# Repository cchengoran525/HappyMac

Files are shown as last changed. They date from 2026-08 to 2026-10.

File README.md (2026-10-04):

<div align="center">
  <picture>
    <source media="(prefers-color-scheme: dark)" srcset="assets/happymac_banner_dark.svg">
    HappyMac — 一枚会陪你熬夜的赛博小生命
  </picture>
</div>

<br>

<div align="center">
  <a href="firmware/happymac_v0/接线清单.md">接线清单</a> |
  <a href="firmware/happymac_v0/元件尺寸台账.md">元件尺寸台账</a> |
  <a href="firmware/happymac_v0/README.md">固件文档</a> |
  <a href="simulator/happymac_sim.html">模拟器</a> |
  <a href="firmware/power_test/power_test.ino">电源测试</a> |
  <a href="hardware/happymac_v01.stl">外壳 STL</a>
</div>

<br>

<div align="center">
  
  
  
  
  
  
</div>

<br>

> 一个吸附在书桌背景板上的赛博小生命体。  
> 它不是工具，它只是在陪着你。

---

## 项目愿景

HappyMac 是一枚桌面像素交互小宠物，形态为冰箱贴。它极度克制、省电，平时几乎沉默，但在你需要的瞬间，能给出精准而温柔的回应。

它有自己的作息，有自己的情绪，会在你深夜还没睡的时候困着眼撑着陪你，也会在你发现它睡着的瞬间上演一出惊慌失措的假装没睡。

没有摄像头，没有麦克风，只有热量和微波的反射——它用这两样东西感受你的存在。

---

## 当前版本：固件 v0.1

- 像素脸表情系统：眉/眼/嘴形态化（挑眉、单眉好奇、wink、开心 ^、皱眉），特殊表情带冷却机制；
- 四阶段深度省电：互动 → 睡眠（呼吸暗脸）→ 90s 断雷达红外独守 → 关屏 / 30min 深度睡眠（SR602 唤醒）；
- 榫卯零螺丝外壳设计定稿：接线与元件尺寸见 [firmware/happymac_v0/](firmware/happymac_v0/)；
- 模拟器与固件 1:1 同步（[simulator/happymac_sim.html](simulator/happymac_sim.html)）。

---

## 硬件架构

```
┌─────────────────────────────────────┐
│  OLED 1.3"  SH1106  128×64          │  ← 像素脸输出
│  ESP32-C3 SuperMini                 │  ← 核心大脑
│                                     │
│  能量分级感知系统                      │
│  ├─ 第一级：SR602 红外传感器           │  ← 哨兵，平时深度休眠
│  ├─ 第二级：LD2410C 毫米波雷达         │  ← 微动/能量/呼吸感知
│  └─ 第三级：LD2450 毫米波雷达          │  ← X/Y 双目标追踪
│                                     │
│  电源管理                            │
│  ├─ TP4056 双输入充电（USB-C + 太阳能）│
│  ├─ SS14 防反流二极管                 │
│  └─ AO3401 高侧开关（雷达电源门控）     │
└─────────────────────────────────────┘
```

### 为什么是两个雷达

LD2410C 和 LD2450 分工不同，互相不可替代：

| 传感器 | 擅长 | 在本项目中的角色 |
|---|---|---|
| LD2410C | 微动能量、呼吸、静止检测 | 判断用户状态（专注/发呆/睡着） |
| LD2450 | X/Y 坐标、多目标追踪、速度 | 判断用户位置和大幅度动作 |

---

## 交互设计

### 伪 3D 视差跟随

HappyMac 的脸由三个层次构成：双眼、鼻子、嘴巴。当用户位置偏移时，三个层次以不同幅度位移，形成视差效果：

```
用户向左移动时：
  鼻子  移动 ±6px   （最前层，移动最大）
  眼睛  移动 ±4px   （中层）
  嘴巴  移动 ±2px   （最后层，移动最小）
```

在 2D 屏幕上实现"它在转头盯着你"的视觉感受，无需 3D 硬件。

### 状态机

```
用户出现         → 慢慢从睡眠中醒来
用户看它         → 惊喜/脸红/眼睛睁大
用户发呆         → 跟着一起发呆，眼神涣散
用户长时间不理   → 打哈欠 → 揉眼 → 亮度渐暗 → 睡眠呼吸动画
深夜用户还在     → 困意动画，但撑着陪你
用户离位         → 目送 → 等待 → 睡着
被发现在睡觉     → 惊醒 → 假装没睡
```

### 睡眠状态的设计原则

全黑 = 坏掉了。HappyMac 睡着时：
- 亮度降至 20%，不是 0
- 慢速呼吸闪烁，表示有生命迹象
- 有人靠近时先有微小反应，再慢慢睁眼

---

## TinyML 训练路径（盲眼剑客计划）

最终产品绝对不包含摄像头，但训练阶段需要视觉作为 Ground Truth。

### 三步走

**第一步：师徒结对（数据采集）**

引入电脑摄像头作为"上帝视角"。MediaPipe 实时识别头部姿态和注视方向，自动打标签；同步记录同一时刻的雷达波形和红外特征。标注过程完全自动，用户正常使用电脑即可完成被动采集。

**第二步：炼丹提取（模型训练）**

将多模态数据输入神经网络，训练两个独立模型：

```
模型 A：位置动作分类
  输入：LD2450 的 X/Y + 帧间变化量
  输出：坐下/站立/前倾/后靠/左偏/右偏
  驱动：HappyMac 脸的朝向

模型 B：用户状态分类
  输入：LD2410C 能量值 + LD2450 速度辅助
  输出：专注/活跃/发呆/睡着/离位
  驱动：HappyMac 表情 + 屏幕亮度
```

两个模型时间尺度不同，分开训练，通过优先级仲裁层协同工作。

**第三步：过河拆桥（边缘部署）**

将模型量化部署进 ESP32-C3，彻底拔掉摄像头。设备仅凭热量和微波反射，凭直觉感受主人的目光。

---

## 当前进度

### 硬件验证
- [x] ESP32-C3 基础环境搭建
- [x] SH1106 OLED 驱动（U8g2）
  - OLED 显示：raw 诊断 + EMA 滤波大字 + 俯视图
  - EMA α=0.55，端到端延迟 ~400ms（雷达 100ms + EMA 200ms + OLED 80ms）
- [x] LD2410C 跑通，微动能量读取正常
- [x] SR602 红外传感器联通
- [x] TP4056 双输入电源管理（USB-C + 太阳能）
- [x] **LD2450 跑通，X/Y 坐标解析正确**
  - 协议符号解码修正（bit15=1→正，bit15=0→负）
  - EMA 滤波（α=0.55）平滑显示
  - 串口 CSV 输出（RADAR 格式，可直接接入采集脚本）
  - OLED 阶段指令支持（电脑通过串口发 `!PHASE` 命令）
  - ⚠️ **X 轴慢漂为硬件固有限制**（见下方"LD2450 X 轴漂移"章节）
- [x] **S3 摄像头固件重写**（s3_camera.ino）
  - AP 模式热点直连（HappyMac-S3 / 12345678）
  - MJPEG /stream + /capture + /status + /control
  - ESP32-S3-EYE 适配（16MB Flash / OPI PSRAM）

### 实测发现

#### LD2450：正确安装后 X/Y 基础功能可用

- **正确安装方式**：PCB 竖直，天线阵列水平（与网上视频一致）
- **方向**：左移 X 减小，右移 X 增大（raw 数据）。OLED 显示已镜像，直觉一致
- **STILL σ≈107mm**：静止时 X 仍有慢漂（LD2450 固有限制，社区公认）
- **SWEEP σ≈222mm**：缓慢左右扫动信号是静止漂移的 2.1x——雷达能区分运动和静止
- **帧间精度**：静止时 ΔX 中位 1-2mm，但长时漂移可达 300-500mm
- **校准**：用户居中时 X≈0，偏左为负，偏右为正

#### LD2410C：静止检测正常，移动检测偏弱

- **Es>0 约 100%**：始终能检测到静止目标
- **Em 响应弱**：默认灵敏度阈值偏高，即使前后移动也难以触发
  - 固件已调高 gate 0-3 灵敏度至 80/100，但改善有限
  - 可能需要 HLKRadarTool app 手动配置

#### USB 供电噪声

- S3 和 C3 插同一台电脑时，C3 雷达数据严重劣化（Yσ 从 29mm → 290mm）
- 解决方案：S3 走 WiFi AP 模式，不与 C3 共用 USB 总线

#### 摄像头-雷达时间戳对齐

- 软件同步（SYNC 握手）未能精确对齐——两个独立时钟，相关分析始终 r≈0
- 需硬件同步：一根 GPIO 线让 C3 触发 S3 录像，或共用同一个外部时钟源
- **但对 TinyML 影响有限**：雷达数据本身（Y 准、X 趋势可用、Es 稳定）已经足够训练

### 已完成（TinyML T1/T1b）
- [x] **TinyML 首次实验（T1b）**：5 类行为分类（离场/静止/左右动/凑近/远离）
  - 视觉 Teacher 自动打标签跑通（MediaPipe + MiDaS）
  - 融合训练在自然行为上 acc=0.811 / F1=0.765（⚠️ 随机切分，诚实值见下条）
  - **发现：Es 数值是头号特征（重要性 0.346）**
  - **教训：协议数据训练的模型迁移到自然场景崩溃（0.32），必须混入自由数据**
  - 详见 `training/README.md` T1 章节
- [x] **对齐数据集诚实评估（2026-08-30）**：详见 `training/README.md`「T1b 对齐数据集与诚实评估」
  - **LOSO 诚实值：acc=0.563 / macro-F1=0.462**——0.811 是同 session 内窗口互相泄漏的假象，引用一律以 LOSO 为准
  - 模型阶梯（树 d3-d5 / RF 10-120t）LOSO 全挤在 0.49-0.56：**瓶颈在特征不在模型**
  - **转头可分性 V1 基线：召回 54%、打字误报 28%**——未达 V2 验收门（>75% / <10%），维持"小幅动作归 STILL"
  - 专注 vs 发呆窗口级互混 ~50%，降级为 Es 长窗氛围调制
  - 分类→检测通道→动画映射已定案（见 `training/README.md` 与固件 README）

### 已完成（T1b v0 部署 + 离线闭环，2026-08）
- [x] **T1b aligned v0 决策树上 C3**：`firmware/happymac_v0` 内嵌 `tinyml_v0_tree_d4.h`，2s 窗 9 特征现场推理，2000ms 确认 + v 特征噪声底
- [x] **静坐误笑治理**：运动证据积分+施密特触发、Y 趋势武装滞回、笑容 600ms 进入延迟+1.5s 保持——真实数据评测误笑率 32.5%→16.6%
- [x] **一次性事件动画系统 + 睡前过渡链**：无人后 打哈欠→揉眼→渐暗→入睡，随时打断（本 README「状态机」愿景第一条落地）
- [x] **离线开发闭环 `simulator/`**：固件逻辑 1:1 JS 移植的等比例 OLED 模拟器 + 16 项场景断言 + 真实数据回放评测——参数改动先离线验证再上机
- [x] **V1 数据体检 + V2 采集规范**：8 会话只读评估（视频倒装/Es 漂移/LATERAL 稀缺/em 报废），规范见 `training/DATA_COLLECTION_V2.md`

### 下一步清单（2026-08-30 更新；半年路线图见 [ROADMAP.md](ROADMAP.md)）

**产品线**
1. [ ] 外壳定稿与组装——解锁 V2 正式采集的前置条件
2. [ ] 电池续航优化（803040 实测十多小时，送人前需再压）
3. [ ] 装壳后阈值现场校准

**数据线**（规范见 `training/DATA_COLLECTION_V2.md`）
4. [ ] 采集固件三处改动：2410 灵敏度 40/40、3 目标 CSV、FW_VERSION 入 meta
5. [ ] V2 正式采集 ≥2 轮（规则+自由+空桌基线，新增 turn_toward / big_sway / still_near-far 动作块）
6. [ ] 转头可分性验收：HEAD 召回>75% 且打字误报<10% 才加新类重训，否则维持"小幅动作归 STILL"
7. [ ] 重训后评测目标：静坐误笑率 <10%

**学术线（Paper 1）**
8. [ ] 双雷达同频干扰定量 AB 测试（3 轮）
9. [ ] 雷达极限探查：5 距离 × 4 行为曲线
10. [ ] RF → MLP 蒸馏 → INT8 量化部署链（与 V2 重训合并执行）

**离线研究（无硬件，随时可做）**
11. [ ] RQ2.3 特征消融：特征组移除 × LOSO（模板 = `training/exp_head_separability.py`）
12. [ ] 窗口长度扫描：1/2/3/5s × LOSO，攻 STILL↔LATERAL 互混
13. [ ] RQ2.1 教师天花板：8 个 V1 会话 mp4 已存 + `t_video_rel` 时间戳，可离线重跑 MediaPipe + keypoint MLP
14. [ ] RQ3.2 pilot：概率 vs 二值表情 A/B（固件加 DETERMINISTIC_MODE 开关，3-5 人 Likert；原型稳定后）

---

## 文件结构

```
HappyMac/
├── README.md
├── new_radar/
│   └── new_radar.ino        # C3 固件：双雷达采样 + EMA 滤波 + OLED + 串口 CSV + 阶段指令
├── s3_camera/
│   └── s3_camera.ino        # S3 固件：AP 热点 MJPEG /stream + /capture + /status + /control
├── CameraWebServer/          # [参考] ESP32-CAM 官方示例，保留备用
├── firmware/
│   └── happymac_v0/         # 产品固件 v0：7 状态机 + 动画 + TinyML 部署 + 睡前链
├── simulator/
│   └── happymac_sim.html    # 网页模拟器：固件逻辑 1:1 移植 + 离线评测闭环
├── training/
│   ├── README.md            # TinyML 管线设计文档 + 11个研究问题 + 3条Paper线
│   ├── DATA_COLLECTION_V2.md # 装壳后正式数据采集规范（V2）+ V1 体检问题追踪
│   ├── config.py            # 全局配置
│   ├── collect.py           # 数据采集（MediaPipe + S3 MJPEG + C3 串口）
│   ├── preprocess.py        # 特征工程 + 标签生成
│   ├── train.py             # RF 验证 → MLP 训练 → INT8 量化 → C 头文件
│   ├── live_test.py         # Webcam + 雷达同步测试
│   ├── s3_test.py           # S3 MJPEG + 雷达同步采集
│   ├── cam_test.py          # 摄像头 + 雷达同步录制（产出 mp4 + csv）
│   ├── full_test.py         # ANSI TUI 完整基准测试
│   ├── radar_bench.py       # 3配置×4阶段雷达基准
│   ├── requirements.txt     # Python 依赖
│   ├── sessions/            # 采集原始数据（.csv）
│   ├── models/              # 训练产物（.npy / .h5 / .tflite / .h）
│   └── bench_results/       # 基准测试结果（.json / .mp4 / .csv / .png）
└── firmware/                # 计划中：主程序（状态机 + 动画）
```

---

## 已知限制与开放问题

### 双雷达同频干扰

LD2410C 和 LD2450 均在 24GHz ISM 频段工作，两台雷达同时开启时会产生**双向电磁干扰**：

| 干扰方向 | 影响 |
|---|---|
| LD2450 → LD2410C | 底噪抬高 3-10dB，远距离检测灵敏度下降 |
| LD2410C → LD2450 | 相位干涉精度下降，X 轴坐标漂移加剧 |

**无法通过软件分时解决：** 两个雷达模块均不支持休眠/唤醒指令。断电重启需要数秒的启动+校准时间，无法在采集周期（100ms）内完成切换。硬件 MOSFET 电源门控（AO3401 + GPIO）是实现真正分时的唯一方案，目前尚未实施。

### X 轴精度与距离的耦合

LD2450 的 X 坐标通过两天线相位干涉计算（天线基线 ~6mm）。X 精度正比于目标距离：
- **< 0.5m：** X 基本为噪声，仅能做"左/中/右"粗分类
- **0.5-1m：** X 可用但漂移显著（σ≈200-1000mm）
- **> 1m：** 角分辨率进入可用区间

### 学术界与实践空白

在 **24GHz 低成本双雷达（<50 元）+ TinyML 跨模态蒸馏（视觉→雷达）** 这个细分领域，目前没有找到直接对标的论文或开源项目：

- LD2410/LD2450 DIY 社区项目均使用纯阈值规则，无 ML
- 60GHz+ 雷达的 TinyML 研究使用高分辨率热力图输入（CNN/Transformer），与本项目的 18 维时序标量特征（MLP）不可比
- 唯一的相近硬件栈论文（DOAJ, 2024）做的是"雷达触发→ESP32-S3 推理人脸识别"，不是行为分类

**本项目从数据采集到模型部署的完整跨模态蒸馏管线（collect.py → preprocess.py → train.py → C 头文件 → C3 推理）为自行设计，无成熟参考架构。**

### TinyML 管线限制

- **MediaPipe 标签质量**：训练标签来自 MediaPipe 面部网格的几何推导（头部位姿、注视方向），不是人工标注。标签存在系统性偏差
- **ESP32-C3 推理性能**：RISC-V 核心无 SIMD 指令扩展，MLP 推理约 <10ms（2 层, <2K 参数），但无法运行 CNN 类模型。如需更复杂模型，需迁移至 ESP32-S3（ESP-NN 加速 42x）
- **数据采集一次性**：相机仅存在于训练期。如果雷达安装位置/朝向改变，需要重新采集数据

---

## TinyML 管线

```
training/
├── config.py           # 全局配置（特征列表、窗口参数、标签定义等）
├── collect.py          # 数据采集：S3 视频流 + C3 串口 + MediaPipe 标注
├── preprocess.py       # 特征工程：滑动窗口 + 18 维特征提取 + 标签生成
├── train.py            # 训练：RF 快速验证 → MLP 训练 → INT8 量化 → C 头文件
├── requirements.txt    # Python 依赖
├── face_landmarker_v2_with_blendshapes.task  # MediaPipe 模型（首次运行时自动下载）
├── sessions/           # 原始采集数据（CSV）
└── models/             # 训练产物（.npy, .h5, .tflite, .h）
```

### 数据流

```
[采集]  collect.py
  S3 MJPEG 视频流 ──→ MediaPipe Face Landmarker ──→ 头部位姿 + 注视方向 + 眼部开合
  C3 USB 串口     ──→ LD2450(X/Y/V) + LD2410C(Em/Es) + SR602 ← 时间对齐 → 一行 CSV

[处理]  preprocess.py
  原始 CSV → 滑动窗口(2s/5s) → 18维特征向量 → 模型A标签(8类) + 模型B标签(8类)
  → X_a.npy / y_a.npy / X_b.npy / y_b.npy

[训练]  train.py
  Random Forest 验证(准确率>85%才继续) → MLP(32→16→softmax) → INT8 量化 → model_*.h
```

---

## 设计哲学

> 它不应该每天都需要你。  
> 但当你抬头的那一刻，它刚好也在看你——  
> 这就够了。

隐私优先：无摄像头，无麦克风，无联网，无云端。感知只发生在本地，数据从不离开桌面。

省电优先：三级唤醒结构，绝大多数时间处于深度休眠。太阳能辅助充电，真正的低打扰存在。

克制优先：去掉所有工具属性（无时钟、无天气、无通知推送），只保留陪伴本身。

---

## 开发环境

- Arduino IDE 2.x + ESP32 Arduino Core
- Python 3.10+（采集脚本）
- MediaPipe（视觉辅助标注）
- Edge Impulse / PyTorch（模型训练）

---

*HappyMac 是一个正在成长中的项目。它现在还不完整，就像所有刚出生的小东西一样。*

---

*本项目为个人非商业开源作品，与 Apple Inc. 无任何关联；Mac 是 Apple Inc. 的商标。*

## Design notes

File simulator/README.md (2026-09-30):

# HappyMac OLED 模拟器

无硬件时的开发验证环境：在浏览器里 1:1 复现 `firmware/happymac_v0` 的完整逻辑链路
（状态机 / 运动证据积分 / Y 趋势武装滞回 / TinyML 决策树 / 动画层），并以
128×64 等比例、整数倍放大渲染 1.3″ SH1106 OLED 画面（旁边附真实物理尺寸预览）。

## 打开方式

直接双击 `happymac_sim.html`（单文件、无依赖、file:// 可用），或：

```bash
open happymac_sim.html
```

## 能干什么

| 用途 | 做法 |
|---|---|
| 调动画/阈值参数 | 改文件顶部 `FW` 常量区（与固件 `#define` 一一对应），确认效果后再手动同步回 `.ino` |
| 验证防抖修复 | 勾选「旧版单帧判定」复现修复前的笑容横跳，关掉即当前固件行为 |
| 回放真实数据 | 「CSV 回放」选 `training/sessions/*.csv`（`t_global,x,y,v,em,es` 格式），真实雷达数据驱动同一套动画 |
| 快速过全状态 | 「场景剧本」：静坐 / 凑近 / 左右探头 / 离开回来（含睡前链）/ 深夜静止 / 贴脸强噪声 |
| 看睡前过渡链 | 「离开→回来」剧本：无人 2.5s 后打哈欠→揉眼→渐暗→入睡，人回来随时打断；串口面板有 `EV,` 日志 |
| 预览配饰方案 | 勾选「半框眼镜」给 OLED 脸戴上 1px 横向半框眼镜（纯渲染层开关，只在 `drawGlasses`；若定稿可把同样画法平移进固件动画层） |
| 与真机对拍 | 串口面板输出与固件相同的 `STATE/ML/POS/RADAR/ANIM` 日志格式 |

## 噪声模型（按实测标定）

- LD2450 实际输出 ≈15Hz（采集 CSV 中位间隔 67ms；旧固件因 OLED 重绘拖慢，处理速率仅 ≈7.6Hz）；
- 静态噪声为慢漂移：边际 σ≈100mm@0.7m，帧间相关 ρ≈0.997，
  对应静坐时滤波步进（140ms）中位数 ≈5.5mm（2026-08-29 实测）；
- 速度 v 静坐时中位数为 0，仅 0.7~3.1% 的行出现 8 的倍数尖峰（跟踪器毛刺）。

## 测试

```bash
node test_sim.js          # 场景断言（固定种子，可复现）
node eval_replay.js       # 真实数据评测：回放全部采集 CSV，对比固件状态 vs 真实动作标签
node eval_replay.js --deglitch   # 同上，但先剔除 v 毛刺帧（对照实验）
node eval_replay.js path/to/session.csv  # 只评单个会话
```

评测口径：still/typing/head_only 期望 IDLE（期间 ACTIVE = 误笑）；
运动类期望 ACTIVE（动作间停顿 IDLE 也算对）；每段动作切换后 2.5s 过渡宽限不计分；
`free_5min` 无期望状态不计分；8 月 13 日后会话优先使用视频对齐后的 `aligned_action`。

从 HTML 中抽出核心逻辑在 Node 里无头运行，覆盖：凑近触发 APPROACH、
静坐 90s 强噪声不横跳（新旧判定对照）、离场 GOODBYE→SLEEP、
TinyML 决策树输出对拍、OLED 帧缓冲冒烟。

页面控制台另有 `__sim.state()` 调试钩子可查运行时状态。

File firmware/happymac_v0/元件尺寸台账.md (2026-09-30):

# 元件尺寸台账（实测/商品页，2026-09-27）

> 建模基准数据。Fusion 中的同名 User Parameters 以此为准；新元件到手先记这里再建模。

| 元件 | 尺寸 (mm) | 关键接口/备注 |
|---|---|---|
| **电池 606090** | 90 × 60 × 6 | 3.7V 4000mAh，**自带保护板** ✓；三线（红+黑+第三线待判别，疑 NTC） |
| **稳压模块** | 25 × 17.5 × 4.5 | VIN 1.8~5.5V（可直挂电池）；OUT 跳线选 5V/4.2V/3.3V；**EN 低=关**；**PS 短接+去LED = 待机 <100µA** ★省电新选项；常规待机几~十几 mA |
| **LD2450** | 40 × 15（厚约4） | 6 天线；串口 256000/8N1（与固件一致）✓ |
| **F5305S 开关模块** | 46 × 25（高约20 含端子） | 13.3g；三组端子共 6 位（IN±/OUT±/控制±） |
| **OLED 1.3" SH1106** | 35.4 × 33.5 × 11.3（含排针） | 活动区 **29.42 × 14.7**；四角安装孔 **内径3/外径4.5**（M3 直接螺丝固定前脸板）✓；孔边距 2.5mm |
| **ESP32-C3 SuperMini** | 18 × 22（排针距 15.24） | USB-C 在上沿；5V/G/3V3 + GPIO |
| **充电+保护二合一** | 28 × 17 | 5V 1A；截止 4.2V；**过放 2.5V / 过流 3A** ✓（安全清单：保护确认） |
| **拨动开关**（全局电源） | 8.5 × 3.5（高7.2） | 0.5A / 30mΩ（负载侧电池电流 ~330mA ✓） |
| **LD2410C** | 22 × 16 | HLK-LD2410C-V1.0；右侧引脚 VIN/DM/DP/GND，主 UART 在 5pin 排针（已接线在用 ✓） |
| **PIR 圆形模块** | **圆板 15.73 宽 × 16.18 高**（近 Ø16），左右两侧各一个 **Ø3.04 半圆缺口**（定位/防转用），底平段宽 13.41；白罩 Ø10 另扣 | **前脸定稿：PIR 叠放在 2410C 正上方（右列），罩从 Ø11 孔凸出朝前**——右列 16+11=27 < 40 ✓ 富余 13mm；**两侧缺口 = 现成的固定点：2 根 **PLA 打印销**（Ø2.9 过盈试装）从前脸板穿过缺口定位圆板（零金属零螺丝）** |

## 打印配合公差（实测标定）

- **公差条实测：0.10mm** → 全部榫卯动配合（滑插槽/卡扣/檐槽）按 **基准 + 0.10mm** 设计；
- 销钉类静配合：按 **-0.05mm 过盈**试探（打印销 Ø2.95 配 Ø3.0 孔起步）；
- 后续所有间隙数字都以 0.10 为基准，不再用通用估算值。

## 前脸布局定稿（2026-09-27）

```
┌──────────────────────────┐
│       ┌─────────┐        │ ← OLED 窗：居中上方，左右等宽
│       │  脸      │        │    （活动区 29.42×14.7，模块 35.4×33.5 藏后）
│       └─────────┘        │
│ ┌─────┐  ┌────────┐      │
│ │2450 │  │ 2410C  │      │ ← 左列：2450 竖放 15×40（PLA 局部减薄 0.8）
│ │ 竖放 │  └────────┘      │   右列：2410C 22×16 + 上方 PIR 罩孔
│ │     │  ⭕ PIR 罩孔      │    （右列总高 ≈40 = 2450 对齐 ✓）
│ └─────┘                  │
└──────────────────────────┘
  前脸 ~110 宽 × ~70 高；ESP32 C 口出右侧壁；
  底边：充电 Type-C + 硬开关长槽（左右拨）
```

## 由实测尺寸触发的设计更新

1. **电池 90×60** → L3 层板扩为 **130×80**（电池 90 + 充电模块 28 + 隔热区 12）；占位值 90×70 作废。
2. **LD2450 是 40×15 横条** → 前脸板横向布置正合适；2mm PLA 直穿或格栅开窗，打印后实测灵敏度。
3. **OLED 四角 M3 安装孔** → 前脸板直接螺丝固定 OLED（无需胶/卡扣），窗口按活动区 29.42×14.7 + 1mm 余量切割。
4. **稳压模块 EN/PS 引脚** → 省电架构新选项：PS 短接 = 稳压级待机 <100µA；EN 可做未来"全系统断电"的固件控制点（当前雷达断电仍由 F5305S 承担）。
5. **充电+保护二合一 + 电池自带保护板 = 双重保护确认**（过放 2.5V / 过流 3A / 充电截止 4.2V）——安全清单闭环 ✓。

## 待补

- [ ] LD2410 尺寸（长宽厚 + 安装孔位）
- [ ] PIR 尺寸（长宽厚 + 透镜中心位置）
- [ ] 各元件安装孔位（有的话），没有就用热熔胶/3M 胶固定

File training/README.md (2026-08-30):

# HappyMac — TinyML 训练管线

> 📋 **下一轮正式数据采集（装壳后）的流程/内容/质量门规范见 [DATA_COLLECTION_V2.md](DATA_COLLECTION_V2.md)**——开工前必读。V1 数据（`sessions/` 2026-08 八会话）体检结论与问题追踪也在这份文档里。

## 问题定义

**跨模态蒸馏（Cross-modal Teacher-Student Distillation）**

- **Teacher（训练期）**：S3 摄像头 + MediaPipe Face Mesh + MediaPipe Pose → 视觉关键点 → 注意力状态标签
- **Student（部署期）**：LD2450 + LD2410C 双 24GHz 雷达 → 18 维时序统计特征 → MLP → 相同语义的行为状态
- **目标硬件**：ESP32-C3 SuperMini（RISC-V 160MHz, 400KB SRAM, 4MB Flash）

训练完成后，摄像头被永久移除。C3 仅凭两个雷达信号进行推理。

## 学术背景

### 与现有工作的关系

| 工作 | 传感器 | 模型 | 与我们的关系 |
|---|---|---|---|
| [dronefreak/human-action-classification](https://github.com/dronefreak/human-action-classification) | 摄像头 + MediaPipe Pose (33 关键点) | Keypoint MLP / CNN / 3D CNN | **借用**：关键点归一化方法、两层标签架构、Keypoint MLP 模式。**不借用**：UCF-101 分类、ResNet50、3D CNN |
| CVPR 2024, *Bootstrapping Radars* | 77GHz 4D 车载雷达 + 摄像头 | CNN + 对比学习 | 跨模态蒸馏范式的参考，但硬件层级和输入维度完全不同 |
| DOAJ 2024, *mmWave-triggered face verification* | 24GHz 雷达 + ESP32-S3 | INT8 MobileFaceNet | 硬件栈最接近的工作（ESP32 + 24GHz + INT8），但做的是人脸识别而非行为分类 |
| ESP-NN 官方基准 | ESP32-C3/S3 | MobileNetV1 | C3 推理性能参考：MLP <2K 参数 <10ms |

### 本项目的学术空白

**24GHz 极低成本双雷达（<50 元）+ TinyML 跨模态蒸馏（视觉→雷达）+ 桌面注意力行为分类**——此组合在文献和开源社区中均无直接对标的先例。

- LD2410/LD2450 DIY 社区项目均使用纯阈值规则，无 ML
- 60GHz+ 雷达的 ML 研究使用高维热力图输入（CNN/Transformer），不与本项目的 18 维标量统计特征可比
- 桌面注意力行为分类（专注/发呆/注意力转移）本身是 HCI 领域关注的问题，但现有方案均依赖摄像头或可穿戴设备

### 已知限制（已写入主 README）

- 双雷达 24GHz 同频干扰：无休眠指令，软件分时不可行，需硬件 MOSFET 门控
- LD2450 X 轴精度正比于距离（<0.5m 基本为噪声）
- Teacher 标签来自 MediaPipe 几何推导，非人工标注，存在系统性偏差
- ESP32-C3 无 SIMD 向量扩展（相比 S3 的 ESP-NN 加速 42x），仅能运行小型 MLP

## 架构

### 数据流

```
[采集]  collect.py
  S3 MJPEG 视频流 ──→ MediaPipe Face Mesh (468关键点) ──→ 头部位姿、眼部开合、注视方向
         │            MediaPipe Pose     (33关键点) ──→ 手腕位置、躯干角度、手部速度
         │
  C3 USB 串口     ──→ LD2450 (X/Y/V) + LD2410C (Em/Es) + SR602 ──→ 时间对齐 → CSV

[处理]  preprocess.py
  原始 CSV → 滑动窗口 (模型A: 2s, 模型B: 5s) → 特征提取 → 标签生成 → .npy

[训练]  train.py
  RF 快速验证 (准确率 ≥85%? → 特征有效性闸门) → MLP (32→16→softmax) → INT8 量化 → model_*.h
```

### 两层标签架构（借自 human-action-classification）

```
PositionClassifier（粗粒度，纯关键点几何规则）
  ├── ABSENT       (无检测)
  ├── LEFT         (head_x < -0.25)
  ├── CENTER       (|head_x| < 0.25)
  ├── RIGHT        (head_x > 0.25)
  ├── LEAN_FWD     (head_z < 0.6)
  └── LEAN_BACK    (head_z > 1.2)

StateClassifier（细粒度，关键点时序特征 × 规则混合）
  ├── ABSENT       (无检测)
  ├── ARRIVING     (到场：head_z 骤降 + 手部出现)
  ├── LEAVING      (离场：head_z 骤升 + 手部消失)
  ├── FOCUSED      (专注：头部微动低 + 手部活跃 + 注视屏幕)
  ├── ACTIVE       (活跃：头部微动高)
  ├── IDLE         (发呆：头部微动低 + 手部停止 + 注视漂移)
  ├── ATTN_SHIFT   (注意力转移：状态短时切换，非持续状态)
  └── LOOK_AWAY    (注意力回到屏幕)
```

### 特征设计（18 维）

详见 `config.py`。核心设计原则：

```
LD2450 位置 (6):  mean/std/slope of X/Y          ← 空间位置 + 趋势
LD2450 速度 (3):  mean/max/fraction of |V|       ← 运动强度
LD2410C 能量 (4): mean/std/max of Em, mean of Es ← 微动 + 反射截面
组合特征 (6):     xy_corr, es/y_ratio, 能量尖峰 ← 传感器融合 + 距离归一化
红外 (1):         ir_present_mean                ← 二值存在性确认
```

关键创新特征：`es_div_y_mean`（单位距离反射能量）——理论依据为雷达方程 Pr ∝ σ/R⁴，除以 Y 后近似消去距离衰减，仅留目标雷达截面 σ 的贡献。可用于间接感知目标朝向变化（正脸 vs 侧脸 RCS 差 3-6dB）。**此特征在 24GHz 雷达上的有效性尚未被实验验证。**（关口 2, 预估成功率 ~45%）

### 状态检测的生理依据（注意力转移）

不直接测量"头转了多少度"，而是检测注意力转移的全身生理伴随反应：

```
注意力转移过程中：
  1. 手部微动停止     → Em 在 0.5-1s 内骤降（打字/鼠标停止）
  2. 身体姿态微调     → X/Y 微动 + Em 小尖峰（身体往目标方向偏转）
  3. 心率变异性变化   → Es 的微振动频率偏移（副交感→交感切换）
                        ⚠️ 24GHz 雷达能否感知此信号未经验证
  4. 呼吸模式变化     → Es 在 3-5s 窗口上的低频成分变化
```

这些信号在 18 维特征空间中形成了一个与其他状态不重叠的 cluster——这是 ML 能够分类的前提，也是本项目最核心的待验证假设。

## 文件说明

```
training/
├── README.md           ← 本文件
├── config.py           全局配置（修改参数无需改其他文件）
├── collect.py          数据采集主脚本
├── preprocess.py       特征工程 + 标签生成
├── train.py            RF 验证 → MLP 训练 → INT8 量化 → C 头文件
├── requirements.txt    Python 依赖
├── .gitignore          排除 __pycache__、模型文件
├── sessions/           原始采集 CSV（.gitignore）
├── models/             训练产物（.npy / .h5 / .tflite / .h）
└── face_landmarker_v2_with_blendshapes.task  # 首次运行时自动下载
```

## 用法

```bash
# 1. 安装依赖
pip install -r requirements.txt

# 2. 采集数据（需要 S3 摄像头 + C3 雷达同时连接）
python collect.py --duration 600          # 采集 10 分钟
python collect.py --duration 1800 --no-display  # 30 分钟，无预览窗

# 3. 特征工程
python preprocess.py                      # 处理所有 sessions
python preprocess.py --session sessions/2026-08-05_14-32.csv  # 单文件
python preprocess.py --vis                # 可视化特征分布

# 4. 训练
python train.py --rf-only                 # 仅 RF 验证（先跑这个！）
python train.py                           # 完整训练（RF+MLP+量化）
python train.py --model a                 # 仅训练模型 A
python train.py --export                  # 导出 C 头文件

# 5. 部署到 C3
# 将 models/model_a.h 和 model_b.h 复制到固件目录
# 在 new_radar.ino 中 #include 并使用 TensorFlow Lite Micro 推理
```

## T1 TinyML 首次实验（2026-08-13）

### 结论：可行性绿灯 + 两个关键教训

| 实验 | 结果 | 含义 |
|---|---|---|
| 协议数据 RF（3折） | acc=0.778, F1=0.708 | 信号存在，特征修复后显著提升 |
| 自由数据 RF（3折） | acc=0.681, F1=0.625 | 自然数据更难（标签噪声+行为混合） |
| 融合数据 RF（3折） | acc=0.683, F1=0.626 | — |
| **迁移：协议→自由** | **acc=0.323** | **表演数据训练的模型在真实场景崩溃** |
| **融合→自由** | **acc=0.811, F1=0.765** | **加自然数据后翻倍** |

### 关键发现

1. **Es 数值是头号特征**（重要性 0.346，超 slope_Y 三倍）——"LD2410C 静止能量数值是姿态弱特征"的假设被训练直接验证
2. **X 特征修复**：删除 slope_X（方向抵消）、slope2_X（零方差）、X_reversals（阈值失效），改用 |slope_X| → 协议数据 F1 从 0.537 提升至 0.708
3. **协议数据 ≠ 自然行为**：只用脚本表演数据训练，迁移到自由行为时崩溃（acc 0.323）。自然数据必须进入训练集
4. **视觉 Teacher 自动打标签跑通**：MediaPipe（存在+横向）+ MiDaS（纵深）实时标注，3408 次自动标签切换（0.1s/次，需平滑）
5. **剩余硬骨头**：STILL↔LATERAL 混淆（互混 300+ 窗口），APPROACH 精度弱（74/170）

### 数据管线

```
collect_session.py   协议数据采集（9 阶段 × 3 session）
collect_free.py      自由数据采集（视觉 Teacher 自动打标签）
features_t1b.py      特征工程（9 特征，支持协议+自由融合）
train_compare_t1b.py 训练对比（proto/free/fused/迁移）
```

特征集（9 维）：|slope_X|, slope_Y, std_X, std_Y, mean_Es, std_Es, mean_abs_V, max_abs_V, Es_edge

### 下一步

- [ ] 再采 2-3 次自由数据（每次 5 分钟，提升自然场景精度）→ 已并入 [DATA_COLLECTION_V2.md](DATA_COLLECTION_V2.md) V2 轮次计划
- [ ] 攻 STILL↔LATERAL 混淆（窗口长度调优 / 深度特征增强）
- [ ] RF → MLP 蒸馏 → INT8 量化 → C3 部署
- [x] ~~补 APPROACH 数据~~（2026-08-30 定案：APPROACH/RETREAT 由 Y 趋势规则承接，ML 不做这两类，见「分类 → 检测通道 → 动画」）

> **2026-08-30 评估修正**：本节的 3 折随机切分指标系统性高估（同 session 窗口互相泄漏），
> 引用请以下节 LOSO 诚实值为准；转头类实验结论见下节。

---

## T1b 对齐数据集与诚实评估（2026-08-30）

### 数据集与评估方法

`t1b_aligned_X/y/groups.npy`（`align_all_sessions.py` 产出）：5 个规则协议 session +
3 个自由 session，视频对齐标签（`aligned_action`），4744 窗 / 9 特征 / 2s 窗 0.5s 步进。
类别分布：STILL 2340 / LATERAL 945 / ABSENT 542 / RETREAT 523 / APPROACH 394。

评估一律用**留一会话交叉验证（LOSO）**：每次留出整个 session 做测试。
随机切分（本文件 T1 节的 0.811/0.765、`train_compare_t1b.py` 旧报告）因同 session
窗口互相泄漏而系统性高估，**引用一律以 LOSO 为准**。

### LOSO 主结果（RF 120 树，tinyml_v0_aligned_report.json）

| 指标 | 数值 |
|---|---|
| session LOSO acc / macro-F1 | **0.563 / 0.462** |
| 规则数据训练 → 自由数据 | 0.408 / 0.245 |

最难折都是自由 session（acc 0.46-0.50）——自然行为混合 + Teacher 标签噪声是主要误差源。

### 模型阶梯（tinyml_v0_model_ladder_report.json）

树 d3/d4/d5、RF 10/20/120 树的 LOSO 全部挤在 acc 0.49-0.56 / macro-F1 0.42-0.46：
**模型容量不是瓶颈，9 特征的信息上限就在这里**——提升精度只能靠特征/窗口工程，
不能靠换大模型。上机选 d4 决策树（25 节点 / 3.8KB，`tinyml_v0_tree_d4.h` 已进 v0 固件）：
RF 精度无优势且进不了 C3。

### 逐类可靠度（LOSO 混淆矩阵，RF 120 树）

| 类 | 召回 | 主要混淆去向 | 结论 |
|---|---|---|---|
| STILL | 68% | →RETREAT 261 / →APPROACH 151 | ML 可用 |
| LATERAL | 60% | →STILL 223 | ML 可用，配规则积分器或门兜底 |
| ABSENT | 58% | →LATERAL 102（无人判在动） | ML 不可用，存在性走 SR602/规则 |
| RETREAT | 25% | →STILL 196 | ML 不可用，Y 趋势规则顶 |
| APPROACH | 18% | →STILL 146 | ML 不可用，Y 趋势规则顶 |

### 转头可分性实验（exp_head_separability.py，2026-08-30）

head_only 单独成类（STILL/TYPING/HEAD 三分类）× 现有 9 特征 × 2s 窗 × LOSO（5 会话 1185 窗）：

```
HEAD 召回 54.0%；TYPING→HEAD 误报 28.0%；STILL→HEAD 误报 9.1%
树深度 3-6 扫描：acc 52-54%，无改善
```

**结论：转头在当前 9 特征下不可分。** 此结果是 V2 验收门
（[DATA_COLLECTION_V2.md](DATA_COLLECTION_V2.md) §7②：召回 >75% 且打字误报 <10%）的
V1 基线；V2 的调敏 em + 3 目标 + turn_toward 数据是翻案机会，不达标则维持
"小幅动作归 STILL"。翻案方向是**新特征**（Y 微动谱 / Es 频域分量 / 更长窗口），
不是更多同类数据。

### 专注 vs 发呆（窗口级不可分，降级）

still/typing 窗口级互混 ~50%（STILL→TYPING 170 窗 / TYPING→STILL 85 窗）。
Es 组间差（typing 72.8 vs still 63.9，见 `docs/REPORT_radar_characterization.md`）
只在分钟级平均下成立。**定案：不作为分类目标；用 30-60s 长窗 mean_Es 驱动
眨眼频率 / 呼吸节奏 / 亮度等"氛围"参数（慢通道，不追求实时）。**

---

## 分类 → 检测通道 → 动画（定案）

原则：每条动画只押在**对该信号最可靠的检测通道**上；ML 只做混淆矩阵证明它做得到的事。
LOSO 0.563 意味着误分类是常态——「ML 输出只是期望、动画层负责容错」从设计哲学升级为工程必需。

| 人体活动 | 检测通道（定死） | 动画 |
|---|---|---|
| 离场 / 回来 | SR602 + 雷达目标存在，500ms 防抖、8s 进睡眠（纯规则） | GOODBYE → SLEEP；WAKING 渐睁眼 |
| 静止在场（含打字） | ML STILL，2s 窗 + ~2000ms 确认 | IDLE：慢眨眼、正常跟随、静止注意力漂移 |
| 横移 / 大动作 | ML LATERAL + 规则运动积分器**或门**；方向由 slope_X 符号给出，不进 ML | ACTIVE：睁大眼 + 微笑（600ms 进入延迟 + 1.5s 最短保持） |
| 凑近 / 远离 | LD2450 Y 趋势规则（15mm/140ms + 重武装滞回），ML 仅放行 | APPROACH / RETREAT 短事件动画，播完回 IDLE 不锁表情 |
| 左中右位置 | X 相对校准基线 + 双阈值滞回（快通道，不进 ML） | 连续 face_look ±24px + 几何视差（鼻 7 / 嘴 4 / 眼距收缩 14px） |

两条**连续调制通道**（不占状态）：

1. **mean_Es 长窗（30-60s）** → 眨眼频率 / 呼吸节奏 / 亮度微调（氛围）
2. **mean_abs_V（8mm/s 噪声底以上）** → 跟随增益 / 眼高，ACTIVE↔IDLE 连续过渡

**表情相邻原则**：互相混淆的类，动画必须表情相邻——误分类在用户眼里是性格化的犹豫，不是错误。

- STILL↔LATERAL 互混最重 → IDLE/ACTIVE 只差眼高/嘴型（600ms 延迟 + 1.5s 保持已对）
- APPROACH 混入 STILL → APPROACH 是短事件、播完回 IDLE，永不锁表情
- ABSENT 幻觉 19% → SLEEP 由 8s 持续无目标的时间常数吸收
- LATERAL 方向错误 → face_look 限速缓动天然容错（慢慢转过头再修正）

**明确不做**：HEAD 类（V2 验收前）、窗口级 FOCUSED/IDLE、Em 参与任何判定、
stand_sit 独立类（语义已被 presence 边沿的 GOODBYE/WAKING 覆盖）。
零 ML 新动画候选：**「被抓到偷看」**（face_look 已偏侧 + 人回中边沿触发一次性微表情）、
深夜困意（时钟驱动，不占雷达分类）。

---

## 双模型架构：位置（模型 A）+ 状态（模型 B）

### 设计目标

T1b 的 5 类模型回答"人在干嘛"（状态），驱动表情状态机。还需补模型 A 回答"人在哪边"（位置），驱动脸朝向。**两个模型共享雷达数据流，不同时间尺度，独立输出。**

### 模型 A：位置分类（快通道，0.5-1s 窗口）

```
输入特征（3 维，全部是"相对量"）：
  X_rel    = mean_X(1s) − median_X(10s 滚动基线)   ← 漂移免疫
  |slope_X| (1s 窗口)                               ← 是否在横移
  std_X    (1s 窗口)                                ← 横移幅度

输出：LEFT / CENTER / RIGHT（3 类软输出，非硬分类）
方向：slope_X 符号直接给出，不需要 ML 学
```

**漂移与几何偏移的解法**：
- X 绝对漂移（128mm/30s）→ 用滚动基线归一化，只学相对偏移
- 摄像头在雷达右侧的几何偏移 → 视觉 Teacher 的 L/C/R 标签相对"校准参考点"定义，不相对画面中心

**视觉 Teacher 校准协议**（collect_free.py 将加入）：
```
采集开始：用户坐雷达正前方 10 秒
→ 记录脸中心 x 的中位数 = 图像坐标系 CENTER 参考点
→ 后续标签：脸 x 相对参考点 ± 阈值 → L/C/R
→ 每 session 重新校准，吸收坐姿微变和几何偏移
```

### 模型 B：状态分类（慢通道，2s 窗口）

T1b 已实现：ABSENT / STILL / LATERAL / APPROACH / RETREAT，融合训练 F1=0.765。

### 仲裁层与动画层（解耦设计）

```
雷达 → 特征 → 模型A [P(L),P(C),P(R)] + 模型B [5类概率]
              ↓                          ↓
        target_angle = P(R)×30° − P(L)×30°   （期望朝向角，可模糊）
              ↓
        动画层（死区 + 平滑限速 + 几何视差）：
        face_target += (desired − target) × 0.08
        face += clamp((target − face) × 0.06, ±0.55px)
        整脸共同平移 + 眼距收缩 + 鼻/嘴相对偏移
              ↓
        OLED 20Hz 重绘
```

**核心原则**：
1. **ML 输出是"期望方向"**，允许模糊、允许概率——动画层负责"怎么转过去"，一定平滑有惯性
2. **不写死边界**：位置是连续姿态空间，脸经过软边界时"犹豫"地停在两区之间，不跳变
3. **缺陷变性格**：雷达的噪声/漂移/延迟经低通滤波后成为脸的"注意力飘忽"和"想了想才转头"——这正是 Paper 3 不完美感知设计的具体数学实现
4. **仲裁优先级**：ABSENT > 状态转换 > 位置。人从右侧走过 = 模型B 说 LATERAL + 模型A 说 RIGHT + slope 符号说往左 → 脸先转向右，再跟着左移（伪3D视差跟随）

### 模型 A 实施状态

- [x] C3 上先接入 Model A v0：LD2450 X 相对校准中心的 LEFT/CENTER/RIGHT 分区
- [x] 使用进入/退出双阈值滞回，避免边界附近左右抖动；动画仍使用连续 look 值
- [ ] collect_free.py 加校准段（10 秒记录 ref_x）+ 输出 L/C/R 标签
- [ ] 特征脚本加 3 维位置特征（X_rel, |slope_X|, std_X）
- [ ] RF 训练 3 类（预期高于 5 类状态模型）
- [x] C3 动画层实现（死区 + 限速跟随 + 几何视差 + 12.5Hz OLED）

## 关键验证关口

| # | 关口 | 预估成功率 | 状态 |
|---|---|:---:|---|
| 1 | LD2450 X 轴可区分左中右 (≥1m) | 85% | ✅ 已验证（趋势可用，绝对值漂移） |
| 2 | LD2410C Es 可感知注意力转移 | ~45% | ❌ 证伪（朝向无信号）；✅ Es 数值是姿态特征 |
| 3 | 双雷达干扰在 ML 中可容忍 | 60% | ⏳ 待 AB 对照（V2 以 es 基线登记控制，不消除） |
| 4 | MediaPipe 产出可靠标签 | 75% | ✅ 跑通；Teacher 标签噪声是自由 session 难折的主因之一 |
| 5 | RF 特征可分性 | 50% | ⚠️ 随机切分 F1=0.765 → **LOSO 诚实值 0.462**；瓶颈在特征不在模型 |
| 6 | C3 MLP 推理达标 | 95% | ⏳ d4 决策树已上机；MLP/INT8 蒸馏待做 |
| 7 | 最终产品可用 | 55% | ⏳ MVP 故事线 81% 成立；误笑率 16.6% → 目标 <10% |
| 8 | 转头（head_only）可分 | — | ❌ V1 基线证伪（召回 54% / 打字误报 28%）；V2 验收门 >75% / <10% |

## 参考

- [dronefreak/human-action-classification](https://github.com/dronefreak/human-action-classification) — 两层标签架构 + 关键点归一化 + Keypoint MLP 参考实现
- [HLK-LD2450 协议手册](http://r0.hlktech.com/download/HLK-LD2450-24G/) — X/Y 符号编码为 bit15=1→正（非标准补码）
- [ESP-NN](https://github.com/espressif/esp-nn) — ESP32-S3/C3 推理性能基准
- Hao et al., "Bootstrapping Autonomous Driving Radars with Self-Supervised Learning", CVPR 2024 — 跨模态雷达-视觉蒸馏参考范式

## 研究方向与开放问题

以下问题横跨三个子领域（传感系统 / 跨模态蒸馏 / 交互设计），按可操作性和发表潜力排列。标注了每个问题的研究方法建议和预期产出类型。

### 进度账本（2026-08-30 校准）

总判断：**工程完成度 >> 科学完成度**。管线 / 固件 / 模拟器 / 回放评测全通，
但三个方向各自缺的受控实验一个都还没正式跑。论文引用指标一律以 LOSO 为准。

| RQ | 状态 | 缺什么 |
|---|---|---|
| 1.1 X-距离函数 | ⏳ 半闭环 | 5 距离 × 3 重复扫描；已有单距离漂移定量化（σ=128mm/30s @0.7m）；V2 的 still_near/far 是起点 |
| 1.2 Es-朝向 | ✅ 闭环 | 无——朝向证伪（\|r\|<0.12）+ Es 姿态特征阳性副产品，可直接成文 |
| 1.3 ERRR | ❌ 未动 | 30+ 次诱发事件采集 |
| 1.4 干扰 AB | ❌ 未动 | 单/双雷达 × 3 天线间距对照（V1 两雷达同开，无基线） |
| 2.1 教师天花板 | ❌ 未动 | **可离线**：8 个 V1 会话 mp4 已存 + `t_video_rel` 可重对齐，重跑 MediaPipe + keypoint MLP |
| 2.2 损失分解 | ❌ 未动 | 教师半边可离线；学生半边已有（LOSO 0.563）；量化半边待 INT8 |
| 2.3 消融 | ❌ 未动 | **可离线**：`exp_head_separability.py` 即模板 |
| 2.4 C3 延迟能耗 | ❌ 未动 | 待 MLP 蒸馏 + INT8 上机 |
| 3.1-3.4 | ❌ 未动 | 最便宜是 3.2 pilot：`DETERMINISTIC_MODE` 编译开关 + 3-5 人 Likert |

最快成文路径 = **Paper 1**（只缺受控数据，不缺分析与写作框架，已有
[docs/REPORT_radar_characterization.md](../docs/REPORT_radar_characterization.md) 作素材）；
产品优先则先做窗口扫描 + eval_replay 指标闭环。

---

### 方向一：低成本雷达信号表征（Sensing Systems）

> 顶会：SenSys, IPSN, Ubicomp (IMWUT Note)

**RQ1.1 — LD2450 的 X 轴精度-距离函数是什么样的？**

这是最基础的问题。在不同目标距离（0.3 / 0.5 / 1.0 / 1.5 / 2.0 m）下，记录静止人体目标的 X 坐标标准差（σ）。预期得到一个非线性曲线：σ ∝ 1/distance²（来自相位干涉的几何稀释）。

**方法：** 多距离定点实验，每距离 60 秒 × 3 次重复。对照组：单雷达 vs 双雷达同时开（量化干扰对 X 精度的影响）。

**产出：** 4 页 note。这是文献中首次对 LD2450 X 轴的系统表征。阴性结果（"X 精度在任何距离都不够用"）和阳性结果（"≥1m 后精度进入可用区间"）同样成立。

---

**RQ1.2 — LD2410C 的 stationary energy (Es) 对目标朝向敏感吗？**

用一个可旋转的平板/人体模型或真实受试者在固定距离（1m）处，从正对（0°）旋转到侧对（90°），记录 Es 值的变化曲线。理论预测：Es ∝ RCS（雷达截面），RCS 随朝向在 3-6 dB 范围内变化。

**方法：** 10°步进旋转实验，每角度 20 秒。同样需要双雷达/单雷达对照组，排除干扰导致 Es 波动。如果用真人受试者，用 MediaPipe head_yaw 做朝向的 Ground Truth。

**产出：** 如果 Es 对朝向有明显响应（>2dB 动态范围），这是这个方向最关键的阳性发现——"24GHz 静止能量可以感知目标朝向"是一句此前没人用实验确认过的陈述。如果没有响应，这是同等重要的阴性发现，定义了 LD2410C 的物理极限。

---

**RQ1.3 — 事件相关雷达响应（Event-Related Radar Response, ERRR）**

注意力转移事件（手机响、有人进房间、HappyMac 突然动作）前后的雷达信号在全维度（X/Y/V/Em/Es）上是否表现出统计显著的变化？

**方法：** 重复诱发注意力转移 30+ 次，画事件相关的时间序列图（±5s 窗口，类似 EEG 的 ERP 分析）。配对 t 检验比较事件前 2s 基线 vs 事件后 2s 响应窗。

**产出：** 如果有显著响应——这是最强的论文实验结果，直接证明了雷达能"感知"一个认知事件。如果不显著——同样是有价值的结论：注意力转移可能不在 24GHz 雷达的可感知物理特征范围内。"ERRR" 这个缩写没人用过，你可以命名。

---

**RQ1.4 — 双 24GHz FMCW 雷达同频干扰的量化表征**

两个雷达同时开启时，(a) LD2410C 的底噪、(b) LD2450 的 X/Y 精度劣化、(c) 幽灵目标的出现频率——各是多少？

**方法：** 单雷达 vs 双雷达对照实验（拔掉 2410 VCC 作为单雷达基线）。三个因变量：(a) LD2410C 的 Em/Es 在"空房间"条件下的值（底噪），(b) LD2450 X 坐标静止目标的 σ，(c) Target 槽位 T1/T2 的假目标活跃率。两雷达在 3 种相对距离（10cm / 30cm / 50cm 天线间距）下分别测试。

**产出：** 这是 DIY 社区里被反复讨论但没人系统测过的问题。数据本身就是贡献。

---

### 方向二：跨模态蒸馏与 TinyML 部署（Embedded ML / Cross-modal Sensing）

> 顶会：Ubicomp (IMWUT), PerCom, AAAI tiny paper track

**RQ2.1 — 视觉 Teacher 能多准地识别桌面注意力状态？（天花板实验）**

纯用视觉关键点（Face Mesh 468 点 + Pose 33 点），训练一个 keypoint MLP 做 6-8 类桌面注意力状态分类。准确率 = Teacher 能力天花板 = Student 的理论上界。

**方法：** 借鉴 human-action-classification 的 keypoint 管线（50→128→64→n MLP），用规则标签做 baseline，与 ML 训练标签做对比。分析 misclassification 的来源（哪些状态之间容易混淆？人是如此还是模型也是如此？）。

**产出：** Teacher 准确率如果 >90%——标签体系可靠，天花板足够高，Student 有追赶空间。Teacher 准确率如果 <75%——说明"桌面注意力状态"即使摄像头也分辨不好，雷达不是问题，标签体系需要重新设计。两种结果都导向可发表的讨论。

---

**RQ2.2 — 从视觉 Teacher 到雷达 Student 的跨模态蒸馏中，多少信息损失来自模态 gap，多少来自模型压缩？**

分解信息损失路径：视觉 Teacher（FP32 MLP）→ 雷达 Student（FP32 MLP）→ 量化（INT8 MLP）。每一步的精度损失各是多少？

**方法：** 三步对比实验：(a) 视觉 keypoint → 同类标签的 MLP 准确率，(b) 雷达 18 维特征 → 同类标签的 MLP 准确率，(c) 同 (b) 但 INT8 量化后。Δ1 = (a)-(b) = 模态 gap；Δ2 = (b)-(c) = 量化损失。

**产出：** 大部分跨模态蒸馏论文只报告了总精度差。你把这个差分解成两个可独立优化的部分——这是一个方法贡献。

---

**RQ2.3 — 18 个雷达特征中，哪些真正有贡献？（消融实验）**

逐个移除特征/特征组，观察精度变化。同时报告 Random Forest 的特征重要性排序。

**方法：** Ablation study:(i) 只用 LD2450 所有特征，(ii) 只用 LD2410C 所有特征，(iii) 移除所有组合特征只留基础统计特征，(iv) 移除 es_div_y_mean 孤立测试其单独贡献。每组跑 5 折交叉验证。

**产出：** 特征重要性排序 + 最小特征子集（可能 top-10 就够）。如果 es_div_y_mean 是 top-3 重要特征——验证了我们在雷达方程上的理论推导。如果它在 bottom-3——理论推导有问题，值得一篇短论文讨论为什么。无论正负，回答了一项可验证的科学问题。

---

**RQ2.4 — MLP 在 ESP32-C3 上的推理延迟和能耗**

实测 INT8 量化后的 MLP（32→16→softmax）在 C3 上的单次推理时间、内存占用、功耗。

**方法：** `micros()` 计时 + 示波器测 GPIO 翻转功耗脉冲。和 ESP-NN 基准数据对比，验证 <10ms 的预期是否成立。

**产出：** 基准数据本身不是主要贡献，但在论文里是必须有的 Engineering Validation 段落。

---

### 方向三：不完美感知的交互设计（HCI / Design）

> 顶会：CHI, DIS, TEI

**RQ3.1 — "Attention-Oriented Sensing"：传感器不需要测到眼睛方向就能感知注意力转移——这个设计原则如何系统化？**

将你在 HappyMac 上形成的方法论抽象为一个可推广的设计框架：(1) 拒绝"精确测量"的传感器选择标准，选"对状态切换最敏感"的传感器；(2) 用传感器融合（双雷达）弥补单传感器的物理盲区；(3) 用概率状态空间替代确定性阈值。

**方法：** 除了 HappyMac 之外，找一个或两个其他场景（比如：教室座位上的注意力监测、会议室里的参与度感知），用同样原则做纸上设计推演，展示框架的可迁移性。

**产出：** 设计方法论文。CHI/DIS 的 full paper。这是三个方向里最不需要技术完成度的——你主要卖的是一个原创的设计概念，原型是证据但不是全部。

---

**RQ3.2 — 概率驱动的表情状态机 vs 二值检测的表情状态机：用户体验有区别吗？**

同一个人面对两种模式：(a) 确定性模式——"人在左边 → 脸看向左"，(b) 概率模式——"左 60% / 中 30% / 右 10% → 脸往左偏但有点犹豫"。用户感受到的"生命感"有差异吗？

**方法：** 小规模用户研究（3-5 人即可做 pilot）。在限定场景下做 within-subject A/B 对比，用 Likert 量表 + 开放式访谈收数据。这不是找"显著性"——pilot study 在 HCI 里够发 workshop 或作为 full paper 的 preliminary evidence。

**产出：** 如果概率模式被评价为"更像活的"——你不是在报告一个工程优化结果，你是在报告一个交互设计原则。这条原则比 HappyMac 这个产品活得久。

---

**RQ3.3 — "不完美感知"如何影响用户对设备的信任感和陪伴感？**

让受试者使用 HappyMac 一段时间（哪怕 10 分钟），然后告诉他们"它偶尔会看错方向，因为它没有摄像头，只有一个很便宜的雷达芯片"。他们说"它更像宠物了"还是"它不好用"？

**方法：** 准结构化访谈。不给受试者预设"你觉得它像宠物吗"——让他们自己找词描述。你只做转录和聚类分析。

**产出：** 定性的用户反馈。如果"雷达感知的不完美→更像宠物"这个猜测被受试者自发表达出来——你在 CHI 的 contribution 就成立了。因为"让传感器故意保持不精确"这个主张在此之前没有实验证据。

---

**RQ3.4 —（如果你做多传感器对比）— 用户在不知道传感器类型的情况下，对摄像头、雷达、ToF 驱动的同一交互的感受有何不同？**

三种传感器实现同一个"桌面宠物"交互（摄像头版/雷达版/ToF版），用户盲测，记录他们对"监视感""生命感""舒适度"的描述。

**方法：** 需要做三个原型变体。工作量大，但如果做出来——CHI 级别的 full paper。

**产出：** 实验证据支持"传感器选择是设计决策，不是纯粹的技术决策"。这是 HCI 社区喜欢的 argument。

---

### 路线建议

```
现在 → MVP（数据到手）：
  RQ1.1 + RQ1.2 + RQ1.3 的数据一锅采集，一套实验回答三个问题
  → 决定哪些 RQ 有阳性信号

MVP 之后 → Demo 之前：
  RQ2.1（天花板实验）决定是否值得往下做
  RQ2.3（消融实验）指导特征精简化

Demo 之后 → 论文：
  选一条主线路：
    - 信号表征主线 (Paper 1): RQ1.1 + RQ1.2 + RQ1.4
    - 跨模态蒸馏主线 (Paper 2): RQ2.1 + RQ2.2 + RQ2.3
    - 交互设计主线 (Paper 3): RQ3.1 + RQ3.2 + RQ3.3

  每篇论文只需回答 2-3 个 RQ 即可成立
  不必全部做完——选实验结果最好的那条线往里深挖
```

### 下一步行动清单（2026-08-30 排定）

**A. 离线可做（无硬件，随时）**
1. RQ2.3 特征消融：特征组（纯 LD2450 / 纯 LD2410C / 去 Es_edge）× LOSO，模板 = `exp_head_separability.py`
2. 窗口长度扫描：window ∈ {1, 2, 3, 5}s × LOSO，专看 STILL↔LATERAL 互混变化
3. RQ2.1 教师天花板（离线）：对 8 个 V1 会话 mp4 重跑 MediaPipe，用 `t_video_rel` 对齐 `aligned_action`，训 keypoint MLP（>90% = 标签可靠有追头空间；<75% = 标签体系需重设计——两种结果都可发表）
4. RQ2.2 量化半边：RF → MLP 蒸馏 + INT8 仿真，Python 侧先量出 Δ2

**B. 需要硬件（与 V2 采集同场搭车）**
5. Paper 1 补实验日：距离扫描（0.3/0.5/1.0/1.5/2.0m × 静止/慢扫 × 3 重复）+ 干扰 AB（拔 2410 供电基线 × 3 天线间距），分析脚本现成
6. 补自由数据已并入 V2 轮次计划（[DATA_COLLECTION_V2.md](DATA_COLLECTION_V2.md)）

**C. 需要真人（原型稳定后）**
7. RQ3.2 pilot：固件加 `DETERMINISTIC_MODE` 编译开关（硬边界取概率路径），3-5 人 within-subject Likert + 开放式访谈

优先级：目标最快成文 → A1/A2 → B5（Paper 1 投入产出比最高，RQ1.2 已闭环可先写）；
目标 MVP → A2 + eval_replay 指标闭环 → V2 重训。A 组与产品线完全共用，无选边成本。

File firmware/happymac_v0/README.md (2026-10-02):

# HappyMac v0.1 动画固件

这是第一版产品固件，目标是先完成一个可以装入 3D 打印外壳、持续运行并展示完整生命感的原型。

## v0.1 更新（2026-09-27）

- 像素脸表情系统：眉/眼/嘴形态化（挑眉、单眉好奇、wink、开心 ^、皱眉），特殊表情带冷却机制；
- 五阶段深度省电：互动 → 久坐 5min 犯困渐暗（雷达常开）→ 睡眠（呼吸暗脸）→ 90s 断雷达红外独守 → 关屏 / 20min 深度睡眠（SR602 PIR 唤醒）；
- 2410 存在判定带能量门槛：空房底噪（es≈8~10）不再被当成"有人"，杜绝幽灵唤醒；
- 串口命令：`!CAL` 重校准、`!DEBUG` 调试层、`!FLIP` 雷达左右翻转、`!PWR` 查询电源状态、`!STYLE` 切换脸型（经典初版 default / 一个戴眼镜的朋友版，NVS 记忆）；
- 榫卯零螺丝外壳适配：接线见 [接线清单.md](接线清单.md)，元件尺寸见 [元件尺寸台账.md](元件尺寸台账.md)；
- 适配 1.3″ SH1106 128×64 I2C OLED（3.3V 供电，I2C 地址 0x3C）。

这一版的重点不是证明 TinyML 精度，而是完成：

- OLED 像素脸；
- 睡眠、醒来、待机和动作反馈；
- 左右跟随和伪 3D 视差；
- 雷达、动画和外壳之间的完整闭环；
- 为之后接入 Model A / Model B 保留稳定接口。

产品固件和研究采集固件分开。v0 不使用摄像头；当前已接入一个试验性的
T1b `tree_d4` TinyML 状态模型，同时保留双雷达和 SR602 规则兜底。

## 一、整体架构

最终采用三层结构：

```text
传感器 / TinyML 模型 / 规则系统
              ↓
       PerceptionOutput
              ↓
        StateMachine
              ↓
       AnimationLayer
              ↓
             OLED
```

核心原则：

1. 位置模型只回答“人在哪里、脸应该看向哪里”。
2. 状态模型只回答“当前是什么状态、应该用什么情绪表现”。
3. 动画层负责平滑、惯性、视差、亮度和一次性事件动画。
4. 不让两个模型直接竞争一个最终状态。

## 二、当前状态

| 状态 | 进入条件 | 动画表现 |
|---|---|---|
| `SLEEP` | 连续 8 秒没有目标 | 闭眼、低亮度呼吸，不跟随 |
| `GOODBYE` | 目标刚刚消失 | 低落、目送，保留最后方向直到进入睡眠 |
| `WAKING` | 睡眠后重新检测到目标 | 眼睛逐渐睁开，跟随强度逐步恢复 |
| `IDLE` | 有人且运动较小 | 普通待机、慢眨眼、正常跟随 |
| `ACTIVE` | 速度或位置变化明显 | 睁大眼、开心表情、加强跟随 |
| `APPROACH` | Y 窗口趋势变小，目标靠近 | 眼睛变高、平嘴，保持脸型稳定 |
| `RETREAT` | Y 窗口趋势变大，目标远离 | 目送、眼睛变小，随后回到待机 |

左右跟随不是独立状态，而是连续的 `face_look` 参数。这样不会因为 LD2450 X 轴漂移而在 `LEFT` / `CENTER` / `RIGHT` 之间频繁跳变。

`APPROACH`、`RETREAT`、`WAKING` 和 `GOODBYE` 既是状态，也是事件入口。事件动画播放一小段时间后，应回到 `IDLE` 或 `ACTIVE`，不能永久锁住表情。

## 三、Model A 和 Model B 的职责

文档中原来的编号是：

- Model A：位置模型；
- Model B：状态模型。

后续实现应优先按功能称呼“位置模型”和“状态模型”，避免编号混淆。

### 位置模型

输入 LD2450 的 X/Y、趋势、方差等短窗口特征，输出：

```text
p_left
p_center
p_right
```

它只驱动：

- 脸的左右目标位置；
- 眼球方向；
- 鼻子、眼睛、嘴巴的视差偏移。

它不直接改变睡眠、活跃或惊讶状态。

### 状态模型

输入双雷达的时序特征，输出例如：

```text
p_absent
p_idle
p_active
p_approach
p_retreat
```

后续还可以扩展：

```text
p_focused
p_distracted
p_look_at_it
```

它只驱动：

- 眼睛开合；
- 瞳孔大小；
- 嘴巴形状；
- 眨眼频率；
- OLED 亮度；
- 呼吸速度；
- 一次性表情事件。

### 感知通道分工（2026-08-30 定案）

依据 LOSO 诚实评估（RF acc=0.563 / macro-F1=0.462，证据与混淆矩阵见
`training/README.md`「T1b 对齐数据集与诚实评估」）：每条动画只押在
**对该信号最可靠的检测通道**上；ML 只做混淆矩阵证明它做得到的事；
动画层必须假设误分类是常态。

| 人体活动 | 检测通道 | 驱动动画 |
|---|---|---|
| 离场 / 回来 | SR602 + 目标存在（纯规则，500ms 防抖 / 8s 进睡眠） | GOODBYE → SLEEP / WAKING |
| 静止在场（含打字） | ML STILL + ~2000ms 确认 | IDLE |
| 横移 / 大动作 | ML LATERAL **或** 规则运动积分器；方向由 slope_X 符号给出 | ACTIVE |
| 凑近 / 远离 | LD2450 Y 趋势规则（ML 仅放行） | APPROACH / RETREAT |
| 左中右位置 | X 相对校准基线 + 双阈值滞回（不进 ML） | 连续 face_look + 视差 |

连续调制通道（不占状态）：`mean_Es` 30-60s 长窗 → 眨眼 / 呼吸 / 亮度氛围
（专注 vs 发呆窗口级不可分，已降级到此慢通道）；`mean_abs_V`（8mm/s 噪声底以上）
→ 跟随增益 / 眼高。

**表情相邻原则**：互相混淆的类，动画必须相邻——现有 IDLE/ACTIVE 微差、
APPROACH 短事件、SLEEP 8s 时间常数、face_look 限速缓动均符合；
误分类在用户眼里是性格化的犹豫，不是错误。

明确不做：转头类（V1 基线证伪：召回 54% / 打字误报 28%，V2 验收门
召回 >75% 且误报 <10%，见 `training/DATA_COLLECTION_V2.md` §7）、
窗口级 FOCUSED/IDLE、Em 参与判定。
零 ML 新动画候选：「被抓到偷看」（face_look 已偏侧 + 人回中边沿触发）、
深夜困意（时钟驱动）。

## 四、融合方式

### 4.1 位置概率转换为连续方向

不使用位置模型的硬分类结果，而使用概率差：

```cpp
direction = p_right - p_left;
look_target = direction * 8.0f;
```

当模型不确定时，保持原方向，不突然跳转：

```cpp
confidence = max(p_left, max(p_center, p_right));

if (confidence < 0.55f) {
    look_target *= 0.95f;
}
```

### 4.2 状态控制跟随强度

不同状态使用不同的跟随增益：

```text
SLEEP       0.00
WAKING      0.35
IDLE        1.00
ACTIVE      1.20
APPROACH    0.60
RETREAT     0.50
GOODBYE     0.00
```

最终方向：

```cpp
final_look = position_look * look_gain;
```

含义是：睡着时不追踪，醒来时逐渐恢复，普通待机正常跟随，惊讶或告别时优先表现情绪。

### 4.3 动画层负责平滑

脸不能直接跳到模型输出的位置，当前使用中心死区、目标平滑和限速缓动：

```cpp
face_look_target += (desired_look - face_look_target) * 0.08f;
face_look += constrain((face_look_target - face_look) * 0.06f,
                       -0.55f, 0.55f);
```

左右视差是几何变化，不是简单的不同速度：

```text
整张脸：共同平移 100%
眼睛：转向时眼距最多收缩约 14px
鼻子：相对脸中心最多偏移约 7px
嘴巴：相对脸中心最多偏移约 4px
鼻子竖线固定，底部横线根据左右方向换侧
```

此外，人在中心且静止时会有约 1.5px 的低频注意力漂移；明显移动时关闭，避免变成抖动。

## 五、状态切换和防抖

## 六、当前现场调试约束

- OLED 使用 100 kHz I²C、约 80 ms 刷新一次，与采集固件节奏一致；产品版不再用 50 ms 强刷，避免 GPIO8（板载蓝灯与 OLED SDA 共用）造成偶发总线压力。
- 串口命令采用非阻塞逐字符解析，日志在发送缓冲不足时跳过，不允许串口把动画主循环卡住。
- 每 2 秒会输出一行 `DIAG`：`loopMax` 是主循环最大间隔，`drawLast/drawMax` 是 OLED 刷新耗时，`drawSlow` 是超过 120 ms 的刷新次数。用于区分 MCU 主循环停顿和 OLED/I²C 刷新变慢。

模型输出要先经过概率平滑：

```text
新状态概率 > 0.60，连续两个窗口出现
→ 才切换到新状态

当前状态概率 < 0.40
→ 才允许离开当前状态
```

这样可以避免：

```text
IDLE → ACTIVE → IDLE → ACTIVE
```

状态模型的时间窗口可以较慢，位置模型的窗口可以较快：

```text
位置模型：0.5–1 秒窗口，快速跟随
状态模型：2–5 秒窗口，稳定判断情绪
动画层：约 12.5Hz 重绘，持续缓动
```

## 六、典型场景

### 人在右侧并且正在活动

```text
位置模型：RIGHT 0.82
状态模型：ACTIVE 0.76
```

表现：睁大眼、开心表情，脸平滑转向右侧，鼻子位移最大。

### 人突然靠近

```text
位置模型：CENTER 0.60 / RIGHT 0.30
状态模型：APPROACH 0.78
```

表现：眼睛变高但宽度不变，脸仍保持经典笑脸几何，随后回到 `ACTIVE` 或 `IDLE`。

### 人离开

```text
状态模型：ABSENT 0.85
```

表现：停止跟随，脸慢慢回到中心，亮度降低，进入呼吸睡眠。

## 七、统一模型接口

未来规则系统、Random Forest、MLP 和 INT8 模型都应该转换成同一个结构：

```cpp
struct PerceptionOutput {
  float p_left;
  float p_center;
  float p_right;

  float p_absent;
  float p_idle;
  float p_active;
  float p_approach;
  float p_retreat;

  bool valid;
};
```

动画层不关心输入来自哪里。当前 v0 使用规则系统生成相同语义的结果；以后只替换感知输入层，不重写表情和状态机。

## 八、当前固件状态

当前 `happymac_v0.ino` 已经实现：

- 7 个基础状态；
- 规则版状态切换；
- 睡眠呼吸；
- 醒来、活跃、惊讶、目送表情；
- 左右连续跟随；
- 麦金塔经典笑脸骨架：固定眼睛宽度、J 形鼻子（左右朝向随位置改变），按状态在平嘴/微笑嘴之间切换；
- 鼻子方向沿用 Model A 的左右滞回，人在中心区域时保持上一次方向，避免来回跳；
- 左右正常范围约 ±24 px，极端范围软扩展到 ±30 px，眼睛可到 OLED 边缘；
- 中心约 80 mm 横向死区，位置目标平滑并限制最大移动速度，降低“到点式”跟随；
- 视差采用共同位移 + 五官相对几何变化，鼻子底部横线按左右方向切换；
- 静止时低频注意力漂移，移动时关闭；
- 独立约 180ms 短眨眼；状态主要通过眼睛高度变化表现；
- OLED 约 12.5Hz 重绘（100kHz I²C）；
- `STATE`、`RADAR`、`ANIM` 串口日志；
- `!CAL` 重新校准；
- `!STATE` 查询状态；
- `!DEBUG` 切换 OLED 调试文字标注，显示状态模型和当前位置原始值；调试版默认开启；
- 调试版 `ANIM` 状态/XY 串口日志约每 100ms 输出一次，非调试版降为每秒一次；

注意：当前 C3 板载蓝灯使用 GPIO8，而 OLED SDA 也使用 GPIO8。蓝灯看到的是
I²C 活动，不是独立的雷达/TinyML 心跳；若要独立控制蓝灯，需要重新接 OLED SDA。
- T1b `tree_d4` 状态模型的 C++ 推理；
- 2 秒雷达窗口和 9 个特征的现场计算；
- 约 2000ms 的模型状态确认（实测静坐/打字微动会在 900ms 下间歇误确认 LATERAL 造成误笑）；
- v 特征计算带 8mm/s 噪声底：拆掉微动经 `mean_abs_v` 误入 LATERAL 的路径，真实横移仍由位移特征驱动；
- ML 判 STILL 时若规则运动积分器正在报警，放行给规则路径兜底（慢速大幅横移漏检的补救）；
- 500ms 存在性防抖，避免 SR602 短暂抖动触发 `WAKING/GOODBYE` 循环；
- 运动判定改为逐帧证据积分 + 进入/退出双阈值（约 0.5s 连续证据才进入 ACTIVE，持续安静才退出），LD2450 近距静态噪声不再让 ACTIVE/IDLE 横跳；
- `APPROACH/RETREAT` 的 Y 趋势触发阈值放在静态噪声带之上（15mm/140ms），且事件后需等趋势回落到 6mm 以内才重新武装，避免趋势在阈值附近徘徊时连环触发；
- 笑容有 600ms 进入延迟（短暂误进 ACTIVE 不闪嘴）和约 1.5s 最短保持（状态边界抖动时嘴型不反复横跳）；睡眠/目送/醒来属于表情转折，不保留笑容；
- `APPROACH/RETREAT` 保留 LD2450 Y 趋势规则兜底；
- 睡前过渡链（一次性事件动画）：无人 2.5s 后 打哈欠(2s)→揉眼(1.5s, 眼睛上下蹭)→渐暗(1.2s 斜坡到近睡眠亮度)→入睡，合计约 10s（8s 阈值保留为兜底）；期间有人回来随时打断进 WAKING。事件只做帧内表情覆盖，不锁状态，`EV,` 串口日志与真机对拍。

当前还没有实现：

- 训练型 Model A 位置推理（当前为 LD2450 X 的规则试验版）；
- INT8 模型加载；
- 模型概率输出接入；
- 装入最终外壳后的阈值校准。

当前部署的试验模型文件为 `tinyml_v0_tree_d4.h`。它来自对齐后的 5 次规则
3 次自由数据，目标是验证“模型驱动动画”的最小闭环，不代表正式实验结果。

## 九、研究模式和产品模式

- 研究采集：`new_radar/new_radar.ino`
- 产品动画：`firmware/happymac_v0/happymac_v0.ino`

两个文件不要混用。研究固件输出采集阶段信息，产品固件输出 `STATE`、`RADAR` 和 `ANIM` 日志。后续正式实验应基于已经确认的外壳、雷达角度和元件位置重新采集。

## 十、当前已知限制

- `Em` 不作为主要判据；桌面距离下它不稳定。
- `APPROACH` / `RETREAT` 依赖 LD2450 Y 趋势，装入外壳后需要重新调阈值。
- LD2450 X 存在慢漂，因此位置输出必须使用相对基线、窗口趋势和概率平滑。
- 这一版只是规则版动画，不代表最终 TinyML 分类结果。
- S3 摄像头仍只作为训练期 Teacher，不放进无摄像头产品形态。

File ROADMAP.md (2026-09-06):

# HappyMac 半年开发路线（2026-09 → 2027-02，业余节奏）

> 节奏假设：每周 1-2 个晚间 + 隔周一个半天 ≈ **8-12 有效小时/周**，半年约 250-300 小时。
> 排期原则：**宁小勿大**——每周只排一个"最小可完成单元"；每月留最后一个周末做缓冲，不排任务。
> 铁律：感知参数改动必须走 `simulator → eval_replay → 上机` 三步（`simulator/` 离线闭环）；新数据进 `sessions_v2/` 并当场过质量门。

---

## 总览：三个月度主线 + 两条并行支线

```
主线（串行依赖）：外壳定稿 → V2 采集 → 重训裁决 → 部署链 → 论文
支线A（随时可做，无硬件依赖）：动画体验 / 模拟器 / 文档
支线B（跟采集顺路）：Paper 1 素材（干扰AB、距离曲线）
```

| 月份 | 主题 | 里程碑（月底验收物） |
|---|---|---|
| M1 09月 | 收尾 v0 + 硬件回归 | 板子回归 48h 内完成烧录对拍；外壳 v1 打印件在手 |
| M2 10月 | 装壳定稿 + V2 首采 | V2 第一轮数据过质量门 |
| M3 11月 | V2 采集完成 + 转头裁决 | 最终模型定稿；Paper 1 素材采齐 |
| M4 12月 | 部署链 + Paper 1 初稿 | INT8 模型上机；Paper 1 draft |
| M5 01月 | 体验打磨 + 送人版 | 送人可用版 ×1 |
| M6 02月 | Paper 2 写作 + 复盘 | Paper 1/2 投稿就绪 |

---

## M1（9月）：收尾 v0 + 硬件回归

板子不在手边的时段，把所有"不需要硬件"的事排满。

| 周 | 任务 | 产出 |
|---|---|---|
| W1 | 采集固件三处改动：2410 灵敏度 40/40（可配宏）、3 目标 CSV、FW_VERSION 入 meta | `collection_v2` 固件分支，编译通过 |
| W2 | 外壳 CAD 初稿 + 3D 打印 v1；S3 竖直朝向工装 | 打印件到手 |
| W3 | **板子回归**：烧录当前固件 → 真机对拍（`EV/STATE/ANIM` 串口日志 vs 模拟器逐行比对） | 对拍记录入库 |
| W4 | 眼神惯性：方向翻转滞回 + 二阶平滑（治"太着急"）；模拟器同步 | eval 无回退，真机观感确认 |

验收问题：真机静坐 10 分钟，误笑 0 次且表情连续？睡前链真机完整播一遍？

## M2（10月）：装壳定稿 + V2 首采

| 周 | 任务 | 产出 |
|---|---|---|
| W1-2 | 外壳迭代（v2/v3 修装配问题）；装壳前后各录一场对照（量化壳的影响，兼作 Paper 1 素材） | 装壳定稿 + 对照数据 |
| W3 | 装壳后阈值现场校准（用 eval 流程重扫 MOTION/confirm） | 校准参数入库 |
| W4 | **V2 第一轮采集**（按 `training/DATA_COLLECTION_V2.md` SOP：基线+规则+自由） | R1 数据过 9 项质量门 |

注意：外壳迭代若拖延，**用夹具临时固定几何先行采集**（规范允许，几何登记照写）——别让外壳阻塞数据线。

## M3（11月）：V2 采集完成 + 转头裁决（本项目半年内最重要的决策点）

| 周 | 任务 | 产出 |
|---|---|---|
| W1 | V2 第二轮采集（不同天、不同衣装） | R2 数据 |
| W2 | 重标定模拟器噪声模型 → `exp_head_separability.py` 转头裁决 | go/no-go 结论 |
| W3 | **go**：加 HEAD 类重训（export_tree → eval → 固件换树）；**no-go**：维持"小幅归静"，直接做 4 类重训 | 新树 + eval 报告 |
| W4 | 误笑率 <10% 验收；双雷达干扰 AB 测试（3 轮，Paper 1 素材） | 验收记录 |

裁决标准（V2 规范 §7 写死的）：HEAD 召回 >75% 且打字误报 <10%。

## M4（12月）：部署链 + Paper 1 初稿

| 周 | 任务 | 产出 |
|---|---|---|
| W1-2 | RF → MLP 蒸馏 → INT8 量化 → C3 上机（`train.py` 管线已有）；MLP vs 树的 eval 对比 | INT8 上机跑通 + 选型报告 |
| W3 | **Paper 1 初稿**：5 距离 × 4 行为曲线 + 干扰 AB + 8 月表征报告整合 | draft v0 |
| W4 | 缓冲/补漏（12 月假日系数，别排满） | — |

学术口径：Paper 1 = 物理表征（"40 元双雷达在桌面尺度的能力边界"），素材 M2/M3 已顺路采齐。

## M5（1月）：体验打磨 + 送人版

| 周 | 任务 | 产出 |
|---|---|---|
| W1 | 作息钟 + 深夜参数调制（"困但撑着陪你"） | 昼夜行为差异可演示 |
| W2 | **惊醒假装没睡**（深夜 SLEEP + Y 趋势触发，事件系统插槽已留） | 招牌动画落地 |
| W3 | 发呆涣散态；电源优化实测（雷达占空比策略，803040 续航目标翻倍） | 送人版定稿 |
| W4 | 新模型装壳校准第二轮；送人版 ×1 组装 | 可送出 |

## M6（2月）：Paper 2 写作 + 半年复盘

| 周 | 任务 | 产出 |
|---|---|---|
| W1-2 | **Paper 2 初稿**：跨模态蒸馏管线 + V2 数据 + 消融（X/Es/Y 通道、协议vs自然、误笑率作为产品指标的故事） | draft v0 |
| W3 | 全量回归 + 模拟器最终校准；仪器模式整理（导师 demo 用） | 冻结版 |
| W4 | 半年复盘：投稿目标选定（期刊/workshop）；下一半年方向 = Paper 3（动画层用户研究） | 复盘文档 |

---

## 依赖图与关键路径

```
外壳定稿 ──→ V2 采集(R1+R2) ──→ 重训裁决 ──→ 部署链 ──→ Paper 2
   │              │
   │              └──(顺路)──→ Paper 1 素材 ──→ Paper 1 初稿（M4）
   └─(可被夹具绕过，不阻塞数据线)

动画/电源支线（M1/M5）与主线并行，不抢资源。
```

**关键路径上的唯一硬前置是外壳**——所以 M1 就开工 CAD，M2 留了"夹具绕过"的逃生门。

## 风险与预案

| 风险 | 预案 |
|---|---|
| 外壳迭代拖过长 | 夹具临时固定先行采集（几何登记照写），外壳与数据解耦 |
| 转头仍不可分 | 按既定决策搁置产品化，主线不受影响（V2 数据照样服务 4 类重训） |
| MLP 不如决策树 | 树留作产品模型，MLP 结果进论文——两条腿都不浪费 |
| 假日/学业挤占 | 每月 W4 缓冲 + 月度里程碑只设 1 个硬验收物；砍顺序：Paper 1 < 电源 < 动画 < 数据 < 部署 |
| 板子长期不回 | M1 的 W1-W2 任务与模拟器工作可支撑约一个月；对拍推迟到 M2 |
| 调敏后误报上升 | `eval_replay --sweep` 重扫参数（规范已写） |

## 本周就能做的三件事（不等板子）

1. 采集固件三处改动（`collection_v2` 分支）
2. 外壳 CAD 初稿（量一下 803040 + 双雷达 + OLED 的堆叠高度）
3. 眼神惯性参数（模拟器先行）

---

*依赖既有资产：`simulator/` 离线闭环、`training/DATA_COLLECTION_V2.md` 采集规范、事件系统插槽、`train.py` 蒸馏管线、8 月表征报告 docx。本路线由 2026-08-30/09-06 的工作推导。*

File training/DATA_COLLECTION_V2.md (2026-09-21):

# 数据采集规范 V2 —— 装壳后的正式采集（下半场）

> 适用时机：**产品装配（外壳/安装位）确定之后**。
> 雷达安装几何一变，V1 数据（`sessions/` 里 2026-08 的 8 个训练会话）即不可再用作主训练集——这是 README「TinyML 管线限制」里写明的既有结论。
> 本文档是采集的**唯一执行规范**：开工前通读一遍，现场照 SOP 走，结束后照质量门验收。

---

## 0. 为什么是 V2（背景与目标）

V1 数据体检（2026-08-30）发现的问题，本轮必须修复，否则重训没有意义：

| # | V1 问题 | 体检证据 | V2 对策 |
|---|---|---|---|
| 1 | 规则场次视频全部倒装（5/5） | 抽帧目检，人脸 180° 倒置 | 工装固定朝向 + 开录首帧人工确认（§3.4） |
| 2 | Es 会话间漂移（中位 37~61），而 Es 是头号特征（重要性 0.346） | 各会话 summary 对比 | 几何登记 + 静置规范 + 每场空桌面基线（§2、§4） |
| 3 | 自由数据 LATERAL 样本稀缺（154~547 帧，少 3~10 倍） | aligned 标签分布 | 新增 `big_sway` 动作块 + 自由会话保底要求（§3.2） |
| 4 | em 全场报废（>0 帧仅 0.9~4.5%），2410 被阈值 80 调聋 | em 统计 | 采集固件灵敏度调到 40/40，质量门验证（§1、§5） |
| 5 | 只记录第一个雷达目标，头部分辨目标被丢弃 | parse2450 逻辑 | 记录全部 3 目标（§1.2） |

V2 要回答的问题（按优先级）：
1. 装壳几何下，现有 5 类（ABSENT/STILL/LATERAL/APPROACH/RETREAT）模型要重训——提供主训练集；
2. **转头可分性**：调敏后的 em + 3 目标数据，能否把 head_only 从 typing/still 里分出来（`exp_head_separability.py` 验收，见 §7）；
3. 距离因素显式化：近场（0.5m）/远场（1.5m）分开采样，给阈值调参提供依据。

---

## 1. 采集前固件与工具准备（前置条件，缺一不开工）

### 1.1 采集固件（new_radar.ino 或新开 collection_v2 分支）改动
- [x] LD2410C gate 0-3 灵敏度阈值 **80/80 → 40/40**（V1 值也保留为编译期宏，方便对照实验）
- [x] `parse2450` 输出**全部 3 个目标**：CSV 列扩展为
      `t_global,x,y,v,x2,y2,v2,x3,y3,v3,em,es,action`（无第二/三目标时填 0）
- [x] 固件版本号 `FW_VERSION` 宏，串口启动时打印，写入 meta
- [x] 增加 `!START,<c3_ms>` 正式录制起点标记
- [ ] S3 竖直朝向固定（加装定位件），`/status` 返回 orientation 字段

### 1.2 上位机（collect.py）
- [x] 支持新的 3 目标 CSV 列（`training/v2_io.py`，V1/V2 自动识别）
- [x] 采集行保留 C3 `c3_ms` 与主机 `host_ts`
- [x] 每场自动写 `_meta.json`：固件版本、同步标记、质量摘要
- [x] `collect_session.py --v2` 输出到独立 `sessions_v2/`，不覆盖 V1
- [x] `align_v2_sessions.py` 用同一主机时间轴直接对齐视频和雷达
- [x] 结束时自动跑质量门快检（§5），终端直接显示 PASS/FAIL

V2 采集命令：

```bash
python training/collect_session.py --v2 \
  --port /dev/cu.usbmodem2101 \
  --orientation upright \
  --geometry 'height_mm=?,pitch_deg=?,azimuth_deg=?'
```

采集完成后先对齐并检查：

```bash
python training/align_v2_sessions.py --session YYYYMMDD_HHMMSS
```

注意：V2 固件必须和 `--v2` 主机采集器一起使用；不要用旧的 V1 解析脚本直接接收三目标 CSV。

### 1.3 版本冻结纪律
- 采集轮次期间**禁止**改任何固件参数/灵敏度/安装几何；确需改动 → 当前会话作废、meta 记录变更、重新开始本轮
- 模拟器噪声模型（`happymac_sim.html` FW 区）在本轮第一场数据验收后重新标定一次

---

## 2. 环境与工装规范

### 2.1 雷达静置（2026-08-09 实验规范，继续执行）
上电后**静置 ≥2 分钟**再开始记录，期间天线对空桌面/空墙自运行。冷启动异常跳动只记入 meta 备注，不进入训练数据。

### 2.2 供电
C3 独立 USB 口或独立电源，**不与 S3 共用同一 USB 总线**（V1 教训：共用时 Yσ 从 29mm 劣化到 290mm）。S3 走 WiFi AP 模式。

### 2.3 几何与环境登记（写入 meta.json，缺项不得开工）
- 雷达安装高度（mm）、俯仰角、朝向方位、距桌面边缘距离
- 装壳状态：裸板 / 装壳（壳材质）
- 房间、桌面材质、1m 内主要反射物
- 拍照 2 张：雷达安装特写 + 全局摆位

### 2.4 视频朝向确认
开录后第 1 帧，人工确认人脸**正立**（V1 倒装教训）。不确认不继续。

---

## 3. 会话内容计划

每轮 = **1 空桌基线 + 1 规则会话 + 1 自由会话**。正式采集 ≥2 轮（不同天各一轮）。

### 3.1 空桌基线（新增，V1 没有）
无人在场录 60s。用途：ABSENT 类的真值基线 + 当场噪声底标定。

### 3.2 规则会话（约 6 分钟，HUD 引导，沿用倒计时模板）

| 动作块 | 时长 | 说明 |
|---|---|---|
| still_30s | 30s | 静坐基线 |
| natural_typing | 45s | **加长**（V1 是 27s；STILL 边界的重灾区，多给数据） |
| slow_sweep | 20s | 缓慢左右躯干移动 |
| quick_points | 20s | 快速指点 |
| ellipse | 20s | 画椭圆 |
| fwd_back | 20s | 前倾后靠 |
| head_only | 30s | **加长**：转头看雷达方向 ×6 次 + 左右看 ×6 次（转头研究主数据） |
| **turn_toward**（新增） | 20s | 随机间隔突然转头看雷达，带轻微身体前倾（模拟"被它抓住注意"） |
| **big_sway**（新增） | 20s | 大幅左右重心移动 ±50cm（补 LATERAL 坑） |
| **still_near / still_far**（新增） | 15s+15s | 0.5m 与 1.5m 各静坐一段（距离显式采样） |
| natural_reach | 20s | 伸手取物 |
| stand_sit | 20s | 起身坐下 |

### 3.3 自由会话（5 分钟 × 每轮 1 场）
正常用电脑即可（被动采集），但**保底要求**：
- 至少一段明显左右移动（≥30cm）≥20s——保 LATERAL
- 至少一次起身离开画面 ≥10s 再回来——保 ABSENT/GOODBYE 语义
- 至少一次从远处走近再坐回——保 APPROACH
- 深夜时段若条件允许加采 1 场（作息调制的验证数据）

### 3.4 轮次与总量
- ≥2 轮、跨 ≥2 天；每轮产出 ≈1 规则 + 1 自由 + 1 基线
- 窗口产出估算（2s 窗 / 0.5s 步）：规则每场 ≈260 窗、自由每场 ≈590 窗、2 轮合计 ≈2700 窗（V1 为 1185 规则窗 + 自由窗）
- 验收目标：**每个训练类 ≥600 窗**（V1 的 LATERAL 远低于此）

---

## 4. 现场执行 SOP（每场照做）

1. 上电，静置 ≥2 分钟（手机倒计时），期间确认视频朝向（§2.4）
2. 录 60s 空桌基线（无人在 3m 内）
3. 人员入位，串口发 `!CAL` 校准中心
4. 开始规则会话（HUD 引导）或自由会话（按 §3.3 保底清单执行）
5. 全程禁止：插拔 USB、改波特率、开启动画固件、挪动雷达
6. 结束后**当场**跑质量门快检，FAIL 项当场重采（人还在、姿势还热）

---

## 5. 质量门（每场验收标准，全部 PASS 才算数）

| 检查项 | 阈值 | 来源 |
|---|---|---|
| 帧率 | ≥14Hz（实测应 ≈16.2） | V1 基线 |
| 空窗 | >1s 的间隙 = 0 | V1 达标项，保持 |
| em 活性 | em>0 帧占比 ≥10% | 验证调敏生效；不达标先查灵敏度 |
| 3 目标列 | 第二/三目标列在多人/转头段非全零 | 验证新 parse |
| 静坐噪声 | still 段 \|x\| σ ≤150mm | V1 实测区间 |
| 对齐有效 | 规则 ≥80%，自由 radar_valid ≥95% | V1 水平 |
| 视频朝向 | 正装、人脸完整、HUD 可读 | 倒装教训 |
| 标签下限 | LATERAL ≥600 帧/轮；HEAD/TURN 相关块完整执行 | 补坑目标 |
| 基线 | 空桌 60s 存在且 es 接近 0 | 新增项 |

FAIL 处理：当场重采一次；仍 FAIL → 记录原因、跳过该项继续（数据留档不进训练集），当天结束后统一排查。

---

## 6. 数据管理与命名

- 新数据一律放 **`sessions_v2/`**；V1 的 `sessions/` 冻结只读
- 命名沿用 `session_YYYYMMDD_HHMMSS.csv`，附属文件同 V1 约定（_aligned / _vidts / _meta）
- `_meta.json` 新增字段：`fw_version`、`sensitivity`、`orientation`、`geometry{height,pitch,azimuth,edge_dist}`、`shell`、`noise_baseline{es_med,x_std_still}`
- 大文件（mp4/csv）不入 git（沿用现有 .gitignore），**summary/meta 必须入库**
- 每轮收工：跑 `align_all_sessions.py` 生成 aligned → 跑体检脚本复核 → 提交 summary

---

## 7. 采集后验收 → 重训决策链

```
质量门全 PASS
  ↓
① 用 V2 数据重标定模拟器噪声模型（happymac_sim.html FW 区）
  ↓
② python3 exp_head_separability.py   ← 转头可分性验收
     HEAD 召回 >75% 且 TYPING→HEAD 误报 <10%
     ├── 达标 → 新增 HEAD 类，走完整重训（export_tree.py 出 C+JS）
     └── 不达标 → 转头产品化搁置，维持"小幅动作归 STILL"（2026-08-30 决策）
  ↓
③ eval_replay.js 用新树全量回归
     静坐误笑率目标 <10%（当前 V1 树为 16.6%）
  ↓
④ 重训通过 → 固件换树、模拟器同步、烧录、真机对拍
```

---

## 8. 已知风险与预案

- **调敏副作用**：2410 灵敏度 40 可能推高运动误报 → 重采后用 `eval_replay.js --sweep` 重扫 MOTION/confirm 参数
- **壳体散射未知**：预算允许时加采一场"裸板 vs 装壳"同协议对照，量化壳的影响（也可作为论文素材）
- **转头还是不可分**：按 2026-08-30 决策，产品上搁置转头反应，不硬凑
- **双雷达互扰**：硬件固有（AO3401 电源门控仍未实施），本规范通过"es 基线登记 + 每场静置"控制其可变性，不试图消除

---

## 9. V1 → V2 追踪表（本规范的出处）

| V1 审计结论 | 本规范落点 |
|---|---|
| 视频倒装 5/5 | §2.4 朝向确认、§2.3 工装登记 |
| Es 漂移 | §2.1 静置、§2.3 几何登记、§3.1 基线 |
| LATERAL 稀缺 | §3.2 big_sway、§3.3 保底要求、§5 标签下限 |
| em 报废 | §1.1 调敏、§5 em 活性门 |
| 单目标丢弃 | §1.2 三目标 CSV、§5 3 目标门 |
| 无 ABSENT 基线 | §3.1 空桌基线 |
| USB 共口噪声 | §2.2 供电分离 |

*本规范由 2026-08-30 的 V1 数据体检（8 会话只读评估）直接推导；执行中如需修改规范，先改本文档再动现场。*

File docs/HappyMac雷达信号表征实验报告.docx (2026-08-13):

低成本 24GHz 双雷达
桌面尺度人体感知能力表征

HappyMac 项目 · 信号表征实验报告

2026-08-13
数据采集与分析：三次独立 Session
硬件：ESP32-C3 + HLK-LD2450 + HLK-LD2410C + ESP32-S3-EYE

摘　　要

本研究对两个低成本 24GHz 毫米波雷达（HLK-LD2450 双通道定位雷达、HLK-LD2410C 存在检测雷达）在桌面尺度（0.6-1.2 m）下感知坐姿人体的能力边界进行了系统性表征。三次独立实验 Session（每次约 4 分钟、9 个行为阶段）配合摄像头视觉基准（MediaPipe 人脸关键点、MiDaS 单目深度）交叉验证了雷达各信号通道的有效性。主要发现：（1）LD2450 的 X 通道携带真实横向位置信息（与视觉基准相关 r≈+0.18，三次可重复），但被静止漂移（σ=128 mm/30s）淹没，仅时间趋势可用；（2）LD2450 的 Y 通道在阶段统计上符合物理预期，但与单目深度的线性关系未获稳定复现；（3）LD2410C 的静止能量数值（Es）随身体姿态呈约 2 倍动态范围变化，是有效的姿态弱特征；其移动能量通道（Em）在桌面尺度基本失效（触发率 2-6%）；头部朝向感知被实验证伪。结论指向一条明确的 TinyML 路线：以 X 趋势、Y 距离、Es 数值、速度四类信号的时间窗统计特征训练轻量分类器，并以此为基础开展跨模态蒸馏研究。

目　　录

# 1 引言

## 1.1 项目背景

HappyMac 是一款吸附于书桌背景板的像素交互小宠物，目标是以「无摄像头、无麦克风」的方式感知用户存在与状态。感知链路依赖三级传感器：SR602 红外（唤醒哨兵）、LD2410C（微动/存在检测）、LD2450（位置追踪）。该方案的核心假设是：两个总价不足 50 元的 24GHz 雷达在近距离桌面场景中能够提供足够的行为分类信号。

## 1.2 研究问题

（1）LD2450 的 X/Y 坐标是否真实反映人体位置？（2）LD2410C 的能量通道携带什么信息？（3）哪些信号可用于后续 TinyML 行为分类？

# 2 实验方法

## 2.1 实验协议

每 Session 含 9 个有效行为阶段（自由活动阶段因被试未能及时终止而截断，全部排除）：

表 1 行为阶段协议

阶段 | 时长 | 行为说明
still_30s | 30 s | 静止坐姿
slow_sweep | 20 s | 缓慢连续左右摆动（每侧约 5 s）
quick_points | 20 s | 快速定点移动：左—停—右—停—中
ellipse | 20 s | 上半身椭圆运动（顺/逆时针）
fwd_back | 20 s | 前倾—回正—后靠
head_only | 20 s | 身体静止，仅头部转动
natural_typing | 45 s | 自然打字/浏览
natural_reach | 20 s | 伸手取物（手机/水杯）
stand_sit | 20 s | 站起—坐下交替

## 2.2 关键实验控制

- 雷达预热：每次 Session 前雷达静置 ≥3 分钟，排除冷启动漂移期（该现象已在前序实验中识别并固定为实验规范）。
- 时间戳对齐：雷达串口数据与摄像头 MJPEG 流均以采集计算机墙钟（time.time()）打戳，配对窗口 150 ms；延迟扫描确认无残留系统偏移（0 ms 时相关性最优）。
- 重复性：完整协议独立重复 3 次（Session 160414 / 165801 / 170609）。
- 安装方式：LD2450 天线阵列水平、PCB 竖直，正对受试者，距离约 0.7 m。

## 2.3 视觉基准

横向位置基准：MediaPipe Face Landmarker（468 关键点）脸部中心横向归一化坐标 head_x。
距离基准：MiDaS_small 单目深度估计（intel-isl/MiDaS），取脸部中心 11×11 邻域中位数。注意 MiDaS 输出「越近值越大」而雷达 Y「越近值越小」，两者预期负相关。

# 3 结果

## 3.1 LD2450 X 通道：横向位置追踪（弱但可重复）

表 2 视觉基准 head_x 与雷达 X 的 Pearson 相关（三次 Session）

Session | r(X) | 对齐样本对数
160414 | +0.207 | 2164
165801 | +0.166 | 2052
170609 | +0.181 | 2015
均值 | +0.185 | —

三次实验符号一致为正，雷达 X 确携带横向位置信息，但相关强度弱——绝对定位不可靠。

表 3 分阶段 X 相关性（Session 160414）

行为阶段 | r(X) | 解读
slow_sweep | +0.447 | 慢速横向移动时追踪最强
head_only | +0.228 | 转头产生 X 响应
stand_sit | +0.229 | 站起/坐下伴随 X 变化
still_30s | −0.218 | 静止期 X 漂移与头部位置反相关

信号主要集中在预期阶段；静止期反相关表明漂移不跟随头部位置——漂移是 X 通道不可靠的根源。

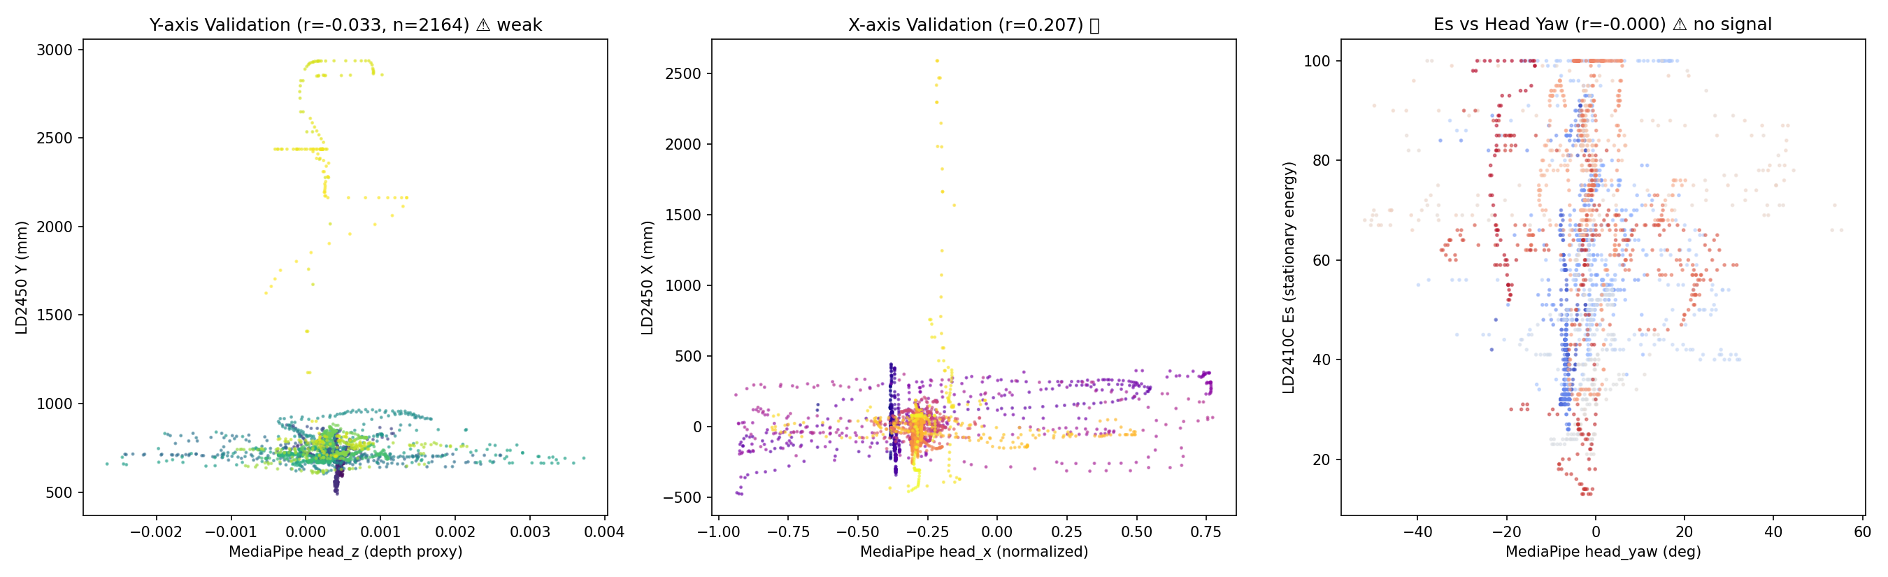
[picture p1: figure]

图 1 视觉-雷达联合验证散点（Session 160414）：X 验证 / Y 验证 / Es 朝向验证

## 3.2 LD2450 Y 通道：距离测量

表 4 MiDaS 深度与雷达 Y 的相关（预期负相关）

行为阶段 | S1 | S2 | S3
fwd_back | −0.534 | +0.015 | −0.208
natural_typing | −0.533 | +0.138 | −0.066
slow_sweep | −0.349 | −0.107 | −0.126
ellipse | +0.374 | +0.472 | +0.324
still_30s | −0.184 | −0.257 | +0.179

Session 1 的前后移动阶段呈现强负相关（r=−0.53），符合物理预期，但 Session 2/3 未复现。可能原因：单目相对深度在近距场景的尺度不稳定；雷达 Y 测「最近强反射体」而 MiDaS 测「人脸区域深度」，两者物理量不完全同构。Y 通道在阶段统计层面（表 5，Y σ：stand_sit 438 mm vs head_only 51 mm）仍符合物理预期的响应模式。

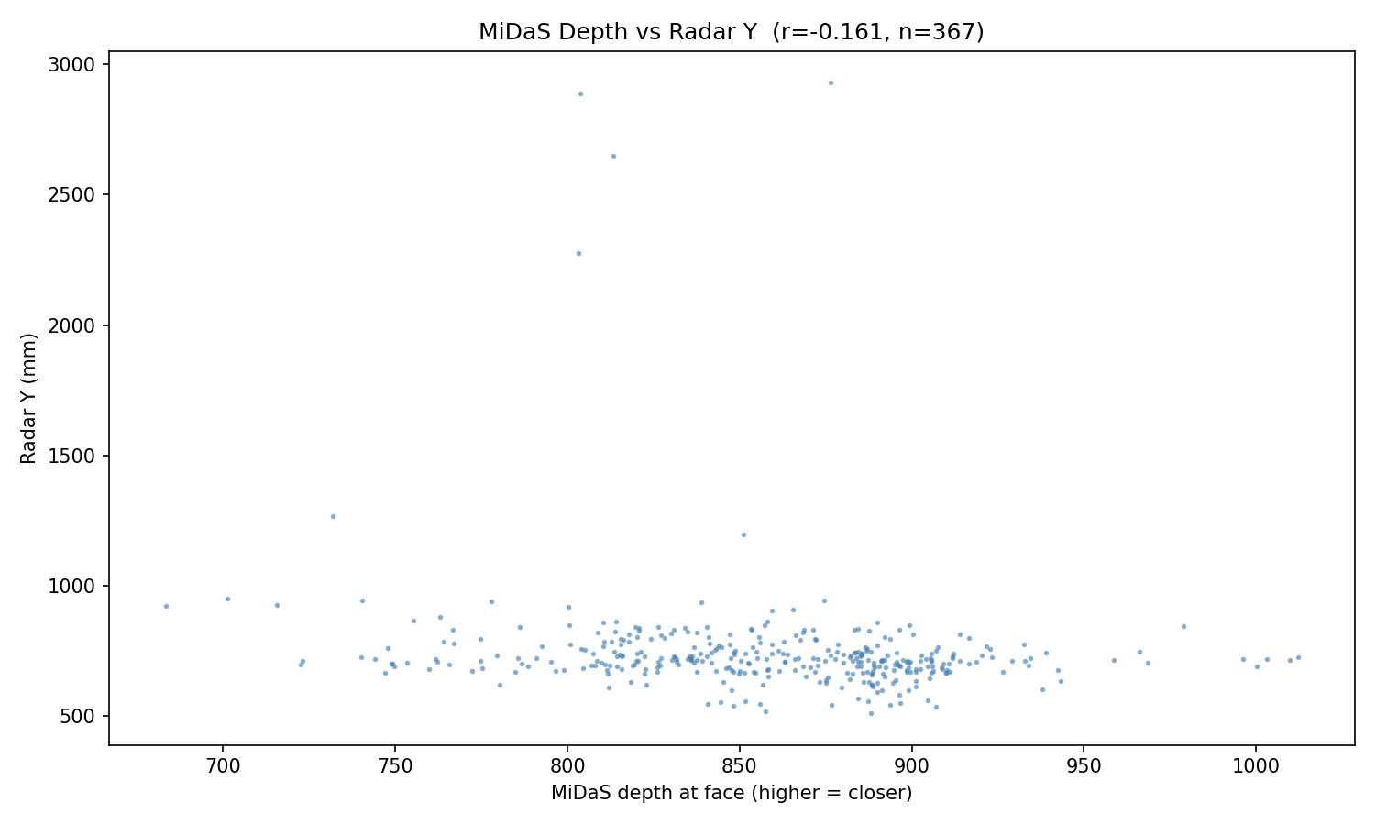
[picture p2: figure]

图 2 MiDaS 脸部深度与雷达 Y 散点（Session 160414）

## 3.3 阶段统计：三次平均

表 5 各行为阶段雷达统计（三次 Session 平均）

行为阶段 | X 均值(mm) | X σ(mm) | Y 均值(mm) | Y σ(mm) | Em% | Es%
still_30s | +9 | 128 | 644 | 65 | 1 | 100
slow_sweep | +70 | 218 | 709 | 67 | 3 | 100
quick_points | +71 | 212 | 750 | 76 | 4 | 100
ellipse | +77 | 158 | 710 | 81 | 3 | 100
fwd_back | +52 | 86 | 730 | 98 | 6 | 100
head_only | −2 | 79 | 742 | 51 | 6 | 100
natural_typing | −22 | 84 | 722 | 62 | 2 | 100
natural_reach | +9 | 100 | 724 | 58 | 5 | 100
stand_sit | +131 | 482 | 1063 | 438 | 5 | 100

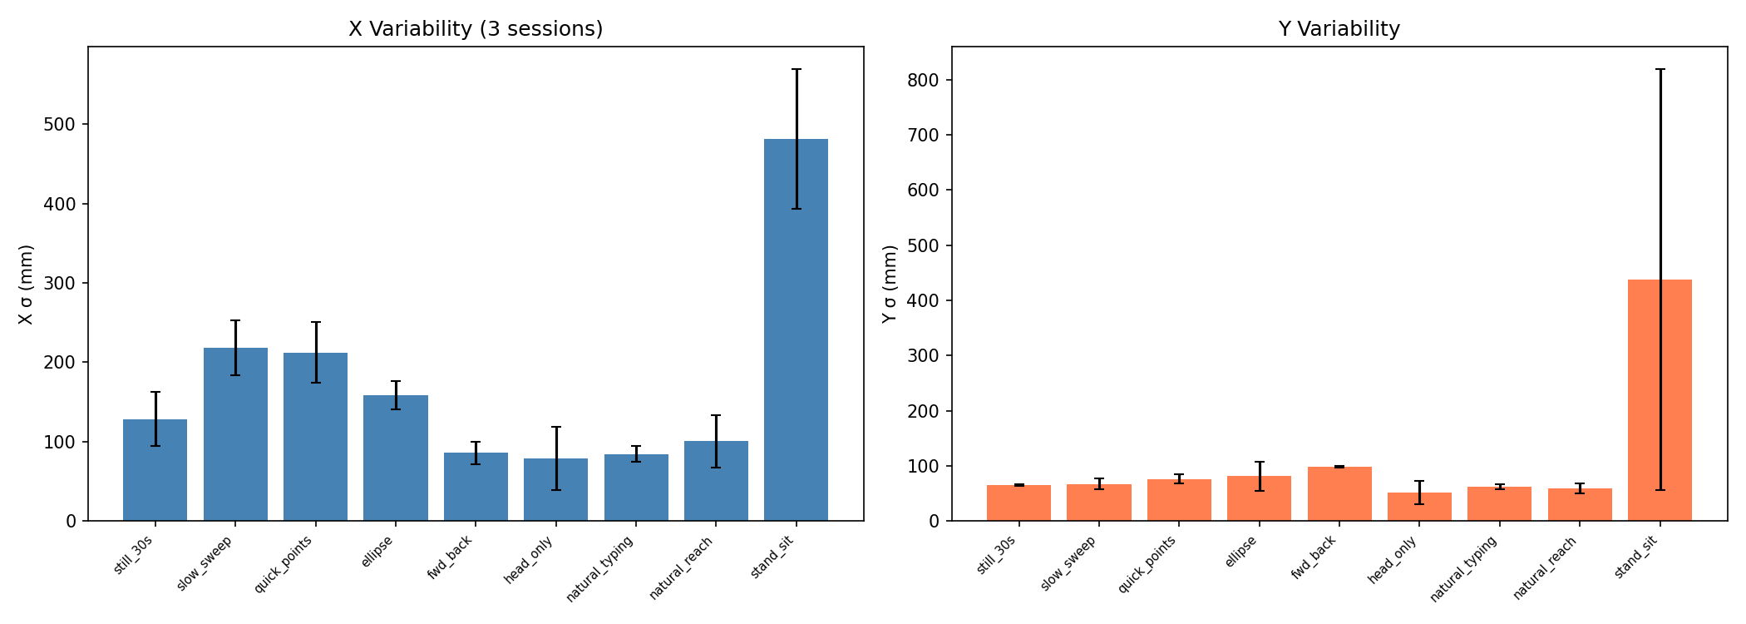
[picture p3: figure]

图 3 X/Y 变异性跨阶段对比（三次 Session 平均，含标准差误差棒）

关键观察：持续运动（慢扫 σ=218 mm、快速定点 σ=212 mm）的 X 变异性约为静止漂移基线（128 mm）的 1.7 倍，运动信号在统计上可区分于漂移；但静止漂移本身构成约 13 cm 的「噪声地板」，任何依赖 X 绝对值的单帧分类均不可行，只有时间窗内的趋势模式（斜率、方差）才携带可用信息。

## 3.4 LD2410C：Es 数值是姿态特征，Em 失效，朝向感知不存在

表 6 LD2410C 静止能量 Es 数值按行为排序（三次平均）

行为阶段 | Es 均值 (0-100)
natural_typing | 72.8
head_only | 69.8
still_30s | 63.9
slow_sweep | 61.6
natural_reach | 60.7
quick_points | 59.1
ellipse | 55.7
fwd_back | 44.2
stand_sit | 39.4

Es 数值呈现近 2 倍动态范围（39-73）：上身稳定的行为（打字、只转头）Es 最高，身体形态剧变的站起/坐下 Es 最低。Es 数值是有效的身体姿态弱特征。

Em（移动能量）在桌面尺度基本失效：三次平均触发率仅 2-6%（前倾后靠也只有 6%）。原因：LD2410C 出厂参数面向房间尺度（3-5 m）设计，0.6-1 m 近距离人体「太大、太近」，移动检测门控难以区分。

表 7 Es 与头部朝向（MediaPipe head_yaw）相关（三次 Session）

Session | r(Es, head_yaw)
160414 | −0.000
165801 | +0.004
170609 | −0.116

三次相关系数 |r|<0.12：LD2410C 在桌面场景无法感知头部朝向。「通过 Es 判断用户是否看向设备」的设计假设被实验证伪。

# 4 讨论

## 4.1 对 TinyML 管线的影响

（1）可用特征收窄：X 趋势（slope）、Y 距离、Es 数值、速度（V）四类信号有效；X 绝对值、Em、Es 朝向无效。（2）模型必须学会「何时信任 X」：静止期漂移与运动期信号在单帧上不可分，但时间序列模式（持续同向 vs 随机游走）可被滑动窗口统计特征捕获。（3）Es 数值升格：从「存在检测器」升格为「姿态弱特征」，应纳入特征集并做消融实验验证贡献。

## 4.2 与文献的一致性

LD2450 静止目标检测不可靠、多径鬼影现象与 ESPHome/Home Assistant 社区大量报告一致。本文贡献在于首次给出该雷达桌面场景的定量表征：X 静止漂移 128 mm/30s、运动/静止比 1.7x、Es 姿态动态范围约 2 倍、Em 触发率 <6%。这些数字此前未见公开数据。

# 5 局限

（1）n=1 被试，仅单一体型与坐姿；（2）MiDaS 单目深度为相对尺度，无法提供绝对距离验证；（3）三次 Session 时间跨度约 1 小时，未覆盖跨日/跨光照条件；（4）双雷达同频干扰未做 AB 对照（本实验两雷达同时开启）；（5）摄像头帧差/关键点基准存在自身误差（MediaPipe 检测率 86-91%）。

# 6 结论

（1）LD2450 X 轴：横向追踪信号真实存在（r≈+0.18，三次可重复），但被静止漂移淹没，仅趋势可用；（2）LD2450 Y 轴：阶段统计符合物理预期，与视觉深度基准的线性关系未获稳定复现，需双目/ToF 基准确认；（3）LD2410C：Es 数值是有效姿态特征，Em 桌面无效，头部朝向感知被证伪；（4）TinyML 路线成立：以 X 趋势 + Y + Es 数值 + V 为特征集，滑动窗口统计特征 + 轻量分类器；下一步先以随机森林（RF）验证特征可分性，再蒸馏至 MLP 部署 ESP32-C3。

# 7 后续工作

## 7.1 短期（TinyML 验证）

- RF 特征可分性验证：用本次三 Session 数据提取滑动窗口特征，以随机森林评估 4-5 类行为（离场/静止/左右移动/前后移动/站起坐下）的分类准确率，作为 TinyML 的可行性闸门。
- 特征消融：分别移除 X 趋势、Es 数值、速度，量化各通道边际贡献。
- 阈值规则 baseline：实现手写规则分类器，与 ML 方案定量对比。

## 7.2 中期（跨模态蒸馏）

- 摄像头-雷达硬件同步：以 GPIO 线连接 C3 与 S3，实现微秒级时间戳同步，重新验证 Y 通道与视觉深度的线性关系。
- 视觉 Teacher 训练：以 MediaPipe 关键点训练「桌面注意力状态」分类器（天花板实验），确定 Student 的理论精度上限。
- TinyML 部署：训练 2 层 MLP（<2 KB 参数），INT8 量化后部署 ESP32-C3，实测推理延迟与量化损失。

## 7.3 长期（学术方向）

- Paper 1（信号表征）：本文数据扩充后投稿传感系统会议——首个低成本 24GHz 雷达桌面场景定量表征。
- Paper 2（跨模态蒸馏）：视觉 Teacher → 雷达 Student 的蒸馏管线，核心卖点为「信息损失分解：模态 gap vs 量化损失」。
- Paper 3（交互设计）：不完美感知的交互设计框架（Attention-Oriented Sensing），以 HappyMac 概率表情状态机为案例。
- 硬件改进：VL53L1X ToF 三角定位补充 X 精度；双雷达分时复用（MOSFET 门控）量化同频干扰。

# 附录

# 附录 A 每 Session 每阶段完整统计

表 A.1 Session 20260813_160414 逐阶段统计

行为阶段 | 帧数 | X均值(mm) | Xσ(mm) | Y均值(mm) | Yσ(mm) | Em% | Es%
静止 | 539 | -6 | 176 | 635 | 63 | 0% | 100%
慢速左右摆 | 408 | +22 | 220 | 694 | 78 | 3% | 100%
快速定点 | 408 | +69 | 263 | 773 | 87 | 3% | 100%
椭圆运动 | 408 | +62 | 171 | 715 | 55 | 3% | 100%
前倾后靠 | 408 | +20 | 89 | 776 | 99 | 4% | 100%
只转头 | 408 | +7 | 60 | 742 | 74 | 4% | 100%
自然打字 | 814 | -27 | 77 | 742 | 55 | 2% | 100%
伸手取物 | 408 | -6 | 72 | 737 | 51 | 2% | 100%
站起坐下 | 408 | +166 | 567 | 1531 | 976 | 10% | 100%

表 A.2 Session 20260813_165801 逐阶段统计

行为阶段 | 帧数 | X均值(mm) | Xσ(mm) | Y均值(mm) | Yσ(mm) | Em% | Es%
静止 | 539 | +1 | 110 | 628 | 65 | 0% | 100%
慢速左右摆 | 408 | +99 | 259 | 733 | 69 | 1% | 100%
快速定点 | 408 | +12 | 204 | 764 | 66 | 1% | 100%
椭圆运动 | 408 | +78 | 171 | 700 | 117 | 2% | 100%
前倾后靠 | 408 | +68 | 101 | 717 | 100 | 7% | 100%
只转头 | 408 | +10 | 42 | 742 | 24 | 4% | 100%
自然打字 | 813 | +2 | 98 | 712 | 66 | 1% | 100%
伸手取物 | 409 | +39 | 82 | 738 | 53 | 6% | 100%
站起坐下 | 408 | +197 | 361 | 823 | 137 | 2% | 100%

表 A.3 Session 20260813_170609 逐阶段统计

行为阶段 | 帧数 | X均值(mm) | Xσ(mm) | Y均值(mm) | Yσ(mm) | Em% | Es%
静止 | 540 | +32 | 99 | 669 | 67 | 2% | 100%
慢速左右摆 | 408 | +88 | 175 | 700 | 55 | 5% | 100%
快速定点 | 408 | +131 | 170 | 715 | 76 | 7% | 100%
椭圆运动 | 408 | +89 | 133 | 715 | 71 | 4% | 100%
前倾后靠 | 407 | +68 | 67 | 696 | 95 | 7% | 100%
只转头 | 409 | -25 | 135 | 740 | 56 | 9% | 100%
自然打字 | 813 | -40 | 79 | 712 | 65 | 2% | 100%
伸手取物 | 407 | -8 | 147 | 696 | 71 | 6% | 100%
站起坐下 | 408 | +31 | 518 | 835 | 200 | 2% | 100%

# 附录 B 分阶段视觉相关性（Session 160414）

表 B.1 MediaPipe 基准分阶段相关（X=横向位置，Y=深度 proxy z）

行为阶段 | X r | Y r
ellipse | +0.150 | +0.273
fwd_back | −0.124 | −0.361
head_only | +0.228 | −0.061
natural_reach | +0.006 | −0.098
natural_typing | −0.163 | +0.116
quick_points | +0.098 | −0.463
slow_sweep | +0.447 | +0.110
stand_sit | +0.229 | +0.356
still_30s | −0.218 | +0.055

# 附录 C MiDaS 深度验证完整结果

表 C.1 MiDaS 脸部深度与雷达 Y 相关（预期负相关）

行为阶段 | S1 (160414) | S2 (165801) | S3 (170609)
ellipse | +0.374 | +0.472 | +0.324
fwd_back | −0.534 | +0.015 | −0.208
head_only | −0.266 | −0.025 | −0.284
natural_reach | +0.159 | −0.074 | −0.151
natural_typing | −0.533 | +0.138 | −0.066
quick_points | +0.150 | −0.249 | −0.222
slow_sweep | −0.349 | −0.107 | −0.126
stand_sit | −0.093 | −0.110 | +0.265
still_30s | −0.184 | −0.257 | +0.179
全部合并 | −0.161 | +0.154 | −0.028

# 附录 D 实验硬件与软件环境

表 D.1 实验环境

组件 | 规格
主控 | ESP32-C3 SuperMini（RISC-V 160MHz，400KB SRAM）
位置雷达 | HLK-LD2450，1T2R FMCW，24GHz，天线基线 ~6.25mm，输出 10Hz
存在雷达 | HLK-LD2410C，24GHz FMCW，9 距离门，0.75m/门
摄像头 | ESP32-S3-EYE（AP 模式 MJPEG 推流，10fps 640×480）
视觉基准 1 | MediaPipe Face Landmarker（468 关键点，86-91% 检测率）
视觉基准 2 | MiDaS_small 单目深度（intel-isl/MiDaS，PyTorch 1.x，CPU 推理）
时间戳 | 采集计算机墙钟 time.time()，配对窗口 150ms，无残留延迟

# 附录 E 数据分析管线说明

1. collect_session.py：SYNC 握手 + 3 分钟雷达预热 + 逐帧墙钟打戳（雷达 CSV + 视频帧时间戳 vidts.csv 独立保存）。
2. analyze_session.py：雷达侧 6 图（时间序列/分布/静止对比/漂移/能量散点/科研面板）。
3. analyze_vision.py：MediaPipe 逐帧推理 → 与雷达按墙钟最近邻配对 → 三张验证散点。
4. analyze_depth.py：MiDaS 每 0.5s 采样 → 脸部 11×11 邻域中位数 → 与雷达 Y 配对。
5. analyze_all.py：多 Session 白名单汇总，输出正文均值±标准差与附录逐轮数据。

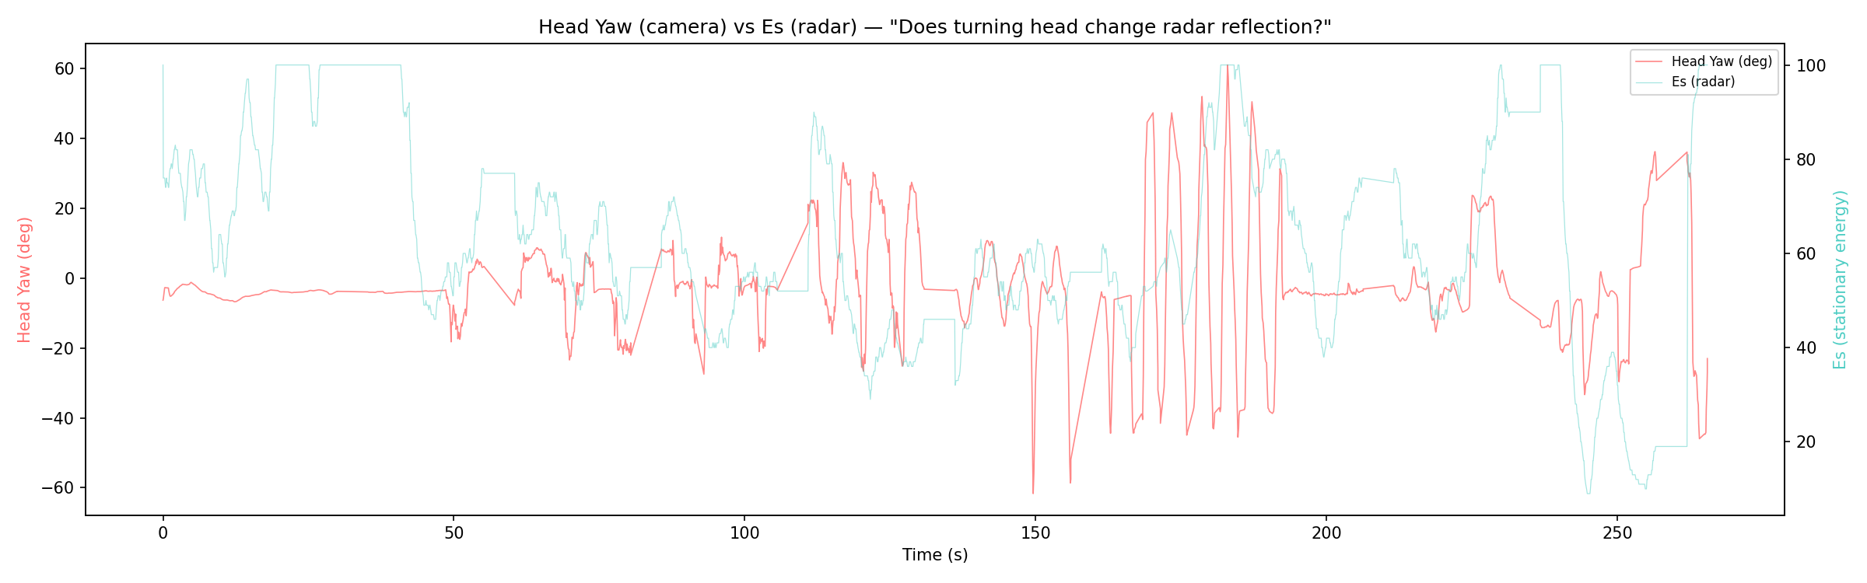
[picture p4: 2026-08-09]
training/analysis/09_yaw_vs_es.png

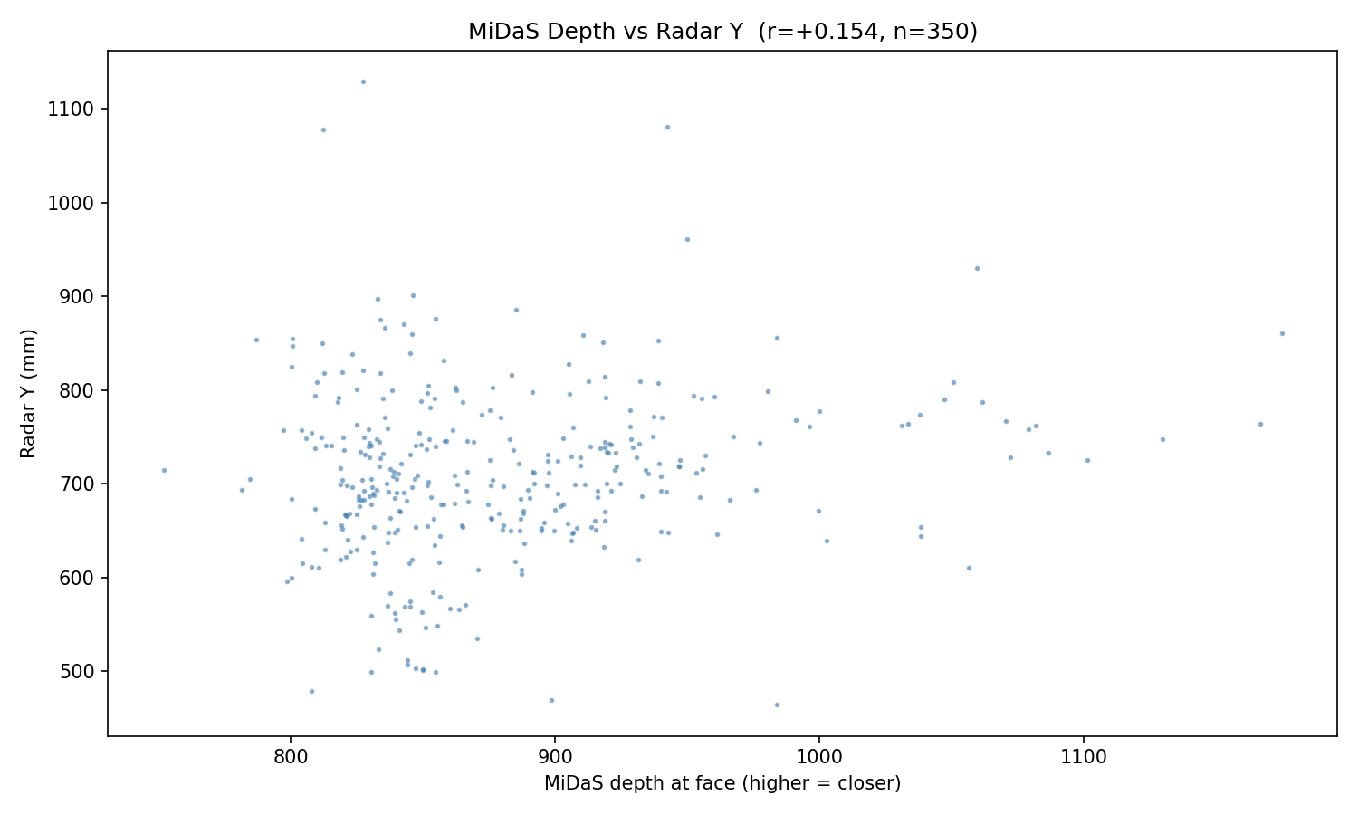
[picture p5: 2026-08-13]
training/analysis/10_depth_vs_y_20260813_165801.png

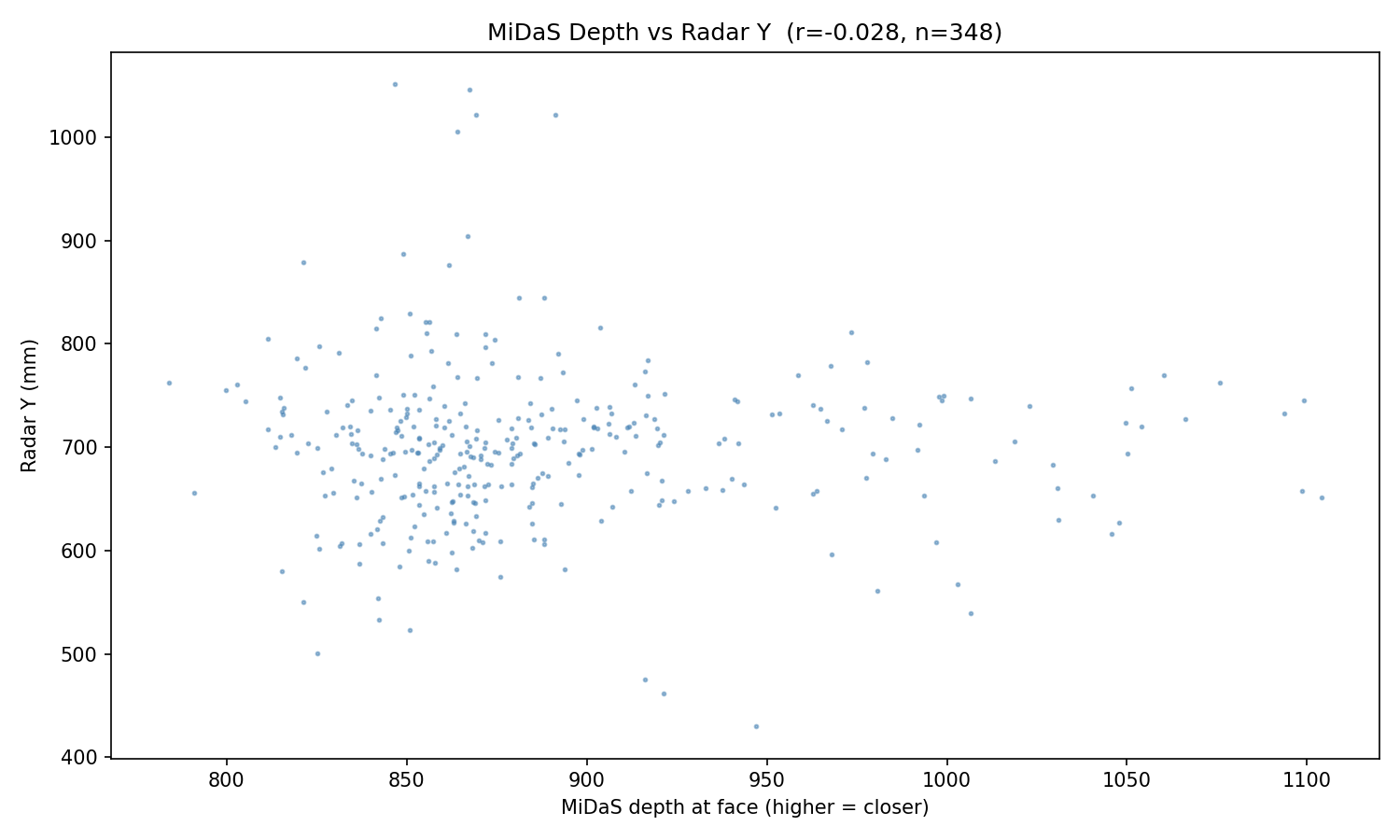
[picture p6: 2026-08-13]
training/analysis/10_depth_vs_y_20260813_170609.png

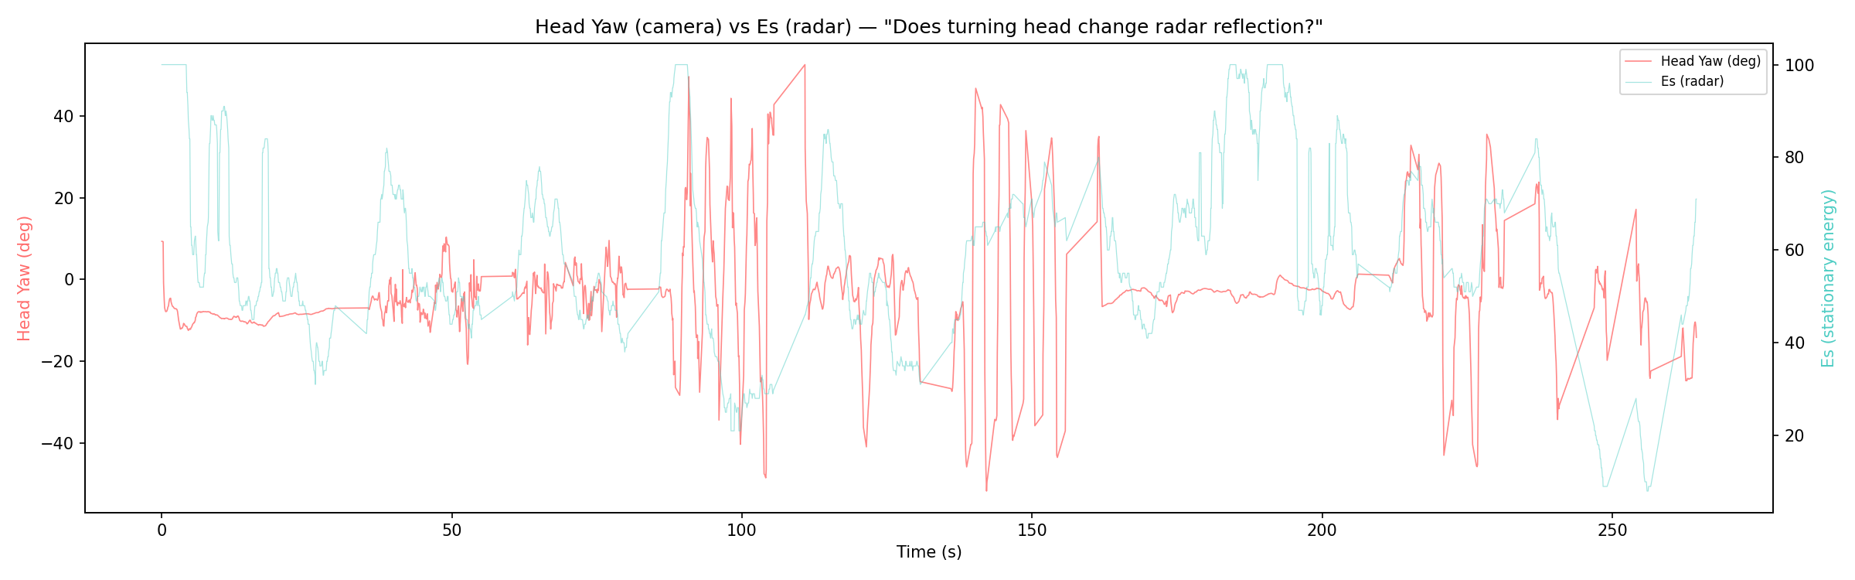
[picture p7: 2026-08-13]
training/analysis/09_yaw_vs_es_20260813_165801.png

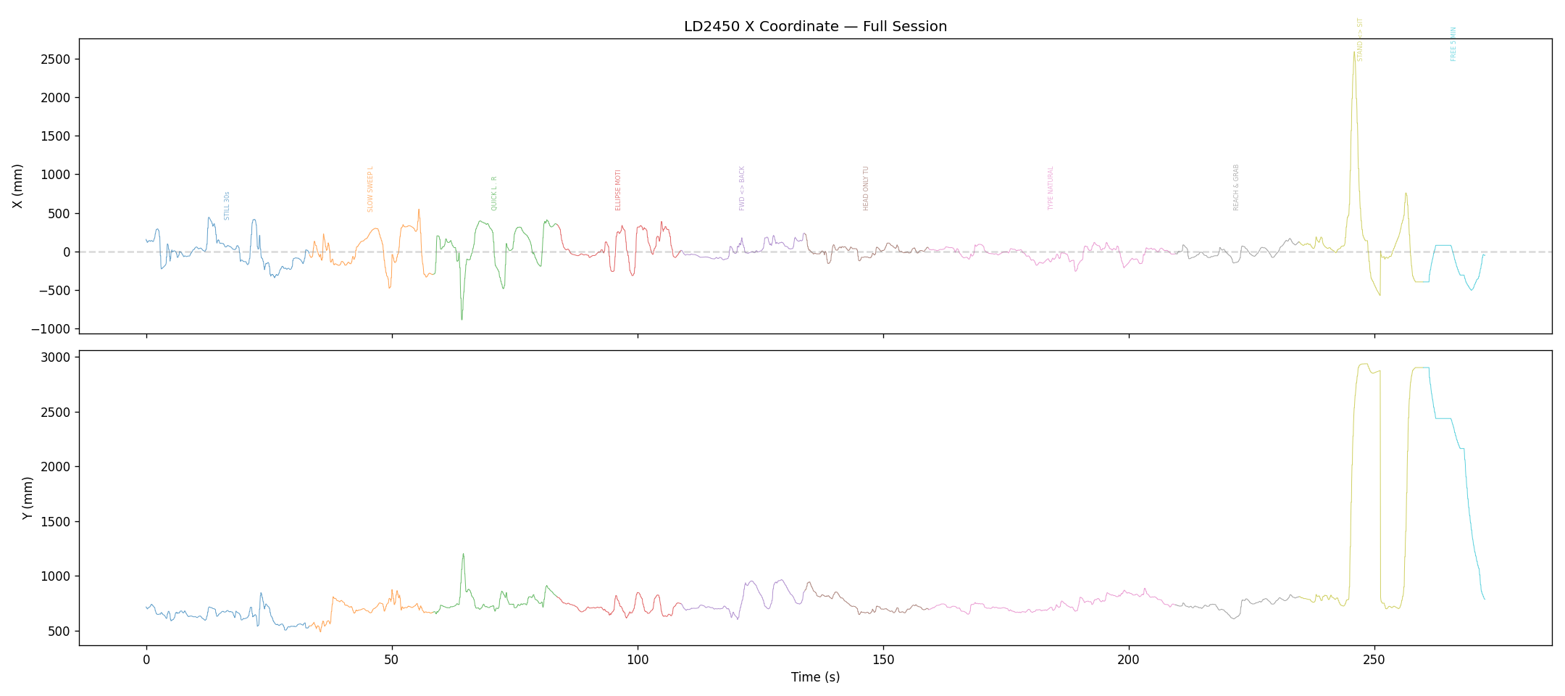
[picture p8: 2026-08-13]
training/analysis/01_timeseries.png

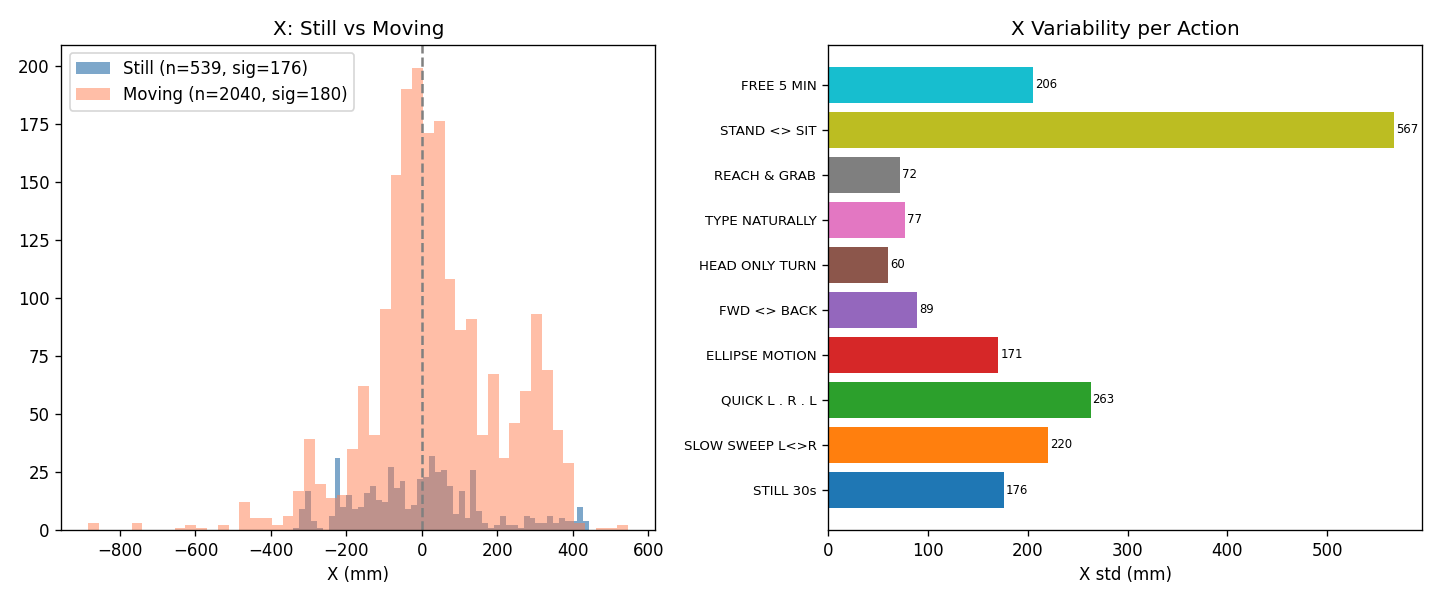
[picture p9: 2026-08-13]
training/analysis/03_still_vs_move.png

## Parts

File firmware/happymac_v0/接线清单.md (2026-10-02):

# HappyMac v0 接线清单

> 整机 = 电池 4000mAh → 充电模块 → 稳压模块(→5V) → ESP32-C3 + F5305S 电源开关 → 双雷达 + OLED + PIR
> 引脚定义与固件 `happymac_v0.ino` 顶部 `#define` 一一对应，改脚位记得两边同步。

## 电源树

```
电池 3.7V(红+黑，第三线 NTC 备用)
  └─► 充电模块 BAT±（永远直连，充电回路不经过任何开关）
        USB 5V ──► 充电模块 IN（充电时插）
        充电 OUT± ──► [可选：全局拨动开关 ≥1A] ──► 稳压模块 IN
                      稳压模块 OUT(5V) ──┬─► ESP32 5V 脚（板载 LDO → 3.3V）
                                          └─► F5305S 模块 IN+/IN-
                                               F5305S OUT+ ──┬─► LD2450 VCC
                                                              └─► LD2410 VCC   ← 被控轨
ESP32 3V3 脚（不受控）──► OLED VCC + PIR VCC
全板 GND 汇共地（ESP32 GND / 模块 GND / 两雷达 GND / OLED GND / PIR GND / F5305S IN-）
```

## 信号线

| 从 | 到 | 线 | 说明 |
|---|---|---|---|
| LD2450 TX | ESP32 **GPIO20** | UART | 雷达数据进（256000 波特） |
| ESP32 **GPIO21** | LD2450 RX | UART | 断电时固件设为高阻（防反灌） |
| LD2410 TX | ESP32 **GPIO4** | UART | |
| ESP32 **GPIO3** | LD2410 RX | UART | 断电时固件设为高阻（防反灌） |
| OLED SDA | ESP32 **GPIO8** | I2C | 注意：GPIO8 是启动模式脚，别接反/接错 |
| OLED SCL | ESP32 **GPIO9** | I2C | 同上 |
| PIR OUT | ESP32 **GPIO5** | 数字 | 高电平=有人；**深度睡眠唤醒脚** |
| F5305S SIG | ESP32 **GPIO1** | 控制 | 高=雷达上电；**串 1kΩ 电阻**（防复位干扰烧录） |

## 电源线

| 从 | 到 | 说明 |
|---|---|---|
| 电池红(+)/黑(-) | 充电模块 BAT± | 三线软包的第三根（NTC 10k 热敏）剪短绝缘收纳，或接充电模块 TEMP 做温控充电 |
| USB 5V | 充电模块 IN | 充电输入；关机状态下插 USB 仍可充电 |
| 充电 OUT± | 稳压模块 IN | 中途可串全局拨动开关（≥1A），只断"用电"不断"充电" |
| 稳压 OUT 5V | ESP32 5V 脚 | |
| 稳压 OUT 5V | F5305S IN+ / IN- | 开关模块供电 |
| F5305S OUT+ | LD2450 VCC、LD2410 VCC | 被控轨：两雷达 VCC 并联（固件 90s 无人断电） |
| ESP32 3V3 | OLED VCC | 不受控 3.3V（I2C 电平合规 + 睡眠呼吸暗脸由固件对比度实现） |
| ESP32 3V3（或 5V） | PIR VCC | 看所用 PIR 模块的宽压范围 |

## 固件引脚对照（.ino 顶部 #define）

| 宏 | GPIO | 方向 | 用途 |
|---|---|---|---|
| PIN_SDA | 8 | I2C | OLED 数据（启动模式脚，接线固定后勿动） |
| PIN_SCL | 9 | I2C | OLED 时钟（同上） |
| PIN_IR | 5 | 输入 | PIR，高=有人；深度睡眠唤醒源 |
| PIN_2410_RX | 4 | 输入 | LD2410 数据进 |
| PIN_2410_TX | 3 | 输出 | LD2410 指令出（断电时设高阻） |
| PIN_2450_RX | 20 | 输入 | LD2450 数据进 |
| PIN_2450_TX | 21 | 输出 | LD2450 指令出（断电时设高阻） |
| PIN_RADAR_PWR | 1 | 输出 | 雷达电源开关，高=上电（串 1k 到模块 SIG） |

## 串口 / 调试

- USB CDC 115200：`STATE/ML/POS/RADAR/ANIM/DIAG` 日志；`!CAL` 重校准、`!DEBUG` 切调试文字层、`!FLIP` 翻转雷达左右、`!PWR` 查电源状态、`!STYLE` 切脸型（经典/戴眼镜的朋友版）
- 深度省电时间线（可调宏）：久坐 5min 无运动渐暗陪伴（`DROWSY_AFTER_MS`，雷达常开）→ 入睡 90s 断雷达（`RADAR_OFF_AFTER_MS`）→ +2min 屏幕全黑（`SCREEN_OFF_AFTER_MS`）→ +20min 深度睡眠（`DEEP_SLEEP_AFTER_MS`，PIR 高电平唤醒=重启）
- 2410 存在判定带能量门槛（运动≥15 / 静止≥20）：空房底噪 es≈8~10 不再算"有人"，防止睡着的机器被幽灵点亮

## 安全与布局要点

- 电池↔充电模块之间不放开关（充电回路常通）；全局硬开关放充电 OUT 之后、稳压之前
- 充电模块是全机最热件（快充 0.8~1.6W）：离电池 ≥25mm + 隔板，热源区开散热孔
- 雷达不直接贴 PLA 壳（留 2~3mm 空气隙，PLA 60°C 软化）；PIR 探头背对机内热源、离充电模块 ≥20mm（防热气流误触发）
- F5305S 模块 IN/OUT 不可接反（反接 = 体内二极管常通，开关失效）

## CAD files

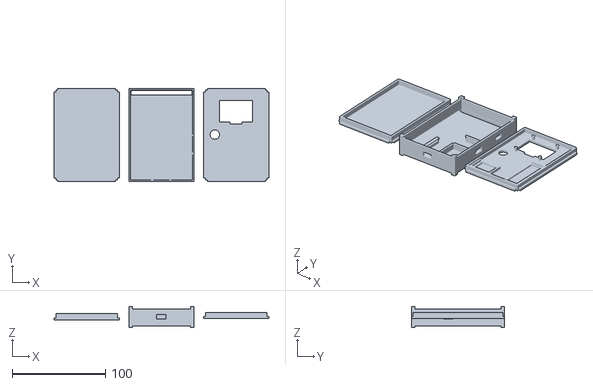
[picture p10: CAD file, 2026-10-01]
hardware/happymac_v01.stl
230.0 x 100.0 x 22.5

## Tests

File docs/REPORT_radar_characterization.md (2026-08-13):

# HappyMac 雷达信号表征实验报告

**日期**: 2026-08-13
**实验者**: Chen Mingyuan
**硬件**: ESP32-C3 SuperMini + HLK-LD2450 (1T2R FMCW) + HLK-LD2410C + ESP32-S3-EYE 摄像头
**软件**: collect_session.py v2 (墙钟时间戳对齐), analyze_session.py, analyze_vision.py (MediaPipe Face Landmarker), analyze_depth.py (MiDaS_small)

---

## 1. 实验目的

系统性表征两个低成本 24GHz 毫米波雷达在**桌面尺度**（0.6-1.2m）下对坐姿人体的感知能力边界，回答三个问题：

1. LD2450 的 X/Y 坐标是否反映真实人体位置？
2. LD2410C 的能量通道（Em/Es）携带什么信息？
3. 哪些信号可用于后续 TinyML 行为分类？

## 2. 实验设计

### 2.1 数据采集协议

每 session 包含 10 个阶段（9 个有效 + 1 个被弃用的自由段）：

| 阶段 | 时长 | 行为 |
|---|---|---|
| still_30s | 30s | 静止坐姿 |
| slow_sweep | 20s | 缓慢连续左右摆动 |
| quick_points | 20s | 快速定点左右移动 |
| ellipse | 20s | 上半身椭圆运动 |
| fwd_back | 20s | 前倾/后靠 |
| head_only | 20s | 身体静止，仅转头 |
| natural_typing | 45s | 自然打字 |
| natural_reach | 20s | 伸手取物 |
| stand_sit | 20s | 站起/坐下 |

### 2.2 关键实验控制

- **雷达预热**：每次 session 前雷达静置 ≥3 分钟（冷启动漂移期已提前识别并排除）
- **时间戳对齐**：雷达串口与摄像头 MJPEG 流均以采集计算机的墙钟（`time.time()`）打戳，配对窗口 150ms。延迟扫描确认无残留系统偏移（0ms 时相关性最优）
- **重复性**：完整 protocol 重复 3 次（20260813_160414 / 165801 / 170609）
- **排除项**：`free_5min` 自由段因被试未及时终止被截断，全部分析中排除

### 2.3 验证基准

- **横向位置基准**：MediaPipe Face Landmarker（468 关键点）提取脸部中心 `head_x`（归一化 -0.5~+0.5）
- **距离基准**：MiDaS_small 单目深度估计（intel-isl/MiDaS，PyTorch Hub），取脸部中心 11×11 邻域中位数；MiDaS 输出"越近值越大"，雷达 Y"越近值越小"，故**预期负相关**

## 3. 结果

### 3.1 LD2450 X 轴：横向位置追踪（弱但可重复）

MediaPipe 脸部横向位置与雷达 X 的 Pearson 相关：

| Session | r(X) | 对齐对数 |
|---|---|---|
| 160414 | +0.207 | 2164 |
| 165801 | +0.166 | 2052 |
| 170609 | +0.181 | 2015 |
| **均值** | **+0.185** | — |

**结论：三次实验符号一致为正，均值 r≈+0.18。雷达 X 确实携带横向位置信息，但相关性弱——绝对定位不可靠。**

分段分析（session 1）显示信号主要集中在预期阶段：

| 阶段 | r(X) | 解读 |
|---|---|---|
| slow_sweep | +0.447 | 慢速横向移动时追踪最强 |
| head_only | +0.228 | 转头产生 X 响应 |
| stand_sit | +0.229 | 站起/坐下伴随 X 变化 |
| still_30s | -0.218 | 静止期 X 漂移与头部位置反相关 |

**静止漂移是 X 不可靠的根源**：静止 30 秒内 X 漂移均值 128mm（σ），与缓慢人体移动幅度同量级。漂移源于 6.25mm 天线基线的相位干涉测角在多径环境下的相位中心游移。

### 3.2 LD2450 Y 轴：距离测量（MiDaS 验证结果不一）

MiDaS 深度 vs 雷达 Y 的 Pearson 相关（预期负相关）：

| 阶段 | S1 | S2 | S3 |
|---|---|---|---|
| fwd_back | **-0.534** | +0.015 | -0.208 |
| natural_typing | -0.533 | +0.138 | -0.066 |
| slow_sweep | -0.349 | -0.107 | -0.126 |
| ellipse | +0.374 | +0.472 | +0.324 |
| still_30s | -0.184 | -0.257 | +0.179 |

**S1 的前后移动阶段显示强负相关（-0.53），符合物理预期，但 S2/S3 未复现。** 可能原因：(a) MiDaS 相对深度在近距场景的尺度不稳定性；(b) 单目深度对坐姿人体躯干变化敏感而雷达 Y 测的是最近强反射体，两者物理量不完全同构。Y 通道在 phase-level 统计（Y_std：stand_sit 438mm vs head_only 51mm）上仍显示符合物理的响应模式，但其绝对数值与视觉深度的线性关系未获稳定验证。

### 3.3 LD2410C：Es 数值是姿态特征，Em 桌面场景无效，朝向感知不存在

**Es 数值（非二值存在）按行为系统性变化**（三次平均）：

| 行为 | Es 均值 |
|---|---|
| natural_typing | 72.8 |
| head_only | 69.8 |
| still_30s | 63.9 |
| slow_sweep | 61.6 |
| quick_points | 59.1 |
| ellipse | 55.7 |
| fwd_back | 44.2 |
| stand_sit | 39.4 |

近 2 倍动态范围（39-73）。打字/只转头（上身稳定）时 Es 最高；站起坐下（身体形态剧变）时最低。**Es 数值可作为身体姿态的弱特征**，与 X/Y 联合供 TinyML 使用。

**Em 移动能量在桌面尺度基本失效**：三次平均触发率仅 2-6%（前倾后靠也只有 6%）。原因：LD2410C 出厂参数面向房间尺度（3-5m）设计，0.6-1m 近距离人体"太大、太近"，移动检测门控难以区分。

**Es 与头部朝向（MediaPipe head_yaw）相关系数三次均为 |r|<0.12**：LD2410C 在桌面场景**无法感知头部朝向**。"通过 Es 判断用户是否看向设备"的设计假设被实验证伪。

### 3.4 X 稳定性：移动优于静止的反直觉现象

跨三次平均的 X 标准差：

| 行为 | X σ (mm) |
|---|---|
| stand_sit | 482 |
| slow_sweep | 218 |
| quick_points | 212 |
| ellipse | 158 |
| still_30s | 128 |
| natural_reach | 100 |
| natural_typing | 84 |
| fwd_back | 86 |
| head_only | 79 |

**持续运动（慢扫/快速定点）的 X σ 显著高于静止漂移基线（1.7x），说明运动信号可区分于漂移。** 但注意 still_30s 的 128mm 基线本身就是"噪声地板"，任何依赖 X 绝对值的单帧分类都不可行；只有时间窗口内的趋势模式（斜率、方差）才携带可用信息。

## 4. 讨论

### 4.1 对 TinyML 管线的影响

1. **可用特征收窄**：X 趋势（slope）、Y 距离、Es 数值、V（速度）四类信号有效；X 绝对值、Em、Es 朝向无效
2. **模型必须学到"何时信任 X"**：静止期 X 漂移与运动期 X 信号在单帧上不可分，但时间序列模式（持续同向 vs 随机游走）可被窗口特征捕获
3. **Es 数值升格**：从"存在检测器"升格为"姿态弱特征"，应纳入特征集并做消融实验验证贡献

### 4.2 与文献的一致性

- LD2450 静止目标检测不可靠、多径鬼影：与 ESPHome/Home Assistant 社区报告一致（esphome issue #9847 等）
- 24GHz 雷达 X 轴漂移的定量化（128mm/30s @0.7m）：本文贡献，未见公开数据
- 旋转敏感于平移的现象（head_only σ=79 vs still 漂移 128）：此前 session 曾观察到 head_only X 变化显著大于平移，本次未复现，标记为待进一步验证

### 4.3 局限

- n=1 被试，仅单一体型/坐姿
- MiDaS 单目深度为相对尺度，无法给出绝对距离验证
- 三次 session 时间跨度 ~1 小时，未覆盖跨日/跨光照条件
- 双雷达同频干扰未做 AB 对照（本次实验两雷达同时开启）

## 5. 结论

1. **LD2450 X 轴**：横向追踪信号真实存在（r≈+0.18，三 session 可重复）但被静止漂移（σ=128mm）淹没，仅趋势可用
2. **LD2450 Y 轴**：phase-level 统计符合物理预期；与单目深度的线性关系未获稳定验证，需双目/ToF 基准进一步确认
3. **LD2410C**：Es 数值是有效姿态特征（动态范围 ~2x），Em 桌面无效，头部朝向感知被证伪
4. **TinyML 路线**：以 X 趋势 + Y + Es 数值 + V 为特征集，时间窗口统计特征 + MLP 分类是合理路径；下一步应做 RF baseline 验证特征可分性

## 附录

- 每 session 每阶段完整统计：`training/analysis/appendix_per_session.json`
- 三次平均统计：`training/analysis/multi_session_summary.json`
- 雷达侧图集：`training/analysis/01-06, 11_*.png`
- 视觉验证图：`training/analysis/07-09_*_<session>.png`
- 深度验证图：`training/analysis/10_depth_vs_y_<session>.png`

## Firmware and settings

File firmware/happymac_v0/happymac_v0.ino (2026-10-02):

// ============================================================
// HappyMac v0 — 规则版产品固件
//
// 目的：先完成“装进外壳后能活起来”的初版，不依赖摄像头和 ML。
// 研究采集固件仍保留在 ../new_radar/new_radar.ino。
//
// 状态：
//   SLEEP    无目标一段时间，低亮度呼吸
//   GOODBYE  刚刚失去目标，短暂目送
//   WAKING   目标重新出现，慢慢睁眼
//   IDLE     有人但动作很小，正常待机
//   ACTIVE   有明显移动，眼睛睁大
//   APPROACH 目标距离变近，惊讶
//   RETREAT 目标距离变远，目送
//
// 左右跟随不是状态，而是连续的 faceLook 参数，避免表情跳变。
// 睡前过渡链（一次性事件动画）：无人 2.5s 后 打哈欠→揉眼→渐暗→入睡，
// 期间有人回来随时打断。事件只做帧内表情覆盖，不锁状态。
// ============================================================

#include <Arduino.h>
#if defined(ARDUINO_USB_CDC_ON_BOOT) && ARDUINO_USB_CDC_ON_BOOT
#include "USBCDC.h"
#endif
#include <Wire.h>
#include <Preferences.h>
#include <esp_sleep.h>
#include "driver/gpio.h"
#include <U8g2lib.h>
#include <ld2410.h>
#include <HardwareSerial.h>
#include "tinyml_v0_tree_d4.h"

// ─── 引脚，与采集固件保持一致 ────────────────────────
#define PIN_SDA       8
#define PIN_SCL       9
#define PIN_IR        5
#define PIN_2410_RX   4
#define PIN_2410_TX   3
#define PIN_2450_RX   20
#define PIN_2450_TX   21
#define RADAR_BAUD    256000
#define FW_VERSION    "0.1"    // 固件版本（启动日志与发布标签）

#define EMA_A         0.55f
#define DISPLAY_MS    80       // 约 12.5Hz；与采集固件一致，给 100kHz I²C 留余量
#define ABSENT_MS     8000     // 8 秒无人后睡眠
#define GOODBYE_MS    1800
#define WAKING_MS     1800
#define STATE_HOLD_MS 450
#define ML_WINDOW_MS  2000
#define ML_MIN_SAMPLES 20
#define ML_RING_CAP   64
#define ML_CONFIRM_MS 2000
#define V_NOISE_FLOOR 8.0f
#define PRESENCE_DEBOUNCE_MS 500
#define DEBUG_ANIM_LOG_MS 100
#define POSITION_ENTER_PX 170.0f
#define POSITION_EXIT_PX  80.0f
#define LOOK_MAX_PX       30.0f
#define LOOK_NORMAL_PX    24.0f
#define LOOK_NORMAL_INPUT 700.0f
#define LOOK_EXTREME_INPUT 1400.0f
#define BLINK_DURATION_MS 180
#define EYE_WIDTH_PX      8
#define EYE_MAX_HEIGHT_PX 14
#define LOOK_DEADZONE_MM  80.0f
#define LOOK_TARGET_ALPHA 0.08f
#define LOOK_MOVE_ALPHA   0.06f
#define LOOK_MAX_STEP_PX  0.55f
#define ATTENTION_DRIFT_PX 1.5f
#define Y_TREND_SAMPLE_MS 140
#define Y_TREND_ALPHA     0.28f
#define Y_TREND_TRIGGER_MM 15.0f
#define Y_TREND_RELEASE_MM 6.0f   // 事件后趋势回落到此值以内才重新武装
#define TRANSIENT_HOLD_MS 900
#define TRANSIENT_COOLDOWN_MS 400
// 运动判定：近距静态噪声 σ≈100mm，单帧硬阈值必然误触发。改为逐帧证据
// 积分 + 进入/退出双阈值，进入要连续多帧证据，退出要持续安静。
#define MOTION_SPEED_TH   15.0f    // 滤波速度阈值，放在静态噪声带之上
#define MOTION_REF_MS     700      // 位移参考点的采样间隔
#define MOTION_DELTA_MM   130.0f   // 参考间隔内滤波位移超过此值算一份移动证据
#define MOTION_SCORE_MAX  8
#define MOTION_ENTER_SCORE 4       // 连续约 0.5s 的证据才进入“在动”
#define MOTION_EXIT_SCORE  1       // 持续安静后才退出“在动”
#define R10_MOV_MIN_E      15      // 2410 运动存在能量门槛：低于此视为底噪（真实走动 30+，空房底噪 8~10）
#define R10_STAT_MIN_E     20      // 2410 静止存在能量门槛：真人静坐 30~40，“幽灵”就是 8~10 的底噪过闸
#define SMILE_ENTER_MS    600      // ACTIVE 持续这么久嘴才笑：短暂误进不闪嘴
#define SMILE_MIN_MS      1500     // 笑容最短保持时间，防止嘴型反复横跳
#define HAPPY_EYES_MS     800      // 笑开始时 ^ 眼的持续时间，之后眼睛恢复睁开（嘴继续笑）
#define WINK_COOLDOWN_MS      45000  // wink 最短间隔：特殊表情克制用
#define WINK_COOLDOWN_JITTER  45000  // 附加随机 0~45s → 实际 45~90s 一次
#define SMIRK_COOLDOWN_MS     20000  // 好奇歪嘴+单眉最短间隔
#define SMIRK_COOLDOWN_JITTER 15000  // 附加随机 0~15s → 实际 20~35s 一次
#define PIN_RADAR_PWR        1       // 雷达电源开关（GPIO1，高=上电，经 F5305S 高边模块）
#define RADAR_OFF_AFTER_MS   90000   // SLEEP 后无人 90s → 断雷达电，只留红外待机
#define SCREEN_OFF_AFTER_MS  120000  // 断雷达后再 2min 无人 → 屏幕全黑（SH1106 显示关闭）
#define RADAR_WARMUP_MS      5000    // 雷达上电预热：期间数据不可信，只信红外
#define DEEP_SLEEP_AFTER_MS  1200000 // 关屏后再 20min 无人 → 深度睡眠（PIR 唤醒=重启）
#define DROWSY_AFTER_MS      300000  // 久坐犯困：有人但连续 5min 无运动 → 渐暗陪伴（雷达常开不关）
#define DROWSY_DIM_MS        5000    // 犯困渐暗斜坡时长
#define DROWSY_CONTRAST      45      // 犯困亮度下限（与睡前渐暗终点一致）
#define BEDTIME_YAWN_AT   2500     // 无人 2.5s 后开始睡前链（在 GOODBYE 目送之后）
#define BEDTIME_YAWN_MS   2000
#define BEDTIME_RUB_MS    1500
#define BEDTIME_DIM_MS    1200     // 渐暗结束转 SLEEP（合计 last_seen+7.2s，早于 8s 兜底）

U8G2_SH1106_128X64_NONAME_F_HW_I2C oled(U8G2_R0, U8X8_PIN_NONE);
ld2410 radar2410;
HardwareSerial radar2450(0);

// ─── LD2450 ──────────────────────────────────────────
int16_t r50_x = 0, r50_y = 0, r50_v = 0;
bool x_invert = true;  // 当前安装朝向下 raw x 与"偏左为负"约定相反，parse 时取反；重装雷达后若方向再反，串口 !FLIP 切换
bool face_style_friend = false;  // 脸型：false=经典初版（无眼镜，特殊动作才出眉）作 default；true=一个戴眼镜的朋友版；串口 !STYLE 切换
bool r50_ok = false;
uint32_t r50_last = 0;
float flt_x = 0, flt_y = 0;
float prev_y = 0;
bool filter_ok = false;
float center_x = 0;
bool center_ok = false;
uint32_t r50_seq = 0;
float y_trend_sample = 0;
float y_step_filtered = 0;
uint32_t y_trend_sample_at = 0;
bool y_trend_ready = false;
bool y_trend_armed = true;
float flt_v = 0;
float motion_ref_x = 0, motion_ref_y = 0;
uint32_t motion_ref_at = 0;
int8_t motion_score = 0;
bool motion_stable = false;
uint32_t last_motion_at = 0;   // 最近一次运动证据时刻（久坐犯困计时）
bool drowsy = false;           // 久坐犯困态：在场但久无运动，屏渐暗、雷达常开
uint32_t drowsy_since = 0;

struct MlSample {
  uint32_t t;
  int16_t x;
  int16_t y;
  int16_t v;
  uint16_t es;
};

MlSample ml_ring[ML_RING_CAP];
uint8_t ml_head = 0;
uint8_t ml_count = 0;
uint32_t ml_seq_seen = 0;
uint8_t ml_candidate = 255;
uint8_t ml_stable = 255;
uint32_t ml_candidate_since = 0;
uint32_t last_ml_log = 0;

// ─── LD2410C / SR602 ─────────────────────────────────
int r10_em = 0, r10_es = 0;
bool r10_pres = false;
bool ir_present = false;

uint8_t frame_buf[64];
int frame_i = 0;

enum HappyState {
  HM_SLEEP,
  HM_GOODBYE,
  HM_WAKING,
  HM_IDLE,
  HM_ACTIVE,
  HM_APPROACH,
  HM_RETREAT
};

// Model A v0：位置模型只输出左右位置，不参与状态判断。
enum PositionClass {
  POS_CENTER,
  POS_LEFT,
  POS_RIGHT
};

HappyState state = HM_SLEEP;
HappyState previous_state = HM_SLEEP;
uint32_t state_since = 0;
uint32_t last_seen = 0;
uint32_t last_display = 0;
uint32_t last_state_log = 0;
bool had_target = false;
bool stable_presence = false;
uint32_t presence_candidate_since = 0;
bool debug_overlay = false;   // 默认只显示表情；串口发 !DEBUG 可临时打开 S:/A: 文字层
int oled_contrast = -1;
uint32_t last_contrast_update = 0;
uint32_t last_diag_log = 0;
uint32_t last_loop_ms = 0;
uint32_t max_loop_gap_ms = 0;
uint32_t last_draw_ms = 0;
uint32_t max_draw_ms = 0;
uint32_t slow_draw_count = 0;

char command_buf[24];
uint8_t command_i = 0;

// 动画参数：以屏幕中心为 0，范围约 ±6px。
float face_look = 0;
float face_look_target = 0;
float face_breath = 0;
float face_breath_target = 0;
float y_delta = 0;
PositionClass model_a_position = POS_CENTER;
PositionClass model_a_previous = POS_CENTER;
float model_a_direction = 0.0f;
float attention_offset = 0.0f;
float attention_target = 0.0f;
uint32_t attention_until = 0;
uint32_t next_attention_at = 7000;
uint8_t attention_sequence = 0;
int8_t nose_direction = -1;  // 只改变底部横线方向，竖线保持不变
uint32_t transient_until = 0;
uint32_t transient_cooldown_until = 0;
bool blink_active = false;
uint32_t blink_started = 0;
uint32_t next_blink_at = 5200;
uint8_t blink_sequence = 0;
uint8_t blink_count = 0;   // 眨眼计数：每 4 次的最后一次为单眼 wink（左右交替）
uint8_t blink_eye = 0;     // 0=双眼 1=左眼 2=右眼
uint32_t happy_until = 0;  // 笑开始时 ^ 眼的结束时间戳（0=未在笑）
uint32_t last_wink_ms = 0;    // 上次 wink 时刻（冷却用）
uint32_t last_smirk_ms = 0;   // 上次好奇歪嘴+单眉时刻（冷却用）
bool smirk_granted = false;   // 本次注意力漂移是否获准播放歪嘴+挑眉
int8_t smirk_side = 0;        // 漂移/歪嘴侧：1=右 -1=左
bool attention_prev_target = false;  // 上一帧 attention_target 非零？（漂移上升沿检测）
bool radar_powered = true;    // 雷达供电状态（F5305S 高边开关）
bool screen_off = false;      // 屏幕全黑（SH1106 setPowerSave(1)）
uint32_t radar_on_at = 0;     // 雷达上电时刻（预热计时）
uint32_t screen_off_at = 0;   // 屏幕全黑时刻（深度睡眠计时）
uint32_t smile_until = 0;
uint32_t smile_pending_since = 0;

// 一次性事件动画：帧内覆盖表情，播完回姿态层，不锁状态。
enum OneShotEv { EV_NONE, EV_YAWN, EV_RUB, EV_DIM };
OneShotEv ev_cur = EV_NONE;
uint32_t ev_started = 0;
int mouth_mode = 0;   // 0 平嘴 1 微笑 2 哈欠
int eye_wiggle = 0;

const char* evName(OneShotEv e) {
  switch (e) {
    case EV_YAWN: return "YAWN";
    case EV_RUB:  return "RUB";
    case EV_DIM:  return "DIM";
    default:      return "-";
  }
}

const char* positionClassName(PositionClass p) {
  switch (p) {
    case POS_LEFT:   return "LEFT";
    case POS_RIGHT:  return "RIGHT";
    default:         return "CENTER";
  }
}

const char* stateName(HappyState s) {
  switch (s) {
    case HM_SLEEP:    return "SLEEP";
    case HM_GOODBYE:  return "GOODBYE";
    case HM_WAKING:   return "WAKING";
    case HM_IDLE:     return "IDLE";
    case HM_ACTIVE:   return "ACTIVE";
    case HM_APPROACH: return "APPROACH";
    case HM_RETREAT:  return "RETREAT";
  }
  return "UNKNOWN";
}

// 每收到一帧有效雷达报告积分一次运动证据：单帧噪声只贡献 ±1，
// 真实移动会连续累积，跨过进入阈值后才切换运动状态。
void updateMotionEvidence() {
  uint32_t now = millis();
  if (motion_ref_at == 0) {
    motion_ref_x = flt_x;
    motion_ref_y = flt_y;
    motion_ref_at = now;
    return;
  }
  bool evidence = fabsf(flt_v) > MOTION_SPEED_TH ||
                  fabsf(flt_x - motion_ref_x) > MOTION_DELTA_MM ||
                  fabsf(flt_y - motion_ref_y) > MOTION_DELTA_MM;
  motion_score += evidence ? 1 : -1;
  if (evidence) last_motion_at = now;
  if (motion_score < 0) motion_score = 0;
  if (motion_score > MOTION_SCORE_MAX) motion_score = MOTION_SCORE_MAX;
  if (!motion_stable && motion_score >= MOTION_ENTER_SCORE) {
    motion_stable = true;
  } else if (motion_stable && motion_score <= MOTION_EXIT_SCORE) {
    motion_stable = false;
  }
  if (now - motion_ref_at >= MOTION_REF_MS) {
    motion_ref_x = flt_x;
    motion_ref_y = flt_y;
    motion_ref_at = now;
  }
}

void parse2450() {
  while (radar2450.available()) {
    frame_buf[frame_i++] = radar2450.read();
    if (frame_i >= 30) {
      bool valid = frame_buf[0] == 0xAA && frame_buf[1] == 0xFF &&
                   frame_buf[2] == 0x03 && frame_buf[3] == 0x00 &&
                   frame_buf[28] == 0x55 && frame_buf[29] == 0xCC;
      if (valid) {
        r50_ok = false;
        for (int t = 0; t < 3; t++) {
          int o = 4 + t * 8;
          int16_t rx = frame_buf[o] | frame_buf[o + 1] << 8;
          int16_t ry = frame_buf[o + 2] | frame_buf[o + 3] << 8;
          int16_t rv = frame_buf[o + 4] | frame_buf[o + 5] << 8;
          int x = (rx & 0x8000) ? (rx & 0x7FFF) : -(rx & 0x7FFF);
          int y = (ry & 0x8000) ? (ry & 0x7FFF) : -(ry & 0x7FFF);
          int v = (rv & 0x8000) ? (rv & 0x7FFF) : -(rv & 0x7FFF);
          if (!(x == 0 && y == 0)) {
            r50_x = x_invert ? -x : x; r50_y = y; r50_v = v; r50_ok = true;
            if (!filter_ok) {
              flt_x = x; flt_y = y; prev_y = y;
              flt_v = v;
              filter_ok = true;
            } else {
              prev_y = flt_y;
              flt_x = EMA_A * x + (1.0f - EMA_A) * flt_x;
              flt_y = EMA_A * y + (1.0f - EMA_A) * flt_y;
              flt_v = 0.35f * v + 0.65f * flt_v;
            }
            if (!center_ok) {
              center_x = flt_x;
              center_ok = true;
            }
            break;
          }
        }
        r50_last = millis();
        r50_seq++;
        updateMotionEvidence();
        frame_i = 0;
      } else {
        memmove(frame_buf, frame_buf + 1, --frame_i);
      }
    }
  }
}

// ── 深度省电：红外独守 → 断雷达 → 关屏 ──────────────────
void radarPowerOff() {
  digitalWrite(PIN_RADAR_PWR, LOW);        // 断两雷达 VCC
  radar_powered = false;
  pinMode(PIN_2450_TX, INPUT);             // 串口输出脚设高阻，防 3.3V 反灌断电侧
  pinMode(PIN_2410_TX, INPUT);
  r50_ok = false; r10_pres = false; r10_em = 0; r10_es = 0;
  if (Serial && Serial.availableForWrite() > 32) Serial.println("POWER,RADAR_OFF");
}

void radarPowerOn() {
  pinMode(PIN_2450_TX, OUTPUT);            // 恢复串口脚
  pinMode(PIN_2410_TX, OUTPUT);
  digitalWrite(PIN_RADAR_PWR, HIGH);       // 上电
  radar_powered = true;
  radar_on_at = millis();
  center_ok = false;                       // 断电后滤波数据不可信，重新校准中心
  radar2410.begin(Serial1);                // 2410 重新初始化握手
  if (Serial && Serial.availableForWrite() > 32) Serial.println("POWER,RADAR_ON");
}

void updatePower() {
  uint32_t now = millis();

  // 睡眠两段深度省电：90s 无人断雷达 → 再 2min 关屏幕
  if (state == HM_SLEEP && !screen_off) {
    if (radar_powered && now - state_since >= RADAR_OFF_AFTER_MS) radarPowerOff();
    if (!radar_powered && now - state_since >= RADAR_OFF_AFTER_MS + SCREEN_OFF_AFTER_MS) {
      oled.setPowerSave(1);                // SH1106 显示关闭：全黑、~0.1mA
      screen_off = true;
      screen_off_at = now;
      if (Serial && Serial.availableForWrite() > 32) Serial.println("POWER,SCREEN_OFF");
    }
  }

  // 第四阶段：关屏 30min 仍无人 → 深度睡眠（PIR GPIO5 高电平唤醒=重启，setup 全新初始化）
  if (screen_off && now - screen_off_at >= DEEP_SLEEP_AFTER_MS) {
    if (Serial && Serial.availableForWrite() > 32) Serial.println("POWER,DEEP_SLEEP");
    Serial.flush();
    digitalWrite(PIN_RADAR_PWR, LOW);      // 雷达保持断电
    gpio_hold_en(GPIO_NUM_1);              // 深睡期间锁存低电平（防栅极悬空被信号线反灌）
    gpio_deep_sleep_hold_en();
    esp_deep_sleep_enable_gpio_wakeup(1ULL << 5, ESP_GPIO_WAKEUP_GPIO_HIGH);   // C3 专用 API：PIR(GPIO5) 高电平唤醒（唤醒=重启）
    esp_deep_sleep_start();                // 不返回；唤醒后从 setup() 重新开始
  }

  // 唤醒：红外发现人 → 屏幕先亮，雷达上电预热（数据预热期后可信）
  if ((screen_off || !radar_powered) && ir_present) {
    if (screen_off) {
      oled.setPowerSave(0);
      screen_off = false;
      if (Serial && Serial.availableForWrite() > 32) Serial.println("POWER,SCREEN_ON");
    }
    if (!radar_powered) radarPowerOn();
  }

  // 久坐犯困：有人但久无运动 → 渐暗陪伴；雷达常开（人在场不断电），一动/红外一闪即醒。
  // quiet 判定刻意不含 r10_pres：幽灵存在不允许点亮或打断犯困。
  if (state == HM_IDLE && targetPresent()) {
    bool quiet = !motion_stable && !ir_present;
    if (!drowsy && quiet && now - last_motion_at >= DROWSY_AFTER_MS) {
      drowsy = true; drowsy_since = now;
      if (Serial && Serial.availableForWrite() > 32) Serial.println("POWER,DROWSY");
    } else if (drowsy && !quiet) {
      drowsy = false;
      if (Serial && Serial.availableForWrite() > 32) Serial.println("POWER,DROWSY_OFF");
    }
  } else if (drowsy) {
    drowsy = false;
    if (Serial && Serial.availableForWrite() > 32) Serial.println("POWER,DROWSY_OFF");
  }
}

void readSensors() {
  ir_present = digitalRead(PIN_IR) == HIGH;
  if (ir_present) last_motion_at = millis();   // 红外=运动证据，刷新久坐计时
  if (!radar_powered) {                    // 红外独守待机：两雷达断电，数据全失效
    r50_ok = false; r10_pres = false; r10_em = 0; r10_es = 0;
    if (!r50_ok && motion_score > 0) {
      motion_score--;
      if (motion_stable && motion_score <= MOTION_EXIT_SCORE) motion_stable = false;
    }
    return;
  }
  radar2410.read();
  r10_em = radar2410.movingTargetEnergy();
  r10_es = radar2410.stationaryTargetEnergy();
  // 幽灵存在修复：库的检出标志连空房底噪（es 8~10）都会翻真，须乘能量门槛。
  r10_pres = (radar2410.movingTargetDetected() && r10_em >= R10_MOV_MIN_E) ||
             (radar2410.stationaryTargetDetected() && r10_es >= R10_STAT_MIN_E);
  ir_present = digitalRead(PIN_IR) == HIGH;

  parse2450();
  if (r50_ok && millis() - r50_last > 500) r50_ok = false;
  if (radar_powered && millis() - radar_on_at < RADAR_WARMUP_MS) {  // 上电预热：数据不可信，只信红外
    r50_ok = false; r10_pres = false;
  }
  // 雷达失联时让运动证据自然衰减，避免运动状态挂在过期数据上。
  if (!r50_ok && motion_score > 0) {
    motion_score--;
    if (motion_stable && motion_score <= MOTION_EXIT_SCORE) motion_stable = false;
  }
}

bool targetPresent() {
  return r50_ok || r10_pres || ir_present;
}

bool stableTargetPresent() {
  uint32_t now = millis();
  bool raw = targetPresent();
  if (raw == stable_presence) {
    presence_candidate_since = 0;
    return stable_presence;
  }
  if (presence_candidate_since == 0) presence_candidate_since = now;
  if (now - presence_candidate_since >= PRESENCE_DEBOUNCE_MS) {
    stable_presence = raw;
    presence_candidate_since = 0;
  }
  return stable_presence;
}

bool targetMoving() {
  // 已经是积分 + 滞回后的稳定判定，单帧噪声不再直接翻动状态。
  if (!r50_ok) return false;
  return motion_stable;
}

void updateYTrend(uint32_t now) {
  if (!r50_ok) {
    y_trend_ready = false;
    y_step_filtered = 0.0f;
    return;
  }
  if (!y_trend_ready) {
    y_trend_sample = flt_y;
    y_trend_sample_at = now;
    y_trend_ready = true;
    return;
  }
  if (now - y_trend_sample_at < Y_TREND_SAMPLE_MS) return;

  float step = flt_y - y_trend_sample;
  y_step_filtered += (step - y_step_filtered) * Y_TREND_ALPHA;
  y_trend_sample = flt_y;
  y_trend_sample_at = now;
}

const char* positionLabel() {
  if (!r50_ok) return "NONE";
  return positionClassName(model_a_position);
}

void updateModelA() {
  if (!r50_ok || state == HM_SLEEP || !center_ok) {
    model_a_position = POS_CENTER;
    model_a_direction *= 0.90f;
    return;
  }

  float delta = flt_x - center_x;
  // 进入阈值和退出阈值分开，避免人在边界附近时左右抖动。
  if (model_a_position == POS_LEFT) {
    if (delta > -POSITION_EXIT_PX) model_a_position = POS_CENTER;
  } else if (model_a_position == POS_RIGHT) {
    if (delta < POSITION_EXIT_PX) model_a_position = POS_CENTER;
  } else {
    if (delta < -POSITION_ENTER_PX) model_a_position = POS_LEFT;
    else if (delta > POSITION_ENTER_PX) model_a_position = POS_RIGHT;
  }

  // 连续方向：正常移动覆盖最大幅度的约 80%，极端移动再软扩展到 OLED 边缘。
  float magnitude = fabsf(delta);
  float normal_part = constrain(magnitude / LOOK_NORMAL_INPUT, 0.0f, 1.0f);
  float extreme_part = constrain(
    (magnitude - LOOK_NORMAL_INPUT) /
      (LOOK_EXTREME_INPUT - LOOK_NORMAL_INPUT), 0.0f, 1.0f);
  float look_magnitude = normal_part * LOOK_NORMAL_PX +
                         extreme_part * (LOOK_MAX_PX - LOOK_NORMAL_PX);
  // 方向约定（parse 取反后成立）：r50_x 偏左为负 → delta<0 = 人在左手边 → look 为负，眼睛/鼻子朝左。
  model_a_direction = (delta < 0.0f ? -1.0f : 1.0f) * look_magnitude;
  if (fabsf(delta) < LOOK_DEADZONE_MM) {
    model_a_direction = 0.0f;
  } else if (model_a_position == POS_CENTER && fabsf(delta) < POSITION_EXIT_PX) {
    model_a_direction *= fabsf(delta) / POSITION_EXIT_PX;
  }

  if (model_a_position != model_a_previous) {
    model_a_previous = model_a_position;
    if (Serial && Serial.availableForWrite() > 64) {
      Serial.printf("POS,%lu,%s,delta=%.0f,look=%.1f\n",
        millis(), positionClassName(model_a_position), delta, model_a_direction);
    }
  }
}

void mlPushSample() {
  MlSample &s = ml_ring[ml_head];
  s.t = r50_last;
  s.x = r50_x;
  s.y = r50_y;
  s.v = r50_v;
  s.es = (uint16_t)constrain(r10_es, 0, 65535);
  ml_head = (ml_head + 1) % ML_RING_CAP;
  if (ml_count < ML_RING_CAP) ml_count++;
}
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
void loop() {
  uint32_t loop_start = millis();
  if (last_loop_ms != 0) {
    uint32_t gap = loop_start - last_loop_ms;
    if (gap > max_loop_gap_ms) max_loop_gap_ms = gap;
  }
  last_loop_ms = loop_start;

  handleCommand();
  updatePower();   // 深度省电：决定雷达/屏幕供电状态（红外独守唤醒）
  readSensors();
  updateTinyML();
  updateState();
  updateAnimation();

  uint32_t now = millis();
  uint16_t disp_ms = (state == HM_SLEEP) ? 500 : DISPLAY_MS;   // 睡眠画面变化极慢：2Hz 刷新足够（替代 CPU 降频的省 CPU 手段）
  if (now - last_display >= disp_ms) {
    last_display = now;
    drawFace();
  }

  // 保留轻量日志，方便初版装壳后的现场验证。
  static uint8_t radar_skip = 0;
  if (Serial && debug_overlay && ++radar_skip >= 2 && Serial.availableForWrite() > 120) {   // 非调试模式不打雷达流：USB+CPU 常驻开销
    radar_skip = 0;
    Serial.printf("RADAR,%lu,%d,%d,%d,%d,%d,%d,%d,%d\n",
      now, r50_ok ? r50_x : 0, r50_ok ? r50_y : 0,
      r50_ok ? r50_v : 0, r10_em, r10_es,
      r50_ok ? 1 : 0, targetPresent() ? 1 : 0, ir_present ? 1 : 0);
  }
  uint32_t anim_log_ms = debug_overlay ? DEBUG_ANIM_LOG_MS : 1000;
  if (now - last_state_log >= anim_log_ms) {
    last_state_log = now;
    if (Serial && Serial.availableForWrite() > 100) {
      Serial.printf("ANIM,%lu,%s,look=%.1f,x=%.0f,y=%.0f\n",
        now, stateName(state), face_look, flt_x, flt_y);
    }
  }

  // 用低频诊断区分“主循环停了”和“某次 OLED/I²C 刷新变慢”。
  if (now - last_diag_log >= 2000) {
    last_diag_log = now;
    if (Serial && Serial.availableForWrite() > 120) {
      Serial.printf("DIAG,%lu,loopMax=%lu,drawLast=%lu,drawMax=%lu,drawSlow=%lu\n",
        now, max_loop_gap_ms, last_draw_ms, max_draw_ms, slow_draw_count);
    }
    max_loop_gap_ms = 0;
    max_draw_ms = 0;
    slow_draw_count = 0;
  }
  delay(10);
}

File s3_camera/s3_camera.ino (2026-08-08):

// ============================================================
//  HappyMac — s3_camera.ino
//  ESP32-S3 摄像头固件（Teacher 视觉源）
//
//  端点：
//    /           首页（设备信息 + 实时预览）
//    /stream     MJPEG 视频流（collect.py 主输入）
//    /capture    单张 JPEG（调试用，浏览器直接打开或 wget）
//    /status     JSON 状态（帧率/分辨率/WiFi 信号）
//    /control    参数调节（quality/framesize/brightness...）
//
//  使用：
//    1. 改下面的 WIFI_SSID / WIFI_PASS
//    2. 选板子（默认 ESP32-S3-EYE，其他板子改 BOARD 宏）
//    3. 烧录，打开串口看 IP，浏览器访问 http://<IP>
//
//  依赖：Arduino ESP32 Core + esp32-camera 库
// ============================================================

#include "esp_camera.h"
#include <WiFi.h>
#include <WebServer.h>
#include <ESPmDNS.h>

// ─── WiFi ──────────────────────────────────────────
const char* WIFI_SSID = "********";
const char* WIFI_PASS = "********";

// ─── 板子选择 ──────────────────────────────────────
// 取消注释你用的板子
#define BOARD_ESP32S3_EYE
// #define BOARD_XIAO_ESP32S3_SENSE
// #define BOARD_FREENOVE_ESP32S3_CAM

// ─── 摄像头参数 ────────────────────────────────────
#define CAM_FRAME_SIZE  FRAMESIZE_SVGA   // 800x600
#define CAM_JPEG_QUALITY 12              // 0-63, 越小画质越高
#define CAM_FB_COUNT     2               // 帧缓冲数

// ─── 服务端口 ──────────────────────────────────────
#define HTTP_PORT  80

// ╔══════════════════════════════════════════════════╗
// ║  板子引脚定义（一般不需要改）                       ║
// ╚══════════════════════════════════════════════════╝

#if defined(BOARD_ESP32S3_EYE)
  #define PWDN_GPIO_NUM  -1
  #define RESET_GPIO_NUM -1
  #define XCLK_GPIO_NUM  15
  #define SIOD_GPIO_NUM  4
  #define SIOC_GPIO_NUM  5
  #define Y9_GPIO_NUM    16
  #define Y8_GPIO_NUM    17
  #define Y7_GPIO_NUM    18
  #define Y6_GPIO_NUM    12
  #define Y5_GPIO_NUM    10
  #define Y4_GPIO_NUM    8
  #define Y3_GPIO_NUM    9
  #define Y2_GPIO_NUM    11
  #define VSYNC_GPIO_NUM 6
  #define HREF_GPIO_NUM  7
  #define PCLK_GPIO_NUM  13
  #define LED_GPIO_NUM   48   // 板载 LED（有些版本没有）

#elif defined(BOARD_XIAO_ESP32S3_SENSE)
  #define PWDN_GPIO_NUM  -1
  #define RESET_GPIO_NUM -1
  #define XCLK_GPIO_NUM  10
  #define SIOD_GPIO_NUM  40
  #define SIOC_GPIO_NUM  39
  #define Y9_GPIO_NUM    48
  #define Y8_GPIO_NUM    11
  #define Y7_GPIO_NUM    12
  #define Y6_GPIO_NUM    14
  #define Y5_GPIO_NUM    16
  #define Y4_GPIO_NUM    18
  #define Y3_GPIO_NUM    17
  #define Y2_GPIO_NUM    15
  #define VSYNC_GPIO_NUM 38
  #define HREF_GPIO_NUM  47
  #define PCLK_GPIO_NUM  13
  #define LED_GPIO_NUM   21

#elif defined(BOARD_FREENOVE_ESP32S3_CAM)
  #define PWDN_GPIO_NUM  -1
  #define RESET_GPIO_NUM -1
  #define XCLK_GPIO_NUM  15
  #define SIOD_GPIO_NUM  4
  #define SIOC_GPIO_NUM  5
  #define Y9_GPIO_NUM    16
  #define Y8_GPIO_NUM    17
  #define Y7_GPIO_NUM    18
  #define Y6_GPIO_NUM    12
  #define Y5_GPIO_NUM    10
  #define Y4_GPIO_NUM    8
  #define Y3_GPIO_NUM    9
  #define Y2_GPIO_NUM    11
  #define VSYNC_GPIO_NUM 6
  #define HREF_GPIO_NUM  7
  #define PCLK_GPIO_NUM  13
  #define LED_GPIO_NUM   -1   // 无板载 LED

#else
  #error "请选择一个板子（取消注释上面的 #define BOARD_xxx）"
#endif

// ╔══════════════════════════════════════════════════╗
// ║  HTTP 服务器 + MJPEG 推流                         ║
// ╚══════════════════════════════════════════════════╝

WebServer server(HTTP_PORT);

// 帧率统计
static unsigned long last_frame_ms = 0;
static float current_fps = 0;
static unsigned long frame_count = 0;

// ─── HTML 首页 ─────────────────────────────────────
const char INDEX_HTML[] PROGMEM = R"rawliteral(
<!DOCTYPE html>
<html>
<head>
<meta charset="utf-8">
<meta name="viewport" content="width=device-width,initial-scale=1">
<title>HappyMac S3 Camera</title>
<style>
  body{font-family:system-ui;max-width:840px;margin:auto;padding:1em;background:#111;color:#eee}
  img{width:100%;max-width:800px;border-radius:8px}
  .info{display:flex;gap:2em;flex-wrap:wrap;margin:1em 0}
  .info span{background:#222;padding:.4em 1em;border-radius:6px;font-family:monospace}
  a{color:#4af}
</style>
</head>
<body>
<h1>📷 HappyMac S3 Camera</h1>
<div class="info">
  <span id="status">...</span>
  <span id="fps">-- fps</span>
</div>
<img id="stream" src="/stream" alt="MJPEG Stream">
<p>端点：<a href="/stream">/stream</a> · <a href="/capture">/capture</a> · <a href="/status">/status</a></p>
<script>
  fetch('/status').then(r=>r.json()).then(d=>{
    document.getElementById('status').textContent=d.resolution+' Q'+d.quality
  })
</script>
</body>
</html>
)rawliteral";

// ─── MJPEG 流 ──────────────────────────────────────
static const char* STREAM_BOUNDARY = "\r\n--frame\r\n";
static const char* STREAM_HEADER  = "Content-Type: image/jpeg\r\nContent-Length: %u\r\n\r\n";

void handleStream() {
  WiFiClient client = server.client();
  client.println("HTTP/1.1 200 OK");
  client.println("Content-Type: multipart/x-mixed-replace; boundary=frame");
  client.println("Access-Control-Allow-Origin: *");
  client.println();

  unsigned long last = millis();
  while (client.connected()) {
    camera_fb_t* fb = esp_camera_fb_get();
    if (!fb) { delay(10); continue; }

    client.print(STREAM_BOUNDARY);
    client.printf(STREAM_HEADER, fb->len);
    client.write(fb->buf, fb->len);

    frame_count++;
    unsigned long now = millis();
    if (now - last >= 1000) {
      current_fps = frame_count * 1000.0f / (now - last);
      frame_count = 0;
      last = now;
    }

    esp_camera_fb_return(fb);
  }
}

// ─── 单张截图 ──────────────────────────────────────
void handleCapture() {
  camera_fb_t* fb = esp_camera_fb_get();
  if (!fb) {
    server.send(500, "text/plain", "Camera capture failed");
    return;
  }
  server.sendHeader("Access-Control-Allow-Origin", "*");
  server.send_P(200, "image/jpeg", (const char*)fb->buf, fb->len);
  esp_camera_fb_return(fb);
}

// ─── JSON 状态 ─────────────────────────────────────
void handleStatus() {
  sensor_t* s = esp_camera_sensor_get();
  char json[256];
  snprintf(json, sizeof(json),
    "{"
    "\"board\":\"%s\","
    "\"resolution\":\"%dx%d\","
    "\"quality\":%d,"
    "\"fps\":%.1f,"
    "\"wifi_rssi\":%d,"
    "\"free_heap\":%u,"
    "\"uptime_s\":%lu"
    "}",
    "ESP32-S3",
    s->status.framesize,
    s->status.framesize,
    s->status.quality,
    current_fps,
    WiFi.RSSI(),
    ESP.getFreeHeap(),
    millis() / 1000
  );
  server.sendHeader("Access-Control-Allow-Origin", "*");
  server.send(200, "application/json", json);
}
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

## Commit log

2026-05-05 Add ESP32 CameraWebServer example
    Add a complete ESP32 camera web server example. Adds main sketch (CameraWebServer.ino) and HTTP server implementation (app_httpd.cpp) with capture/stream/status/control endpoints, JPEG/BMP handlers, 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
    [partitions.csv]
2026-05-05 更新 .gitattributes
2026-05-05 fix: exclude CameraWebServer from GitHub language stats via .gitattributes
    Agent-Logs-Url: https://github.com/cchengoran525/HappyMac/sessions/1a4f979d-cffa-4173-b242-ee1097e5fcc7
2026-08-04 fix: LD2450 sign convention, add EMA filter, zone detection, trend arrows
    - Fix X/Y/V sign decoding: bit15=1→positive (was reversed)
    - Add EMA filter (α=0.3) for smooth coordinate display
    - Add Left/Center/Right zone detection (±200mm thresholds)
    - Add trend arrow (← → ·) from frame-delta EMA
    - Support all 3 LD2450 target slots with best-slot selection
    - OLED: large filtered coords, zone+trend+IR status bar, overhead map
    - Serial CSV output ready for TinyML data collection
    - Remove dead LD2450 config commands (256000 baud can't send 115200 frames)
    - Remove LD2410C from this version (mutual interference with 2450)
    - Document LD2450 X-axis distance-dependent accuracy limitation
    - Upda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
    [new_radar.ino]
2026-08-05 feat: TinyML pipeline + dual-radar firmware + known limitations
    C3 firmware (new_radar.ino):
    - Dual-radar simultaneous sampling (LD2450 + LD2410C)
    - Clean RADAR CSV output: ms,x,y,v,em,es,d2410,pres,ir
    - OLED status display (EMA coords + sensor summary)
    TinyML training pipeline (training/):
    - config.py: centralized config (18 features, 2 window lengths,
    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
2026-08-05 docs: 11 research questions across 3 directions appended to training/README
    Direction 1 — Sensing Systems (4 RQs):
    RQ1.1 LD2450 X-axis precision vs distance function
    RQ1.2 LD2410C Es sensitivity to target orientation
    RQ1.3 Event-Related Radar Response to attention shifts
    RQ1.4 Dual 24GHz FMCW co-frequency interference quantification
    Direction 2 — Cross-modal Distillation (4 RQs):
    RQ2.1 Vision Teacher ceiling for attention state classification
    RQ2.2 Decomposing information loss: modality gap vs quantization
    RQ2.3 Feature ablation — which 18 features actually matter
    RQ2.4 MLP inference latency and power on ESP32-C3
    Direction 3 — HCI/Design (4 RQs):
    RQ3.1 Attention-O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
2026-08-07 feat: clean S3 camera firmware, replace old CameraWebServer
    s3_camera/s3_camera.ino:
    - Clean single-file firmware for ESP32-S3 camera
    - Supports 3 boards (ESP32-S3-EYE / XIAO S3 Sense / Freenove)
    - Endpoints: / /stream /capture /status /control
    - MJPEG stream with CORS headers (ready for collect.py)
    - JSON status (resolution/fps/WiFi RSSI/heap)
    - mDNS support (happymac.local)
    - Auto-fallback to AP mode if WiFi fails
    - Frame rate counter, LED status indicator
    [s3_camera.ino]
2026-08-07 feat: radar benchmark script + S3 camera firmware
    radar_bench.py:
    - 3-config × 4-phase radar signal characterization
    - Dual-radar interference comparison (both/2450-only/2410C-only)
    - JSON output with X/Y/Em/Es statistics per phase
    - Auto countdown + phase prompts
    - Clean single-file ESP32-S3 camera firmware
    - MJPEG /stream, JPEG /capture, JSON /status, /control
    - 3 board profiles, mDNS, AP fallback, CORS headers
    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
    [radar_bench.py]
2026-08-08 feat: S3 camera AP mode, latency optimization, radar drift findings, test scripts
    - EMA alpha 0.3→0.55, OLED 100→80ms, loop 30→20ms
    → end-to-end latency ~530→~400ms
    - Non-blocking serial output (skip when USB buffer full)
    - OLED phase commands (!PHASE:name,countdown / !GO / !DONE)
    - 2-radar CSV output (RADAR format)
    S3 firmware (s3_camera.ino):
    - Always-AP mode (HappyMac-S3 / 12345678), no WiFi connect needed
    - LED status codes (boot/cam ok/cam fail/AP mode)
    - ESP32-S3-EYE: FlashSize=16M, PSRAM=opi, CDCOnBoot=cdc
    - Note: ESP32-S3-EYE USB serial doesn't output — use WiFi
    Test scripts (training/):
    - s3_test.py: S3 MJPEG stream + C3 radar sync record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
    [cam_test.py, config.py, full_test.py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]
2026-08-08 docs: document LD2450 rotation vs translation sensitivity + glasses hypothesis
    - Head turn Xσ=111mm vs lateral lean Xσ=55mm (2x difference)
    - Hypothesis: RCS phase center shifts from chest to shoulder during rotation
    - TODO: retest without glasses/headphones to isolate metallic reflector effects
    - Note: undocumented in LD2450 community and academic literature
2026-08-09 feat: correct radar orientation verification, SYNC handshake, Em sensitivity tuning
    C3 firmware:
    - LD2410C sensitivity: gates 0-3 set to 80/80 (moving/stationary)
    - Em/Es read independently of detection flags (always report both)
    - Active SYNC handshake: respond to !SYNC command with timestamp
    - OLED X mirroring for intuitive left/right display
    - Cleaned up: removed adaptive filter, back to simple EMA (a=0.55)
    collect_session.py:
    - Active SYNC: sends !SYNC to C3, waits for timestamp reply
    - Fixed cv2.resize bug (wasn't assigning back, video was 257 bytes)
    - Timestamps now relative to SYNC handshake point
    analysis scripts:
    - analyze_session.py: 6-figure radar analysis pipeline
    - analyze_vis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
    [session_20260809_150202.csv, session_20260809_152221.csv, session_20260809_152710.csv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]
2026-08-13 feat: 3-session formal experiment, wall-clock alignment, MiDaS depth validation, academic report
    Data (3 official sessions):
    - session_20260813_160414 / 165801 / 170609
    - 9 behavior phases each, free_5min excluded (truncated)
    - Radar CSV + S3 video + per-frame wall-clock timestamps
    Analysis pipeline:
    - analyze_all.py: multi-session whitelist aggregation (mean±sd)
    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
    [session_20260813_160001.csv, session_20260813_160001_vidts.csv, session_20260813_160414.csv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]
2026-08-13 feat: TinyML T1b — vision Teacher auto-labeling, 5-class RF training, key findings
    Data:
    - Free session (5min): vision Teacher auto-labels (MediaPipe presence+lateral,
    MiDaS depth approach/retreat), manual override keys
    - Fused with 3 protocol sessions
    Feature engineering (features_t1b.py):
    - Fixed X features: removed slope_X (direction cancels), slope2_X (zero
    variance), X_reversals (threshold never fires)
    - Added |slope_X| — protocol F1 0.537→0.708
    - 9 features total, label smoothing for free session
    Training comparison (train_compare_t1b.py):
    - Protocol-only: acc=0.778, F1=0.708
    - Free-only: acc=0.681, F1=0.625
    - Fused→free test: acc=0.811, F1=0.765
    - Transfer test protocol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
    [session_20260813_200450_free.csv, session_20260813_200450_free_labels.csv, session_20260813_200450_free_vidts.csv]
2026-08-13 docs: dual-model architecture — position (Model A) + state (Model B) with animation layer
    - Model A: 3-feature position classifier (X_rel rolling baseline,
    |slope_X|, std_X) for LEFT/CENTER/RIGHT soft output
    - Drift immunity: rolling baseline normalization; vision Teacher
    calibration protocol (10s center reference per session)
    - Camera-radar geometry offset: labels relative to calibrated
    reference point, not image center
    - Animation layer: smooth interpolation (alpha easing), physical
    angle limits, parallax layering (nose/eye/mouth different alphas)
    - Design principles: continuous pose space not hard boundaries;
    imperfection as character (Paper 3 argument made concrete)
    - Arbitra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
2026-08-30 feat: fix false-smile flapping and add bedtime transition chain
    - motion detection: per-frame evidence integrator with schmitt trigger
    (replaces single-frame hard thresholds sitting inside static noise band)
    - Y-trend approach/retreat: trigger raised above noise band + re-arm
    hysteresis (no more chained events)
    - TinyML: confirm window 900->2000ms, v feature noise floor 8mm/s,
    rule-motion corroboration escape from ML STILL verdict
    - smile: 600ms enter delay + 1.5s minimum hold
    - bedtime chain (one-shot event system): absent 2.5s -> yawn -> rub
    eyes -> dim ramp -> sleep, interruptible anytime
    - offline eval on 11 real sessions: false-smile 32.5% -> 16.6%
    [happymac_v0.ino]
2026-08-30 feat: add firmware-faithful OLED simulator with offline eval harness
    - happymac_sim.html: 1:1 JS port of firmware logic (state machine,
    motion integrator, Y-trend arming, TinyML tree, animation layer,
    event system), 128x64 proportional OLED, single-file no deps
    - radar noise model calibrated from real measurements (15Hz, AR(1)
    slow drift, v glitch spikes on multiples of 8)
    - inputs: manual drag / scripted scenarios / CSV replay of real sessions
    - test_sim.js: 16 headless assertions (fixed seed)
    - eval_replay.js: replay real session CSVs, score firmware state vs
    ground-truth action labels; --sweep/--floor/--confirm/--deglitch knobs
2026-08-30 feat: V2 collection spec, head-turn separability experiment, tree export
    - DATA_COLLECTION_V2.md: post-assembly formal collection spec (workflow,
    content, quality gates, acceptance chain) derived from V1 data audit
    - exp_head_separability.py: head-turn learnability test on current
    features (verdict: not learnable until 2410 retune + 3-target logging)
    - export_tree.py: pkl -> C header + JS predict export tool
    - t1b_aligned feature artifacts + training README pointer
2026-09-30 feat: firmware v0.1 — expression system, phased power saving, enclosure docs
    - 像素脸表情系统：眉/眼/嘴形态化 + 冷却机制（wink/好奇/开心/皱眉）
    - 四阶段深度省电：互动→睡眠→90s断雷达红外独守→关屏/30min深度睡眠（PIR唤醒）
    - 榫卯零螺丝外壳设计定稿：接线清单 + 元件尺寸台账（10元件实测）
    - 模拟器同步：表情/电源相位/0.10公差体系
    - 研究线（实验脚本/论文/模型缓存）加入 .gitignore，不上传
2026-10-01 feat: ghost-presence gate, idle-drowsy dim, tuned sleep timings; add v0.1 enclosure STL
    - LD2410 presence now gated by energy (moving>=15 / stationary>=20):
    empty-room noise floor (es 8~10) no longer counts as someone, which
    used to wake the sleeping device with nobody around
    - new DROWSY stage: person present but 5min motionless -> 5s ramp dim
    to contrast 45, radar stays powered; any motion / PIR blip restores
    - timings: drowsy 10min->5min, deep sleep 30min->20min (rest unchanged)
    - simulator mirrored 1:1; regression suite 22/22 (2 new scenarios)
    - docs refreshed; hardware/happymac_v01.stl added (snap-fit enclosure)
    [happymac_v01.stl]
2026-10-02 feat: dual face styles — classic (default) & glasses friend (!STYLE)
    - classic (new default, adapted from the very first build): no glasses,
    original long L-nose, wide flat mouth / original smile; eyebrows only
    during special actions (smirk raised-brow, approach surprise, goodbye)
    drawn as 1px lines + shallow arcs
    - friend style = current full face (U-cup glasses, m-brows, J-nose),
    preserved and switchable
    - !STYLE serial command toggles + persists in NVS (like !FLIP)
    - simulator: face-style toggle checkbox, renderFace branches, smoke
    test for both styles; suite 27/27
    [happymac_v0.ino]
